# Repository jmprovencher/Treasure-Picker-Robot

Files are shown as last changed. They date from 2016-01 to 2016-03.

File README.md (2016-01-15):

Dépot cool de l'équipe cool.
J'propose le nom "Zière" parce que c'est qu'il faut rester zen pis la bière ça aide. C'est non négotiable jusqu'à ce que quelqu'un modifie le README.

Jusqu'à contre indication, rajoutez vos textes dans votre dossier personnel afin d'éviter les chiages de merge. Ça devrait nous permettre de rester zen pendant au moins une semaine.

Tâches actuelles:
> recherche sur pas mal tout le matériel à utiliser
> créer le GANTT

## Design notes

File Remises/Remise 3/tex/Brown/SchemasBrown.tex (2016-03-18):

\section{Circuit d'alimentation}
\label{s:Alimentation}

\section{Circuit d'amplification du code Manchester}
\label{s:Manchester}

%\begin{figure}[htp]
%   \centering
%   \includegraphics[width=0.85\textwidth]{fig/Manchester.png}
%   \caption{Circuit d'amplification des signaux du code Manchester}
%   \label{f:Manchester}
%\end{figure}

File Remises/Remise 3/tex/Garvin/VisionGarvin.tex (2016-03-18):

%Exemple d'insertion de figure

%\begin{figure}[htp]
%   \centering
%   \includegraphics[width=1\textwidth]{fig/trajet.png}
%   \caption{Exemple de trajectoire}
%   \label{f:Trajectoire}
%\end{figure}
%\pagebreak

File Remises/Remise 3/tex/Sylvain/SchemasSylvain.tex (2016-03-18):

\section{Station de recharge}
\label{s:Recharge}

\section{Circuit de charge et de décharge du condensateur}
\label{s:Condensateur}

\section{Circuit de connections pour les moteurs}
\label{Connections}

\subsection{Connections moteurs et pont en H}
\label{Moteurs}

\subsection{Connections sur l'Arduino}
\label{Arduino}

%\begin{figure}[htp]
%   \centering
%   \includegraphics[width=0.85\textwidth]{fig/Manchester.png}
%   \caption{Circuit d'amplification des signaux du code Manchester}
%   \label{f:Manchester}
%\end{figure}

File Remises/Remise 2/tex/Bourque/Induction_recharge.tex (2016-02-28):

L’électroaimant est alimenté par un condensateur. Ce dernier est rechargé par un transformateur. Le primaire du transformateur est situé sur la station de recharge sur le bord de la table. Il est alimenté par la tension DC de 5V/3A qui provient du circuit fournissant aussi le signal Manchester. Le transformateur ne fonctionnant qu’en AC, il est nécessaire de hacher cette tension DC. 
\medbreak
Plusieurs méthodes existent pour hacher une tension DC. Il fut choisi d’utiliser un simple MOSFET de puissance dans lequel la base est commandée par une horloge. Ce choix a été fait pour sa simplicité. Il est en effet beaucoup plus simple à implémenter qu'un pont en H. Également, avec un seul MOSFET, les pertes par dissipation dans les MOSFETs sont limitées. L'horloge provient d'un microprocesseur PIC situé également sur la station de recharge. Différentes fréquences ont été testées pour ce hacheur. Les fréquences inaudibles (plus de 20kHz) sont plus intéressantes, car notre oreille ne peut pas les entendre et le transformateur n'est donc pas bruyant. Toutefois, à ces fréquences, l'effet inductif des bobines du transformateur devient très grand et réduit le courant qui traverse le transformateur. 
\medbreak
Comme un plus grand courant dans le transformateur équivaut à une recharge plus rapide du condensateur, une fréquence de 4kHz a été choisie. C'est à cette fréquence que l'effet inductif des bobines du transformateur devient assez faible pour laisser passer un courant dans le transformateur assez grand pour avoir une recharge rapide du condensateur. De plus, si on descend à une fréquence plus basse que 4kHz, l'effet inductif du transformateur devient très faible; un courant trop élevée y circule et les deux bobines s'attirent fortement par aimantation. C'est pourquoi la fréquence de 4kHz est choisie.
\medbreak
Toutefois, un condensateur ne peut être rechargé par une tension alternative. C'est pourquoi au secondaire se trouve un redresseur. Des tests ont été faits afin de choisir entre un redresseur simple alternance ou double alternance. Le redresseur double alternance a été choisi, parce qu'il est plus efficace.
\medbreak
Le condensateur choisi est un condensateur de 5F. Avec notre système d'induction, il est possible de charger ce condensateur jusqu'à 5V. Des tests ont été faits avec ce condensateur et ont permis de déterminer qu'à partir de sa pleine charge, il est capable d'alimenter notre électroaimant avec le courant nécessaire pour tenir un trésor pendant 3 minutes 30 secondes, ce qui est amplement suffisant pour le projet.
\medbreak
Finalement, un interrupteur électronique est utilisé pour ouvrir le circuit de recharge lorsque la recharge est complétée; sans cela, un faible courant de fuite circule dans le pont redresseur et décharge lentement le condensateur. La figure \ref{f:Borne} présente le schéma électrique du système implanté sur le robot.

\begin{figure}[htp]
   \centering
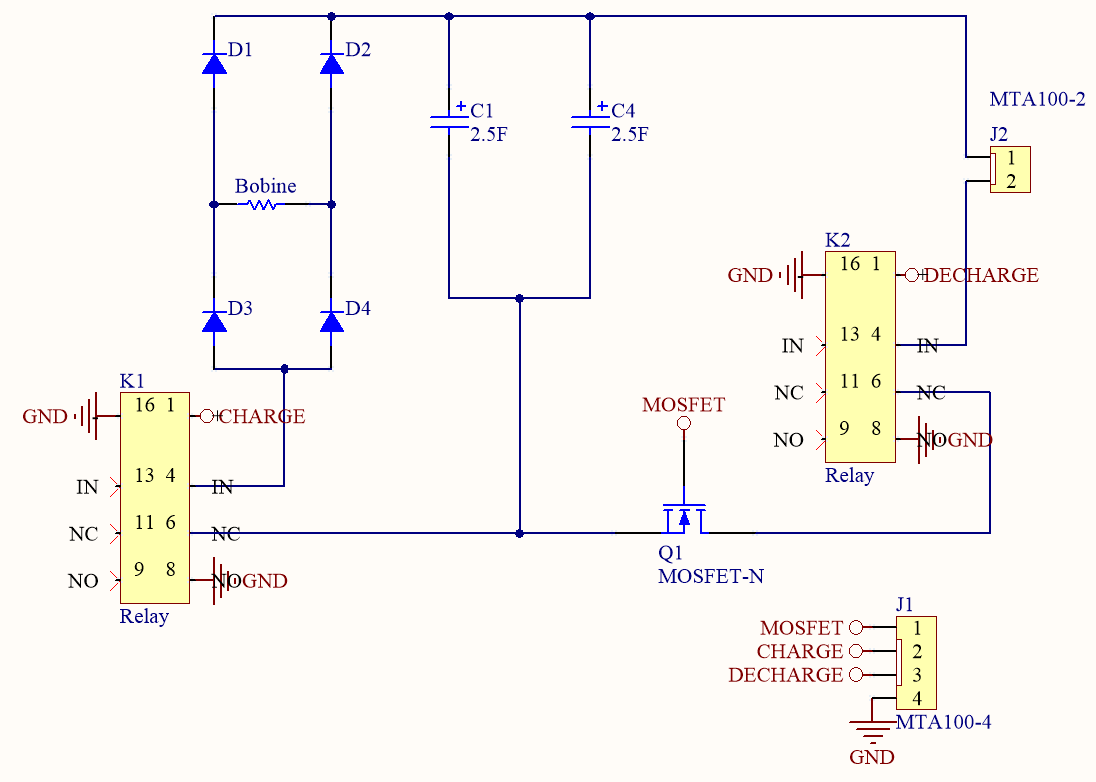
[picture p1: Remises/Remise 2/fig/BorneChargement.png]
   
   \caption{Circuit de chargement et décharge du condensateur}
   \label{f:Borne}
\end{figure}

\pagebreak

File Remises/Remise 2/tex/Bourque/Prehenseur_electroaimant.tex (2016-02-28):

Le préhenseur est constitué d'un électroaimant situé sur un bras mécanique. Cet électroaimant est alimenté par le condensateur de 5F. Lorsqu'un courant circule dans l'électroaimant, il produit une force d'attraction des trésors. Afin de conserver l’énergie dans le condensateur le plus longtemps possible, le courant de décharge dans l’électroaimant doit être limité. En effet, sans cela, le condensateur se déchargera extrêmement rapidement dans l'aimant, car sa résistance interne est de 12 ohms. L'électroaimant est acheté afin de s'assurer d'avoir une bonne efficacité de ce système et d'éviter la tâche d'en concevoir un \cite{PRE00}.
\medbreak
Afin de limiter ce courant, nous utilisons un MOSFET dans lequel nous envoyons une onde carré de largeur d’impulsion variable dans sa base et permet de contrôler ce courant. Un fort courant doit d'abord être envoyé dans l'aimant afin d'attirer le trésor. Ensuite, le circuit magnétique est fermé et un courant plus faible peut donc être envoyé. Cette façon de procéder est donc utilisée afin de conserver l'énergie du condensateur plus longtemps.
\medbreak
Également, le système comprend un interrupteur électronique afin de permettre de couper la décharge de courant dans l’électroaimant lorsque le déplacement vers l'île cible est terminé. En ouvrant l’interrupteur, il n'y a plus de courant dans l'électroaimant et la force qui permet de tenir le trésor est éliminée. Le trésor tombe ainsi sur l'île voulue.

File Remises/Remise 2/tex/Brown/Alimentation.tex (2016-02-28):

Un circuit imprimé est conçu pour assurer un accès facile aux différents niveaux de tensions requis par le robot. Ce circuit comprend donc les deux régulateurs nécessaires pour le 12V, le régulateur pour les circuits fonctionnant à 5V ainsi que le régulateur 19V pour le mini PC. Les deux régulateurs utilisés pour le 12V sont le même modèle que celui utilisé pour le 5V. Le régulateur en question est un hacheur série dévolteur DC-DC avec un voltmètre intégré qui a une précision de $\pm$ 0.05V \cite{ALI01}. Il nécessite 4V à 38V en entré et peut fournir 1.35V à 36V en sortie avec un courant maximum de 5A et son efficacité peut atteindre 96\%. De plus, il possède une protection intégrée contre la surchauffe et les courts-circuits. Les autres régulateurs considérés pour le robot ne pouvaient fournir que 3A et ils coûtaient environ le même prix, c'est cette raison qui a fait pencher le choix vers ce régulateur. Le voltmètre intégré qui affiche la tension d'entrée ou de sortie n'était pas un critère, mais puisque ce n'est pas encombrant, c'est seulement un avantage. 
\medbreak
La batterie choisie est une LiPO 6S à 4.5Ah de Turnigy \cite{ALI00}. Le choix s'est arrêté sur une 6S pour avoir 22.2V en moyenne, car il est nécessaire d'avoir au moins 21V pour alimenter le régulateur du mini PC. De plus, il fut précédemment calculé que le robot avait besoin d'environ 110W pendant le 10 minutes imposé pour la compétition, mais il était préférable d'avoir au moins 30 minutes d'autonomie pour faciliter les tests. Le choix s'est arrêté sur une batterie de 4.5Ah, ce qui donne 600W, pour environ 50 minutes d'autonomie. Le choix de prendre deux batteries pour effectuer plus de tests sans recharge fut considéré, mais un problème de livraison et d'importation avec le fournisseur a éliminé cette option.
\medbreak
La figure \ref{f:alim2} présente le schéma électrique du circuit d'alimentation. On peut y remarquer les protections électriques sous forme de fusibles ce qui permet de protéger nos appareils.

\begin{figure}[htp]
   \centering
   
   \caption{Schéma électrique du circuit imprimé}
   \label{f:alim2}
\end{figure}
\pagebreak

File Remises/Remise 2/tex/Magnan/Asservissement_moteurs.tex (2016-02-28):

Afin de contrôler les roues, la première étape est d'alimenter correctement chacun des moteurs des roues. Le pont en H connecté aux moteurs nécessite trois entrées par roue: deux entrées servent à sélectionner la direction des roues, et une troisième reçoit un PWM déterminant la vitesse de rotation de la roue.
\medbreak
Le pont en H est alimenté à l'aide d'une alimentation 5V provenant du système d'alimentation. Les encodeurs des roues en tant que tels doivent par contre être alimentés à une tension entre 3.5 et 20V et sont donc alimentés par la même source. Selon les spécifications du pont en H, la pin 1 de chaque moteur doit recevoir une tension faible et la pin 2 une tension élevée pour tourner la roue associée dans le sens des aiguilles d'une montre. Afin de tourner dans le sens inverse, il faut alors utiliser une tension élevée sur 1 et faible sur 2. Un des premiers tests est alors effectué, avec le pont en H alimenté et les quatre roues à pleine vitesse. À l'aide de ce test, il fut facile de voir que le branchement des roues de même orientation devrait être de deux sens opposés, car le sens des aiguilles signifie une rotation différente d'un côté à l'autre du robot.
\medbreak
Par la suite, en utilisant des sorties PWM de l'Arduino Mega, des ondes carrées à rapport cyclique de 50\% sont envoyées en sortie. Celles-ci, lorsque connectées aux entrées de vitesse correspondant aux quatre moteurs dans le pont en H, permettent de comparer la vitesse des moteurs et de vérifier si celle-ci est constante. Résultat de ce test: en activant deux roues à la fois, le robot ne va pas en ligne droite. Le moteur 1 fait tourner la roue significativement plus rapidement que le moteur 3 avec la même commande. Un asservissement avec intégrateur est donc absolument nécessaire afin que la vitesse de chaque roue rejoigne la consigne, permettant au robot de rouler en ligne droite.
\medbreak
La libraire PID disponible sur le Playground Arduino permet de rapidement implémenter un asservissement avec une fréquence d’échantillonnage, une commande à rejoindre et des paramètres kp, ki et kd définis par l'utilisateur. Pour implémenter la commande à rejoindre, les encodeurs des moteurs sont branchés directement à des entrées numériques du microcontrôleur Arduino. En effet, ceux-ci génèrent une onde carrée à largeur variable, celle-ci pouvant être lue en utilisant la fonction pulseIn(). La durée de lecture maximale (timeout) de la largeur d'impulsion est à la base très lente, environ une seconde par lecture, ce qui rend l'asservissement peu efficace si le robot tourne lentement. Pour remédier à cette situation, un timeout de 3 ms a été choisi.
\medbreak
Avec pulseIn, lorsque aucune onde n'est détectée avant la fin du temps maximal, une valeur de 0 est retournée. Par contre, l'asservissement fonctionne avec un principe que lorsque la durée retournée par pulseIn est supérieure à la commande, il faut augmenter la sortie vers les moteurs. Afin d'assurer qu'une roue à l'arrêt ne soit pas considérée comme impossiblement rapide, une valeur de 0 est remplacée par la durée maximale de lecture, soit 3 ms.
\medbreak
Les tests initiaux de l'asservissement étaient peu fructueux. En effet, la sortie du PID variait beaucoup trop rapidement entre minimum et maximum, ne permettant que très peu de précision. Ceci était dû à un kp trop élevé, ce qui multipliait l'erreur bien au delà de la valeur maximale du paramètre du PWM, soit 255. En diminuant l'élément proportionnel kp à 0.0005 au lieu de 1, la variation cyclique due à un trop large dépassement est évitée. Le ki est présentement à 0.25 car il permet de rejoindre la consigne suffisamment rapidement sans créer de trop larges dépassements.

\begin{figure}[htp]
	\centering
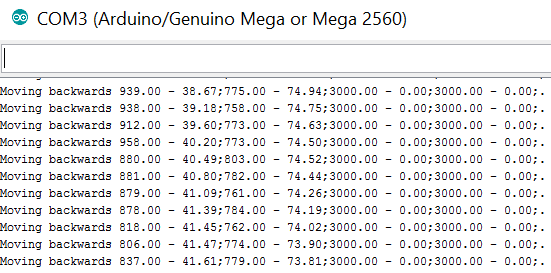
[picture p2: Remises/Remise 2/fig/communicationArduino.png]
	
	\caption{Test de rotation sur deux roues, commande à rejoindre de 800 microsecondes de largeur d'impulsion} 
	\label{f:test_Arduino}
\end{figure}

Dans l'état actuel de ce sous-système, il y a dépassement en vitesse de plus de 10\% pendant environ une seconde. Afin de permettre des déplacements plus précis, du travail sera fait pour diminuer ce dépassement. Pour communiquer à l'Arduino Mega la consigne à rejoindre, une interruption sur le port série est implémentée en utilisant serialEvent. Lorsque le port série détecte qu'il y a quelque chose à lire sur le port série, le code de lecture de la commande prend alors priorité sur l'exécution du PID.

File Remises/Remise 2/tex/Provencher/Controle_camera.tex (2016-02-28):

Le contrôle de la caméra embarquée s'effectue par des servomoteurs contrôlés par le Micro Maestro 6-Channel USB Servo Controller. Afin de simplifier les commandes nécessaires au contrôle de la position de la caméra, quatre positions prédéterminées ont été programmées : gauche, droite, avant, trésor. Comme ces quatre positions permettent de couvrir entièrement le champ de vision intéressant, il n'est pas nécessaire d'ajouter davantage de possibilités de contrôle de caméra. La position trésor correspond à la position avant dans laquelle la caméra regarde complètement vers le bas. Afin de déterminer ces positions, le logiciel Maestro Control Center a été utilisé pour noter les valeurs nominales de ces positions. Une fois les valeurs de position en main, une librairie Arduino a été développée afin de déplacer la position de la caméra dans ces différentes valeurs.
\medbreak
Pour communiquer entre le Arduino Mega 2560 et le contrôleur de servomoteur, une communication UART est établie afin de pouvoir envoyer les commandes de positions au contrôleur de servomoteur. Comme il n'est pas nécessaire de recevoir de l'information de la part du contrôleur de servomoteur, uniquement la branche TX du Arduino Mega est utilisée. Le contrôleur de servomoteur est également relié au module d'alimentation afin de fournir le courant nécessaire aux servomoteurs.

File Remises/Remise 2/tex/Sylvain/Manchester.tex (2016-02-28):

Le système de transmission retenu par l'équipe pour communiquer le signal Manchester est un système utilisant une LED comme émetteur et une autre LED comme récepteur. Ce système LED à LED est une solution simple et peu coûteuse qui ne présente donc pas un coût monétaire important pour le projet ni beaucoup de temps de travail. Pour décoder le code il est nécessaire de transmettre l'horloge ainsi que le code, le système est donc installé en double à cet effet. Chacun des signaux est transmis par un banque de quatre LED qui seront situées sur la station de recharge. L'utilisation de plusieurs diodes est justifiée pour rendre le système plus efficace en cas de défaillance d'une de celle-ci et donc d'ajouter de la redondance. Les LED en réception sont situées de chaque côté de la face avant du robot de manière à éviter les interférences. Encore une fois, la redondance est utilisée pour la réception et deux LED sont donc placées à cet effet.
\medbreak
L'horloge fournit avec le dispositif du Manchester n'est pas utilisée car elle est jugée trop rapide, une horloge d'environ 1 à 2Hz est généré par un microcontrôleur PIC. Une fréquence plus élevée n'est pas requise dû au temps passé à recharger le condensateur, de plus, avec une basse fréquence le risque d'erreur est jugé moins élevé. Des LED rouges sont utilisées pour la transmission des signaux, après des expériences avec d'autres couleurs il fut remarqué que celles-ci offraient les meilleures performances.
\medbreak
Un circuit d'amplification des signaux situé sur le robot permet d'amplifier ceux-ci après réception et donc de produire des signaux 0 à 5V. Le schéma de ce circuit est présenté à la figure \ref{f:Manchester} et réalisé sur PCB conformément aux exigences. Les signaux amplifiés sont ensuite lu par des entrées numériques de l'Arduino Mega. La signal d'horloge est lu par une entrée permettant d'utiliser les interruptions tandis que le code Manchester est lu par une entrée ordinaire. Une interruption est lancée sur chaque front montant d'horloge, les deux données sont alors lues et on effectue une opération XOR sur les signaux afin d'obtenir le signal décodé. Ce résultat est ensuite stocké dans un buffer circulaire de 32 éléments, ce qui assure d'avoir au moins une itération de la séquence de 16 bits dans son ensemble. Un algorithme parcours ensuite ce tableau de données pour recherché la séquence de 8 bits à 1 suivit d'un bit à 0 pour finalement prendre les 7 bits d'intérêt composant la lettre ASCII voulue. Cette lettre est finalement transmise à l'ordinateur embarquée pour utilisation future.

\begin{figure}[htp]
   \centering
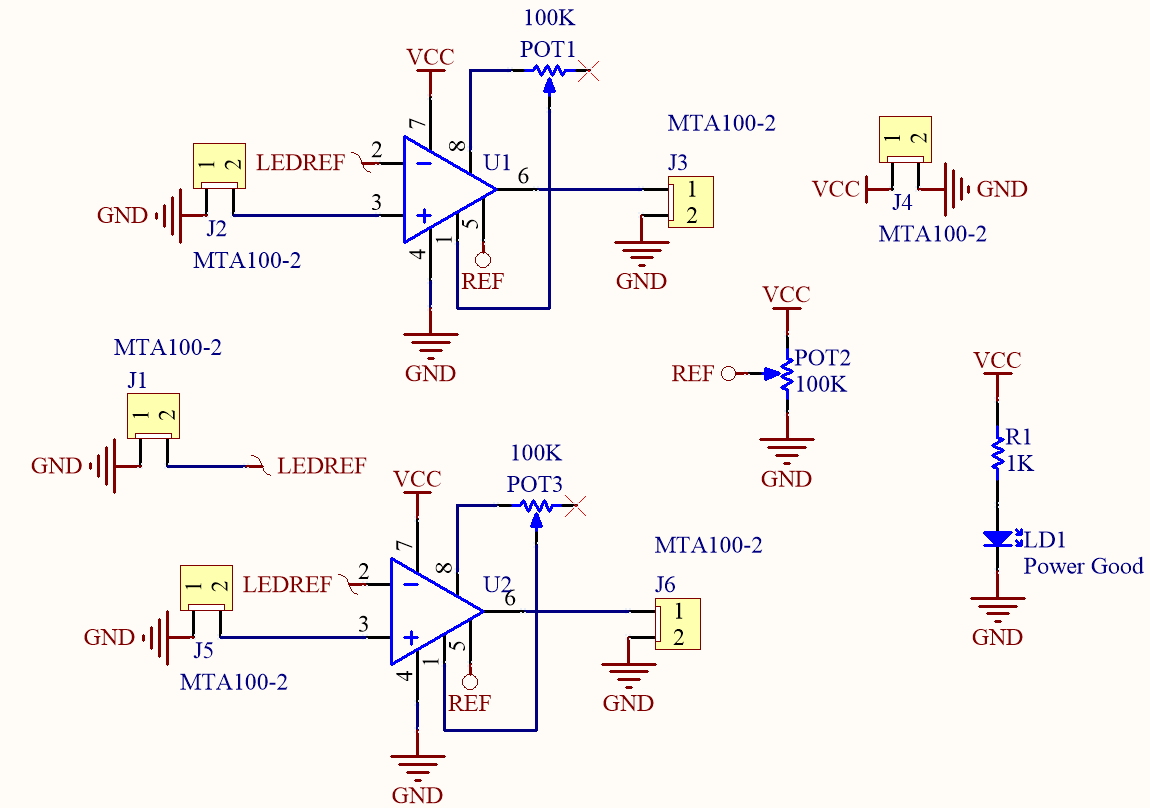
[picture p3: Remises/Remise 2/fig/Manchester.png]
   
   \caption{Circuit d'amplification des signaux du code Manchester}
   \label{f:Manchester}
\end{figure}

\pagebreak

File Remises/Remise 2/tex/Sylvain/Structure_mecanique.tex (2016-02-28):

L'un des points important de l'aspect physique du robot est d'avoir un centre de gravité assez bas pour éviter à celui-ci de basculer en cas de départ brusque. Un poids assez important pour coller le robot au sol est aussi important pour ce point. Pour atteindre cet objectif il serait idéal de placer l'ordinateur embarqué sur l'étage inférieur puisqu'il est le système le plus lourd. Il fut cependant décidé de le placer sur l'étage au-dessus afin de libérer cet étage pour placer l'électronique et la batterie, réduisant ainsi la longueur des fils nécessaires pour se rendre aux moteurs par exemple.
\medbreak
Un autre point important est d'assurer un support solide aux circuits électroniques ainsi qu'à la batterie. À cet effet une feuille de contreplaqué est installée sur l'étage inférieur afin de visser les circuits sur celle-ci. Bien évidemment des trous pour des vis sont intégrés aux circuits et la feuille elle-même est fixée à la base du robot. L'interrupteur principal de l'alimentation est monté sur le côté du robot de façon à être accessible facilement. Les fusibles sont disposés pour pouvoir être changés facilement en cas de besoin. On minimise ainsi l'espace perdu sur le robot.

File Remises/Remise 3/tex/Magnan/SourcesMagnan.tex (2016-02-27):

\bibitem{MEG00} Robotshop, \textit{Arduino Mega 2560 Microcontroller}, [En ligne], \url{http://www.robotshop.com/ca/en/arduino-mega-2560-microcontroller-rev3.html}, Page consultée le 30 janvier 2016

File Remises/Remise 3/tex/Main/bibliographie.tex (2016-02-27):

%!TEX encoding = IsoLatin

%
% Chapitre "Introduction"
%

%Sites d'achats, factures, etc

\begin{thebibliographyUL}{99} % remplacer le "{9}" par "{99}" lorsque le nombre de references
                              % requiert 2 caracteres (>= 10 references)
\bibitem{COM00} ETH Zurich, \textit{An LED-to-LED Visible Light Communication System with Software-Based Synchronization}, [En ligne], \url{http://people.inf.ethz.ch/schmist/papers/OWC12Slides.pdf}, Page consultée le 27 janvier 2016

\input{tex/Magnan/SourcesMagnan.tex}

\bibitem{ALI00} HobbyKing.com, \textit{Turnigy 4500mAh 6S 30C Lipo Pack}, [En ligne], \url{http://www.hobbyking.com/hobbyking/store/__10284__Turnigy_4500mAh_6S_30C_Lipo_Pack.html}, Page consultée le 30 janvier 2016

\bibitem{ALI01} ebay.ca, \textit{DC-DC Step-down Buck Converter Adjustable Power 4V-38V to 1.25V-36V 5A Voltmeter}, [En ligne], \url{http://www.ebay.ca/itm/171445007919?_trksid=p2057872.m2749.l2649&ssPageName=STRK\%3AMEBIDX\%3AIT}, Page consulté le 30 janvier 2016

\bibitem{PRE00} Robotshop.com, \textit{Grove Electromagnet}, [En ligne], \url{http://www.robotshop.com/ca/en/grove-electromagnet.html}, Page consultée le 30 janvier 2016

\end{thebibliographyUL}

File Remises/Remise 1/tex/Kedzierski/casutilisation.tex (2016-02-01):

\pagebreak
\section{Scénarios des cas d'utilisation}
	%%%%%%%%%%%%%%% CAS UTILISATION 1 %%%%%%%%%%%%%%%%%
	%%%%%%%%%%% Identifier les éléments cartographiques  %%%%%%%%%%%%%
	%%%%%%%%%%%%% ETAT: COMPLET %%%%%%%%%%%%%%%%%%%%%%
    \begin{table}[!ht]
    \caption{Cas d'utilisation - Identifier les éléments cartographiques}
    \begin{tabular}{| l | p{4.75cm} p{4.75cm} |}
    \hline
    Cas d'utilisation & \multicolumn{2}{p{9.5cm} |}{Identifier les éléments cartographiques} \\ \hline
    Système & \multicolumn{2}{p{9.5cm} |}{Système de reconnaissance visuelle}\\ \hline
    Acteurs & \multicolumn{2}{p{9.5cm} |}{Robot, caméra world, station de base}\\ \hline
    Partie prenante et intérêt & \multicolumn{2}{p{9.5cm} |}{Station de base : Vouloir identifier les éléments présents sur la carte afin que le robot puisse remplir son mandat sans entrer en collision avec quoi que ce soit.}\\ 
    \hline
    Préconditions & \multicolumn{2}{p{9.5cm} |}{Le robot et la caméra world doivent fournir des images à la station de base}\\ \hline
    Garantie en cas de succès & \multicolumn{2}{p{9.5cm} |}{Les éléments cartographiques sont affichés sur la carte de la station de base}\\ \hline
    
    \multirow{4}{*}{Scénario principal} 
    
    & 1. La caméra world envoie des images à la station de base & \\
    & & 2. La surface de jeu, les îles, le robot, ainsi que les trésors visibles sont identifiés par le système de reconnaissance visuelle \\
    & 3. Le robot envoie des images à la station de base & \\
    & & 4. Le système de reconnaissance visuelle analyse ces images pour valider les positions des trésors\\
    
    \hline
    
    \multirow{1}{*}{Scénarios alternatifs} 
    
    & Aucun scénario alternatif & \\
    
    \hline
    \end{tabular}
    \label{tab:identifier_elements_cartes}
    \end{table}

	%%%%%%%%%%%%%%% CAS UTILISATION 2 %%%%%%%%%%%%%%%%%
	%%%%%%%%%%% Trouver station de recharge  %%%%%%%%%%%%%
	%%%%%%%%%%%%% ETAT: COMPLET %%%%%%%%%%%%%%%%%%%%%%
    \begin{table}[!ht]
    \caption{Cas d'utilisation - Trouver la station de recharge}
    \begin{tabular}{| l | p{4.75cm} p{4.75cm} |}
    \hline
    Cas d'utilisation & \multicolumn{2}{p{9.5cm} |}{Trouver station de recharge} \\ \hline
    Système & \multicolumn{2}{p{9.5cm} |}{Système de reconnaissance visuelle}\\ \hline
    Acteurs & \multicolumn{2}{p{9.5cm} |}{Robot, caméra world, station de base}\\ \hline
    Partie prenante et intérêt & \multicolumn{2}{p{9.5cm} |}{Robot : Faire le plein d'énergie et recevoir le code Manchester}\\ 
    \hline
    Préconditions & \multicolumn{2}{p{9.5cm} |}{La station de base a identifié la position de la station de recharge et une trajectoire a été calculée}\\ \hline
    Garantie en cas de succès & \multicolumn{2}{p{9.5cm} |}{La trajectoire menant le robot jusqu'à la station de recharge est affichée sur la carte de la station de base. Le robot se déplace vers la station de recharge sans toucher à aucun obstacle.}\\ \hline
    
    \multirow{4}{*}{Scénario principal} 
    
    & 1. La caméra world et le robot envoient des images à la station de base & \\
    & & 3. Le système de reconnaissance visuelle analyse ces images et determine l'emplacement de la station de recharge\\
    & & 4. Un itinéraire vers la station de recharge peut être calculé\\
    
    \hline
    
    \multirow{1}{*}{Scénarios alternatifs} 
    
    & & 3-1. Le système de reconnaissance visuelle analyse ces images et ne peut determiner l'emplacement de la station de recharge\\
    & & 4. La station de base ordonne un déplacement aléatoire au robot\\
    & 5. Le robot se déplace et renvoie des images à la station de base & \\
        
    \hline
    \end{tabular}
    \label{tab:trouver_station_recharge}
    \end{table}
    
	%%%%%%%%%%%%%%% CAS UTILISATION 3 %%%%%%%%%%%%%%%%%
	%%%%%%%%%%% Identifier la position des trésors  %%%%%%%%%%%%%
	%%%%%%%%%%%%% ETAT: COMPLET %%%%%%%%%%%%%%%%%%%%%%
    \begin{table}[!ht]
    \caption{Cas d'utilisation - Identifier la position des trésors}
    \begin{tabular}{| l | p{4.75cm} p{4.75cm} |}
    \hline
    Cas d'utilisation & \multicolumn{2}{p{9.5cm} |}{Identifier la position des trésors} \\ \hline
    Système & \multicolumn{2}{p{9.5cm} |}{Système de reconnaissance visuelle}\\ \hline
    Acteurs & \multicolumn{2}{p{9.5cm} |}{Robot, caméra world, station de base}\\ \hline
    Partie prenante et intérêt & \multicolumn{2}{p{9.5cm} |}{Robot : Identifier les positions des trésors cachés sur la table de jeu, afin de se déplacer jusqu'à l'un d'eux et le rapatrier sur l'île cible.}\\ 
    \hline
    Préconditions & \multicolumn{2}{p{9.5cm} |}{La station de base reçoit des images venant de la caméra world ainsi que celle du robot}\\ \hline
    Garantie en cas de succès & \multicolumn{2}{p{9.5cm} |}{Les trésors sont identifiés sur la carte de la station de base et un trésor cible est choisit parmi ceux-ci. Le robot se dirigera vers ce trésor cible pour le déplacer jusqu'à l'île cible.}\\ \hline
    
    \multirow{4}{*}{Scénario principal} 
    
    & 1. La caméra world et le robot envoient des images à la station de base & \\
    & & 2. Les trésors visibles sont identifiés et une trajectoire est calculée \\
    & 3. Le robot se déplace jusqu'au trésor & \\
    
    \hline
    
    \multirow{1}{*}{Scénarios alternatifs} 
    
    & & 2-1. Aucun trésor n'est identifié \\
    & & 3. La station de base ordonne un déplacement aléatoire au robot\\
    & 4. Le robot se déplace et renvoie des images à la station de base & \\
    
    \hline
    \end{tabular}
    \label{tab:identifier_tresor}
    \end{table}

	%%%%%%%%%%%%%%% CAS UTILISATION 4 %%%%%%%%%%%%%%%%%
	%%%%%%%%%%% Identifier les attributs des îles %%%%%%%%%%%%%
	%%%%%%%%%%%%% ETAT: COMPLET %%%%%%%%%%%%%%%%%%%%%%
    \begin{table}[!ht]
    \caption{Cas d'utilisation - Identifier les attributs des îles}
    \begin{tabular}{| l | p{4.75cm} p{4.75cm} |}
    \hline
    Cas d'utilisation & \multicolumn{2}{p{9.5cm} |}{Identifier les attributs des îles} \\ \hline
    Système & \multicolumn{2}{p{9.5cm} |}{Système de reconnaissance visuelle}\\ \hline
    Acteurs & \multicolumn{2}{p{9.5cm} |}{Robot, caméra world, station de base}\\ \hline
    Partie prenante et intérêt & \multicolumn{2}{p{9.5cm} |}{Robot : Identifier la couleur, la forme ainsi que la position des îles pour calculer une trajectoire valide. }\\ 
    \hline
    Préconditions & \multicolumn{2}{p{9.5cm} |}{La station de base reçoit des images venant de la caméra world}\\ \hline
    Garantie en cas de succès & \multicolumn{2}{p{9.5cm} |}{La couleur, la forme ainsi que la position des îles sont affichées sur la carte de la station de base. Une trajectoire vers un trésor peut par la suite être calculée.}\\ \hline
    
    \multirow{4}{*}{Scénario principal} 
    
    & 1. La caméra world envoie des images à la station de base & \\
    & & 2. La couleur, la forme et la position des îles sont identifiées par le système de reconnaissance visuelle \\   
    
    \hline
    
    \multirow{1}{*}{Scénarios alternatifs} 
    
    & Aucun scénario alternatif & \\
    
    \hline
    \end{tabular}
    \label{tab:identifier_iles}
    \end{table}

	%%%%%%%%%%%%%%% CAS UTILISATION 5 %%%%%%%%%%%%%%%%%
	%%%%%%%%%%% Identifier la position de l'île cible %%%%%%%%%%%%%
	%%%%%%%%%%%%% ETAT: COMPLET %%%%%%%%%%%%%%%%%%%%%%
    \begin{table}[!ht]
    \caption{Cas d'utilisation - Identifier la position de l'île cible}
    \begin{tabular}{| l | p{4.75cm} p{4.75cm} |}
    \hline
    Cas d'utilisation & \multicolumn{2}{p{9.5cm} |}{Identifier la position de l'île cible} \\ \hline
    Système & \multicolumn{2}{p{9.5cm} |}{Système de reconnaissance visuelle}\\ \hline
    Acteurs & \multicolumn{2}{p{9.5cm} |}{Robot, caméra world, station de base}\\ \hline
    Partie prenante et intérêt & \multicolumn{2}{p{9.5cm} |}{Robot : Une fois en possession d'un trésor, le robot déplacera le trésor jusqu'à l'île cible et déposera le trésor sur celle-ci.}\\ 
    \hline
    Préconditions & \multicolumn{2}{p{9.5cm} |}{Le code Manchester contenant l'information sur l'île cible a été décodé et transmis à la station de base. Les attributs des îles ont été identifiés avec succès.}\\ \hline
    Garantie en cas de succès & \multicolumn{2}{p{9.5cm} |}{Une fois la récupération d'un trésor terminée, une trajectoire vers l'île cible peut être calculée.}\\ \hline
    
    \multirow{4}{*}{Scénario principal} 
    
    & 1. L'information envoyé par le serveur des îles est transmise à la station de base par le robot & \\
    & & 2. L'emplacement de l'île cible est identifié par le système de reconnaissance visuelle \\
    
    \hline
    
    \multirow{1}{*}{Scénarios alternatifs} 
    
    & Aucun scénario alternatif, l'identification de l'île cible doit toujours être réussie & \\
    
    \hline
    \end{tabular}
    \label{tab:identifier_iles_cible}
    \end{table}
    
    %%%%%%%%%%%%%%% CAS UTILISATION 6 %%%%%%%%%%%%%%%%%
	%%%%%%%%%%% Décoder le code Manchester %%%%%%%%%%%%%
	%%%%%%%%%%%%% ETAT: COMPLET %%%%%%%%%%%%%%%%%%%%%%
    \begin{table}[!ht]
    \caption{Cas d'utilisation - Décoder le code Manchester}
    \begin{tabular}{| l | p{4.75cm} p{4.75cm} |}
    \hline
    Cas d'utilisation & \multicolumn{2}{p{9.5cm} |}{Décoder le code Manchester} \\ \hline
    Système & \multicolumn{2}{p{9.5cm} |}{Ordinateur embarqué}\\ \hline
    Acteurs & \multicolumn{2}{p{9.5cm} |}{Robot, caméra world, station de base}\\ \hline
    Partie prenante et intérêt & \multicolumn{2}{p{9.5cm} |}{Robot : Une fois le code reçu, il sera décodé et une requête au serveur des îles sera effectuée.}\\ 
    \hline
    Préconditions & \multicolumn{2}{p{9.5cm} |}{Le robot doit s'être rendu à la station de recharge, où le transfert du code Manchester a lieu.}\\ \hline
    Garantie en cas de succès & \multicolumn{2}{p{9.5cm} |}{Le message contenant l'information sur l'île cible sera par la suite envoyé à la station de base pour déterminer l'itinéraire à emprunter une fois en possession d'un trésor.}\\ \hline
    
    \multirow{4}{*}{Scénario principal} 
    
    & 1. Le robot se déplace jusqu'à la station de base en suivant l'itinéraire calculé par la station de base & \\
    & & 2. Le code Manchester est transmis au robot pendant la recharge du condensateur \\
    & 3. Le robot décode le signal reçu & \\
    & & 4. Le robot effectue une requête au serveur des îles \\
    
    \hline
    
    \multirow{1}{*}{Scénarios alternatifs} 
    
    & Aucun scénario alternatif, le décodage du code Manchester doit toujours être réussi & \\    
    
    \hline
    \end{tabular}
    \label{tab:decoder_code}
    \end{table}
   
    %%%%%%%%%%%%%%% CAS UTILISATION 7 %%%%%%%%%%%%%%%%%
	%%%%%%%%%%% Communiquer avec le serveur des îles %%%%%%%%%%%%%
	%%%%%%%%%%%%% ETAT: COMPLET %%%%%%%%%%%%%%%%%%%%%%
    \begin{table}[!ht]
    \caption{Cas d'utilisation - Communiquer avec le serveur des îles}
    \begin{tabular}{| l | p{4.75cm} p{4.75cm} |}
    \hline
    Cas d'utilisation & \multicolumn{2}{p{9.5cm} |}{Communiquer avec le serveur des îles} \\ \hline
    Système & \multicolumn{2}{p{9.5cm} |}{Ordinateur embarqué}\\ \hline
    Acteurs & \multicolumn{2}{p{9.5cm} |}{Robot}\\ \hline
    Partie prenante et intérêt & \multicolumn{2}{p{9.5cm} |}{Robot : Une fois la requête effectuée, l'information sur l'île cible est transmise à la station de base.}\\ 
    \hline
    Préconditions & \multicolumn{2}{p{9.5cm} |}{Le code Manchester doit avoir été décodé.}\\ \hline
    Garantie en cas de succès & \multicolumn{2}{p{9.5cm} |}{La station de base est en mesure de déterminer la position de l'île cible et une fois la récupération d'un trésor terminée, une trajectoire vers l'île cible peut être calculée.}\\ \hline
    
    \multirow{4}{*}{Scénario principal} 
    
    & 1. Le robot effectue une requête au serveur des îles en utilisant le message décodé & \\
    & & 2. Le serveur renvoie un message contenant l'information sur l'île cible \\
    & 3.  Cette information est transmise à la station de base \\
    
    \hline
    
    \multirow{1}{*}{Scénarios alternatifs} 
    
    & Aucun scénario alternatif & \\
    
    \hline
    \end{tabular}
    \label{tab:requete_serveur}
    \end{table}
    
%%%%%%%%%%%%%%% CAS UTILISATION 8 %%%%%%%%%%%%%%%%%
	%%%%%%%%%%% Déplacer le trésor %%%%%%%%%%%%%
	%%%%%%%%%%%%% ETAT: COMPLET %%%%%%%%%%%%%%%%%%%%%%
    \begin{table}[!ht]
    \caption{Cas d'utilisation - Déplacer le trésor}
    \begin{tabular}{| l | p{4.75cm} p{4.75cm} |}
    \hline
    Cas d'utilisation & \multicolumn{2}{p{9.5cm} |}{Déplacer le trésor} \\ \hline
    Système & \multicolumn{2}{p{9.5cm} |}{Système de reconnaissance visuelle}\\ \hline
    Acteurs & \multicolumn{2}{p{9.5cm} |}{Robot}\\ \hline
    Partie prenante et intérêt & \multicolumn{2}{p{9.5cm} |}{Robot : Se déplacer vers un trésor, le récupérer et le déposer sur une île cible afin de respecter le but du projet.}\\ 
    \hline
    Préconditions & \multicolumn{2}{p{9.5cm} |}{Le robot doit avoir fait le plein d'énergie à la station de recharge afin de soulever le trésor. L'île cible doit avoir été identifiée et une trajectoire valide doit être calculée pour se rendre jusqu'au trésor. Par la suite, une seconde trajectoire est calculée pour déposer le trésor sur l'île cible.}\\ \hline
    Garantie en cas de succès & \multicolumn{2}{p{9.5cm} |}{La station de base est en mesure de déterminer la position de l'île cible et une fois la récupération d'un trésor terminée, une trajectoire vers l'île cible peut être calculée.}\\ \hline
    
    \multirow{4}{*}{Scénario principal} 
    
    & 1. Le robot se déplace jusqu'à un trésor en suivant une trajectoire préalablement définie & \\
    & & 2. Le robot se positionne et soulève le trésor \\
    & 3. Le robot se déplace jusqu'à l'île cible & \\
    & & 4. Le robot se positionne et dépose le trésor au centre de l'île cible \\
    
    \hline
    
    \multirow{1}{*}{Scénarios alternatifs} 
    
    & & 2-1. Le robot se positionne, mais ne peut soulever le trésor \\
    & 3. Le robot se déplace jusqu'à la station de recharge & \\
    & & Le robot recharge le condensateur \\
    
    \hline
    \end{tabular}
    \label{tab:deplacer_tresor}
    \end{table}

%%%%%%%%%%%%%%% CAS UTILISATION 9 %%%%%%%%%%%%%%%%%
	%%%%%%%%%%% Afficher les informations sur l'état du robot %%%%%%%%%%%%%
	%%%%%%%%%%%%% ETAT: COMPLET %%%%%%%%%%%%%%%%%%%%%%
    \begin{table}[!ht]
    \caption{Cas d'utilisation - Afficher les informations sur l'état du robot}
    \begin{tabular}{| l | p{4.75cm} p{4.75cm} |}
    \hline
    Cas d'utilisation & \multicolumn{2}{p{9.5cm} |}{Afficher les informations sur l'état du robot} \\ \hline
    Système & \multicolumn{2}{p{9.5cm} |}{Station de base}\\ \hline
    Acteurs & \multicolumn{2}{p{9.5cm} |}{Station de base}\\ \hline
    Partie prenante et intérêt & \multicolumn{2}{p{9.5cm} |}{Station de base : Les informations critiques du robot peuvent être étudiées en temps réel.}\\ 
    \hline
    Préconditions & \multicolumn{2}{p{9.5cm} |}{Une communication doit être établie entre le robot et la station de base afin d'échanger ces informations.}\\ \hline
    Garantie en cas de succès & \multicolumn{2}{p{9.5cm} |}{Divers informations sont affichées sur la station de base.}\\ \hline
    
    \multirow{4}{*}{Scénario principal} 
    
    & 1. Le robot se déplace et communique avec la station de base & \\
    & & 2. La tension du condensateur est affichée sur la station de base \\
    & & 3. La vitesse de chaque moteur est affichée sur la station de base\\
    
    \hline
    
    \multirow{1}{*}{Scénarios alternatifs} 
    
    & 1-1. Le robot décode le code Manchester & \\
    & & 2. La lettre ASCII décodée est affichée sur la station de base \\
    & 3. Une requête est envoyée au serveur des îles \\
    & & 4. La forme et la couleur de l'île cible sont affichées sur la station de base \\
    
    \hline
    \end{tabular}
    \label{tab:info_robot}
    \end{table}

    %%%%%%%%%%%%%%% CAS UTILISATION 10 %%%%%%%%%%%%%%%%%
	%%%%%%%%%%% Afficher la carte de jeu %%%%%%%%%%%%%
	%%%%%%%%%%%%% ETAT: COMPLET %%%%%%%%%%%%%%%%%%%%%%
    \begin{table}[!ht]
    \caption{Cas d'utilisation - Afficher la carte de jeu}
    \begin{tabular}{| l | p{4.75cm} p{4.75cm} |}
    \hline
    Cas d'utilisation & \multicolumn{2}{p{9.5cm} |}{Afficher la carte de jeu} \\ \hline
    Système & \multicolumn{2}{p{9.5cm} |}{Système de reconnaissance visuelle}\\ \hline
    Acteurs & \multicolumn{2}{p{9.5cm} |}{Robot, caméra world, station de base}\\ \hline
    Partie prenante et intérêt & \multicolumn{2}{p{9.5cm} |}{Étudiants : Permet d'avoir une rétroaction rapide des résultats calculés par le système de reconnaissance visuelle.}\\ 
    \hline
    Préconditions & \multicolumn{2}{p{9.5cm} |}{La station de base doit recevoir des images provenant de la caméra world et celle du robot.}\\ \hline
    Garantie en cas de succès & \multicolumn{2}{p{9.5cm} |}{Les îles, les trésors, le robot ainsi que les itinéraires sont affichés sur la carte en temps réel.}\\ \hline
    
    \multirow{4}{*}{Scénario principal} 
    
    & 1. La caméra world envoie des images à la station de base & \\
    & & 2. La surface de jeu, les îles, le robot, ainsi que les trésors visibles sont affichés sur la carte de jeu en temps réel \\    
    \hline
    
    \multirow{1}{*}{Scénarios alternatifs} 
    
    & Aucun scénario alternatif & \\
    
    \hline
    \end{tabular}
    \label{tab:afficher_carte}
    \end{table}

	%%%%%%%%%%%%%%% CAS UTILISATION 11 %%%%%%%%%%%%%%%%%
	%%%%%%%%%%% Calculer les trajectoires %%%%%%%%%%%%%
	%%%%%%%%%%%%% ETAT: COMPLET %%%%%%%%%%%%%%%%%%%%%%
    \begin{table}[!ht]
    \caption{Cas d'utilisation - Calculer les trajectoires}
    \begin{tabular}{| l | p{4.75cm} p{4.75cm} |}
    \hline
    Cas d'utilisation & \multicolumn{2}{p{9.5cm} |}{Calculer les trajectoires} \\ \hline
    Système & \multicolumn{2}{p{9.5cm} |}{Système de reconnaissance visuelle}\\ \hline
    Acteurs & \multicolumn{2}{p{9.5cm} |}{Robot, caméra world, station de base}\\ \hline
    Partie prenante et intérêt & \multicolumn{2}{p{9.5cm} |}{Robot : Le robot doit se diriger en suivant une trajectoire prédéfinie, sans jamais entrer en contact avec quoi que ce soit.}\\ 
    \hline
    Préconditions & \multicolumn{2}{p{9.5cm} |}{La station de base doit recevoir des images provenant de la caméra world et celle du robot. La position de la destination doit être connue. Les destinations possibles sont la station de recharge, un trésor ou l'île cible.}\\ \hline
    Garantie en cas de succès & \multicolumn{2}{p{9.5cm} |}{Le robot se déplace en suivant l'itinéraire sans touché à un obstacle.}\\ \hline
    
    \multirow{4}{*}{Scénario principal} 
    
    & 1. Une destination est choisie & \\
    & & 2. Le système de reconnaissance visuelle analyse la carte de jeu et repère le robot \\
    & 3. Le système analyse les obstacles présents sur la carte & \\
    & & 4. Une trajectoire est calculée et transmise au robot \\    
    
    \hline
    
    \multirow{1}{*}{Scénarios alternatifs} 
    
    & Aucun scénario alternatif & \\
    
    \hline
    \end{tabular}
    \label{tab:calculer_trajectoire}
    \end{table}

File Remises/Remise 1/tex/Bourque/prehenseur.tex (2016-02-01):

Afin de rendre le préhenseur le plus simple possible mécaniquement, nous choisissons de le faire en forme d'équerre. Aux deux extrémités de l'équerre sont situés l'électroaimant et le secondaire du transformateur qui permet de charger le condensateur d'alimentation de l'électroaimant. Il devient donc très aisé d'aligner le système de recharge avec la station de recharge ainsi que de soulever les trésors en faisant tourner l'équerre de 90 degrés dans un sens ou dans l'autre. Cette rotation est assurée par un servomoteur situé au centre de l'équerre. La figure \ref{f:CAD} est une représentation du système mécanique du préhenseur. Le dessin 3D permet de se faire une bonne idée des dimensions du bras du préhenseur de manière à ce qu'il soit efficace. Un servomoteur présentant suffisamment de couple ($6.4Kg\cdot cm$ à 6V) permet d'actionner le préhenseur.

\medbreak

L'électroaimant est un modèle pré-fait acheté en ligne. Il s'agit du modèle \textit{Grove} de la compagnie \textit{seeed} (voir section \ref{liste_pieces}). Cet aimant peut soulever une charge de 1kg pour un courant de 400mA. Ce système vient aussi avec un système de contrôle réalisé à partir d'un transistor de commutation. En assumant que la force générée par l'aimant dépend quadratiquement du courant le parcourant et en sachant que le poids des trésors est de 30g l'unité, on estime le courant nécessaire pour soulever les trésors autour de 5mA. Pour avoir une marge de sécurité ainsi que de pouvoir attirer les trésors <<à distance>>, on augmente ce courant à 20mA. Le courant dans l'électroaimant est contrôlé par une source de courant à diode Zener (voir figure \ref{f:source_courant}).

\medbreak

L'énergie nécessaire pour soulever un trésor pendant 10 minutes par l'électroaimant est de 60J ($U = 5V \times 20mA \times 10min \times 60s / min$). Un condensateur de 0.5F à 5V contient 62.5J d'énergie ($U = 0.5 \times C \times V^2$). C'est donc cette valeur de condensateur qui est choisie pour alimenter l'électroaimant.

\medbreak

Afin de permettre de faire des tests ainsi que de s'assurer un degré de sécurité, un condensateur de 1F est également considéré dans le design de ce système.

\begin{figure}[htp]
	\centering
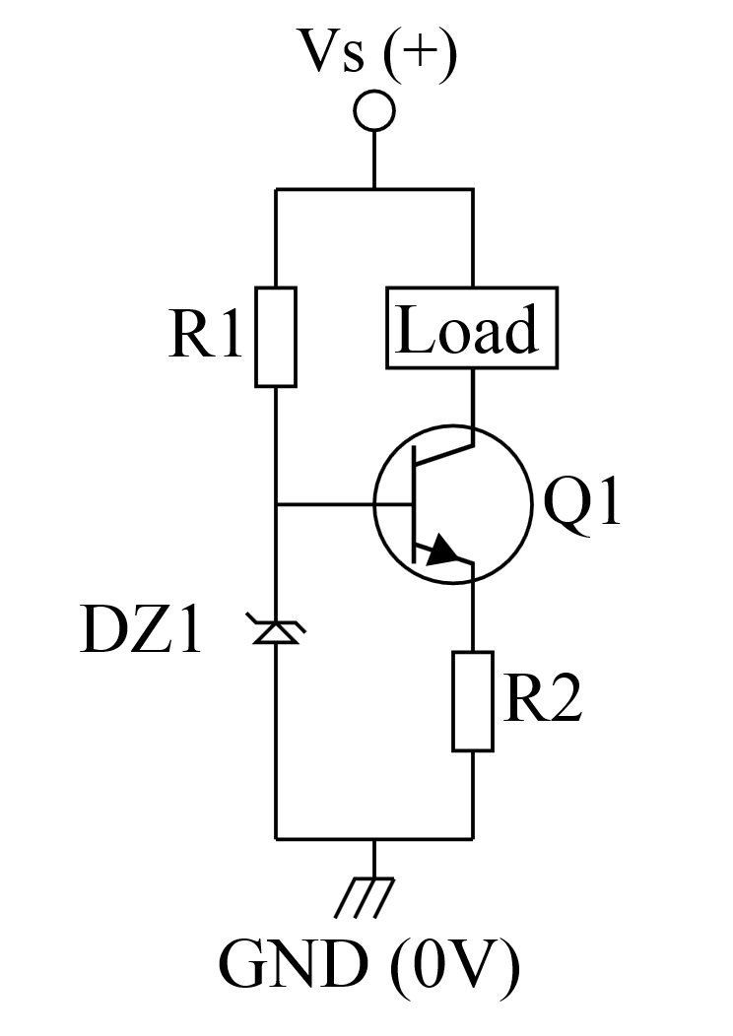
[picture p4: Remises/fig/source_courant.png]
	
	\caption{Source courant à diode Zener}
	\label{f:source_courant}
\end{figure}

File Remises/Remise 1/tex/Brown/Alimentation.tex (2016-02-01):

Pour alimenter adéquatement tous les systèmes présents sur le robot, on doit avoir une batterie avec une tension qui se situe entre 21V et 30V pour alimenter le régulateur de l'ordinateur embarqué, qui fonctionne à 19V avec un courant de 3.5A. On doit également avoir assez de puissance pour que les moteurs et l'électronique de contrôle puissent fonctionner pendant au moins dix minutes. La puissance dont le robot a besoin se définit surtout par celle des moteurs, des servomoteurs et de l'ordinateur embarqué. Les moteurs demandent au maximum 800mA à 12V lorsque le rotor est complètement bloqué et les servomoteurs qui servent à contrôler la caméra demandent environ 30mA à 5V lorsqu'ils sont sollicités, soit un court instant. On utilise également un servomoteur plus puissant pour mouvoir le préhenseur, celui-ci risque de consommer plus de puissance à cause de l'effort plus important qui sera fourni. En additionnant la puissance de ces systèmes, la puissance requise est d'environ 110W dans le pire des cas. Nous avons donc choisi une batterie LiPO 6S de 4 500mA, ce qui peut donner 27A, pour un total de 599W en 10 minutes. Les six cellules sont nécessaires pour avoir 22.2V, ce qui permet d'obtenir le 19V requis pour l'ordinateur embarqué. Le 4 500mA est justifié, car on veut pouvoir travailler sur le robot plus longtemps que 10 minutes à des fins de test. Nous avons calculé que cette batterie pourrait nous donner environ 50 minutes d'autonomie. 
\bigbreak
L'utilisation d'une batterie LiPO nécessite un chargeur intelligent qui refuse de charger la batterie si les cellules ont une tension trop faible, car la batterie pourrait exploser. Nous avons donc acheté un tel chargeur et on utilise également un sac de protection pour diminuer l'impact d'une éventuelle explosion. L'utilisation d'une LiPO requière également un système qui déclenche une alarme sonore lorsqu'il faut recharger la batterie, pour justement empêcher les risques d'explosions. Cette fonction est assurée par un petit afficheur de tension, conçu spécialement pour les batteries LiPO, qui sonne quand la tension des cellules est trop faible. 
\bigbreak
Le robot a donc besoin de trois niveaux de tension différents pour fonctionner. On utilise des régulateurs DC-DC pour avoir une tension stable, aux valeurs désirées. Le régulateur de l'ordinateur embarqué est fourni. Pour le 12V et le 5V, nous avons choisi de prendre trois fois le même régulateur, qui prend 4V à 38V en entrée et peut fournir 1.25V à 36V en sortie (voir liste des pièces \ref{liste_pieces}. Il y aura donc deux régulateurs pour le 12V, pour séparer l'alimentation des moteurs et celle du Arduino, et un régulateur pour le 5V. Celui-ci peut fournir un maximum de 5A et il est doté d'un afficheur de tension pour connaître facilement la valeur réglée en sortie. On protège nos systèmes avec des fusibles pour s'assurer de ne rien briser. Nous avons choisi un fusible de 10A directement à la sortie de la batterie pour protéger l'ensemble du système. Pour les moteurs, on utilise un fusible de 5V, ensuite un fusible de 2A pour l'alimentation de l'Arduino et enfin un fusible de 3A pour les circuits électroniques du 5V. Un interrupteur situé directement suite à la batterie permet finalement d'actionner l'ensemble du système. La figure \ref{f:alim} présente un diagramme en bloc de l'alimentation.

\begin{figure}[htp]
   \centering
   
   \caption{Diagramme en bloc de l'alimentation}
   \label{f:alim}
\end{figure}

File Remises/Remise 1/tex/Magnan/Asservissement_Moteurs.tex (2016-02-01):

Afin de commander les moteurs du robot, il est nécessaire d'avoir une routine d'asservissement. Pour envoyer les commandes aux moteurs DC, l'Arduino Mega est choisi. Celui-ci possède une vitesse d'horloge de 16 MHz et 256kB de mémoire flash pour 45\$ \cite{MEG00}, ce qui est un bon équilibre performance/prix pour les besoins du projet.
\medbreak
Les moteurs utilisés pour entraîner les roues du robot possèdent 6400 valeurs de position par rotation. Si une interruption est effectuée à chaque modification de cette valeur, on risque d'empêcher l'exécution complète d'une boucle d'asservissement entre deux interruptions. Donc, si une interruption est levée à chaque modification de la position, il faut s'assurer que le calcul de la vitesse de rotation se fasse après un nombre multiple d'interruptions, avec un compteur de temps.
\medbreak
Pour ce qui a trait à la communication avec les moteurs DC, un shield Adafruit se connectant directement sur l'Arduino Mega est utilisé. Avec celui-ci, il est possible de générer des ondes modulées (PWM) servant à contrôler les quatre roues individuellement, avec chacune une résolution de 8 bits et jusqu'à 1.2A par canal\cite{SLD00}. Cette division de la commande est utile lors d'un déplacement en diagonale, et pourrait également être utile pour continuer le fonctionnement dans le cas d'une roue défectueuse. Ce dispositif est utilisé pour contrôler les moteurs pour les premiers tests, bien évidemment l'utilisation du pont en H fournit fera aussi l'objet de tests lorsque la batterie et l'alimentation seront disponibles.
\medbreak
En résumé, l'ordinateur envoie des instructions de direction au microcontrôleur Arduino, qui exécute alors une routine de déplacement. Celle-ci est basée sur un asservissement de vitesse, déterminée par des interruptions lors de la rotation des servomoteurs. Les commandes de l'Arduino sont alors communiquées aux roues à l'aide d'un shield Adafruit permettant de leur délivrer de la puissance.

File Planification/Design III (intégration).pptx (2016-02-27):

## Design III (intégration) Pirates des Caraïbes

Présentation d’avancement de projet
Équipe 07 – Zière
GEL : Emile bourque, Jérémy Brown, Matthieu sylvain
Gif : charles-olivier magnan, jean-michel provencher
GLO : Laurent g. garneau, sébastien garvin, xavier kedzierski

## Structure mécanique

- Support pour batterie;
- Circuits électroniques vissés sur plaque de support;
- Interrupteurs et fusibles accessibles;
- Centre de gravité bas;
- Minimiser l’espace perdu.

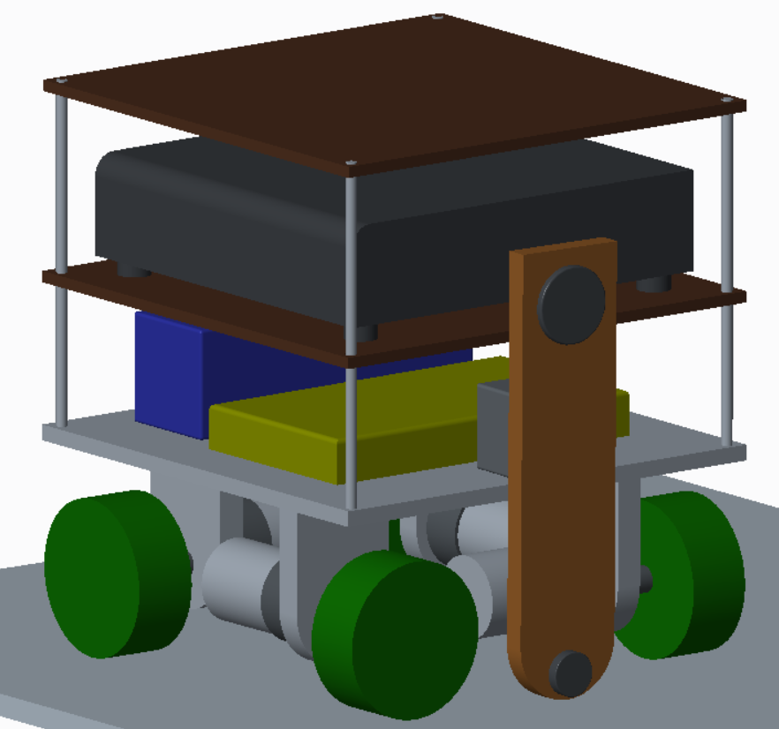
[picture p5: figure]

## Communication sans fil

- Connexion Wifi entre la station de base et l’ordinateur embarqué;
- Réseau Local;
- Protocole TCP;
- Résistant à la perte de paquet;
- Serveur/Client;
- Échange de fichier JSON

## Communications entre les modules

- Communication Arduino – Pololu (UART – Transmit only);
- Communication Arduino – Ordinateur Embarqué (UART – via le port USB);
- Simplicité d’implémentation.

## Système de vision

- Caméra monde gérée par la station de base
- Caméra embarquée gérée par l’ordi embarqué
- Caméra monde pour la phase de déplacement
- Caméra embarquée pour phase d’alignement
- Programmé en Python 2.7 & OpenCV 3.0

## Alimentation

- LiPO 6S de 4.5AH;
- Alarme sonore de basse tension;
- Référence de la batterie reliée à la structure du robot;
- 3 régulateurs de tension;
- Niveaux de tension isolés;
- Protection des systèmes par fusibles;
- Interrupteur manuel de marche/arrêt.

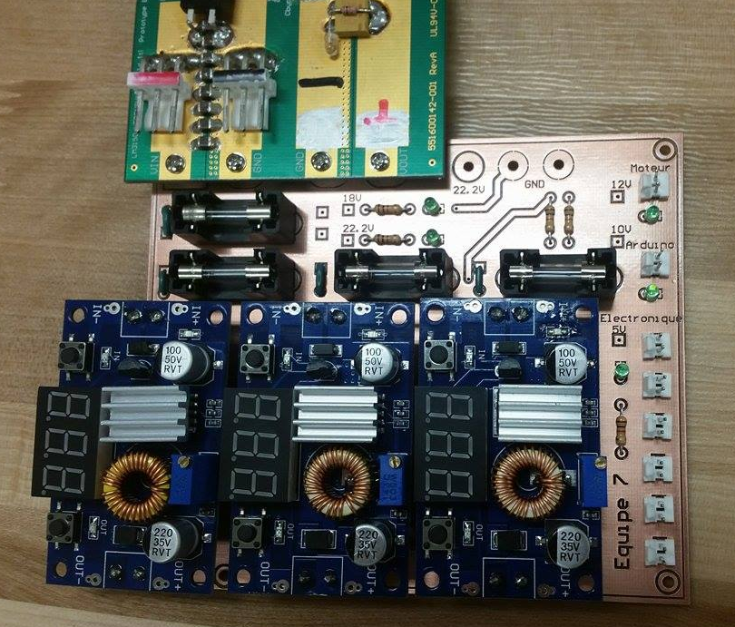
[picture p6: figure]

## Contrôle et asservissement des moteurs

- Contrôle de vitesse et direction par Arduino;
- Lecture de vitesse par largeur d’impulsion;
- Contrôle de vitesse par PWM;
- Asservissement en vitesse;
- Interruptions lors de communications.

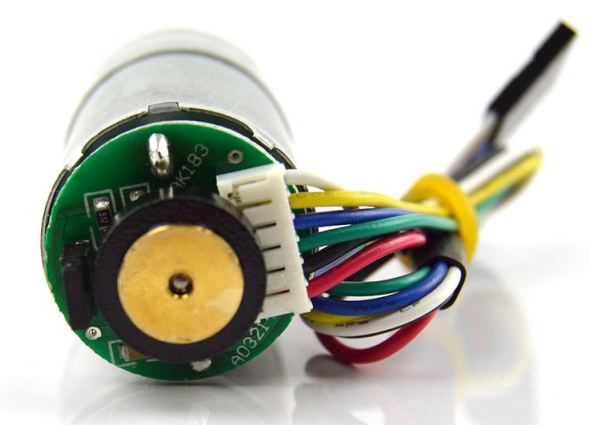
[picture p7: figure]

## Préhenseur et électroaimant

- Préhenseur actionné par un servomoteur;
- Circuit de charge/décharge à courant fixe;
- Saisie et soulève le trésor;
- Recharge et aimant sur le même module;
- Attraction de 1 kg en crête;
- 5 farads et tension de 5 volts.

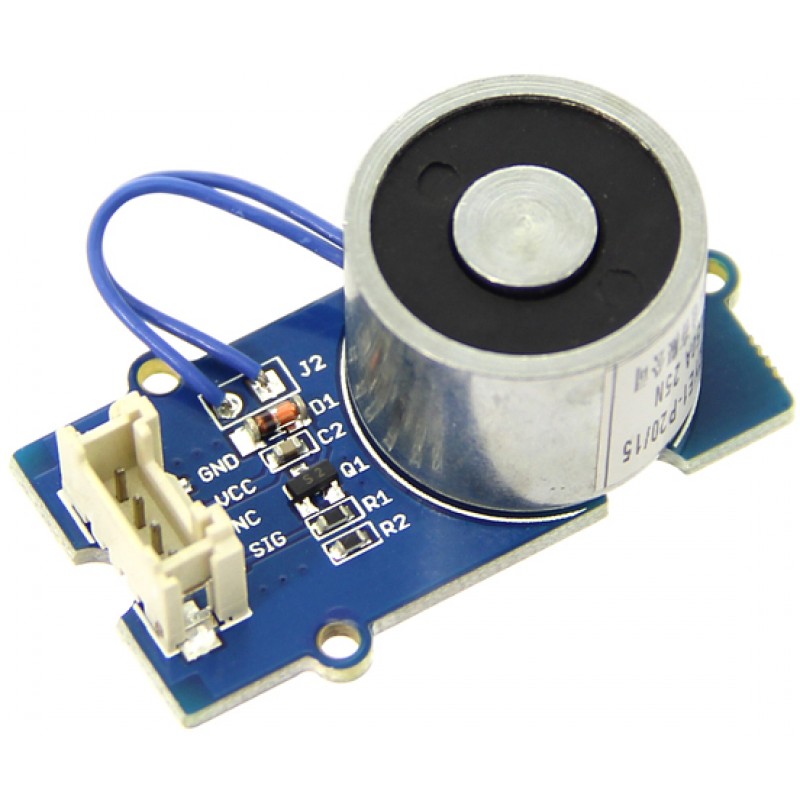
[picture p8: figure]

## Induction pour recharge

- Alimentation de 5VDC;
- Hachage par un MOSFET;
- Rapport de transformation de 3;
- Redresseur double alternance;
- Interrupteur électronique d’arrêt;
- Tension de charge finale de 5V.

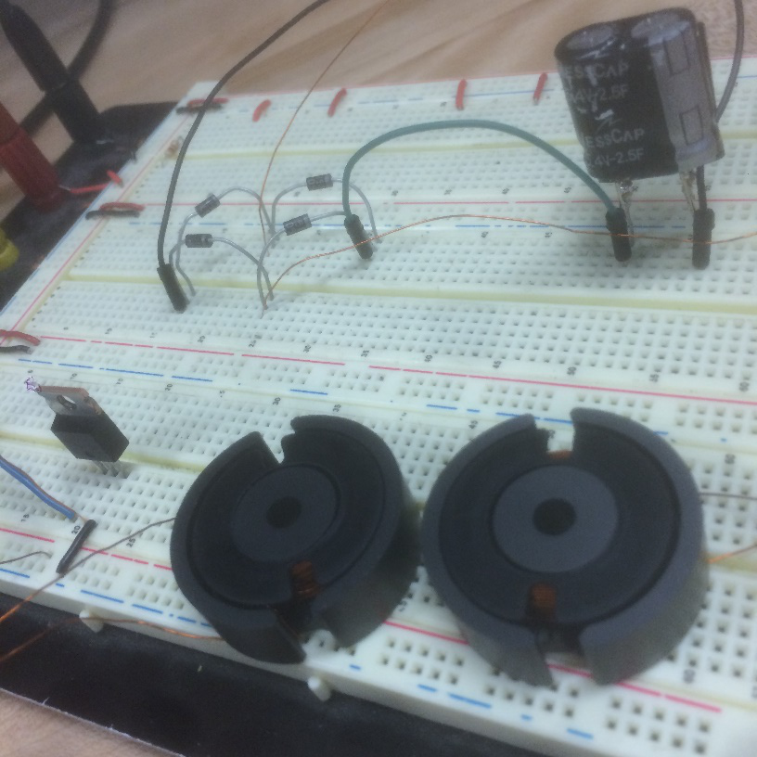
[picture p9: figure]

## Interface de la station de base

- Carte virtuelle et rendu en temps réel;
- Affichage de la position et de l’orientation du robot;
- Affichage en parallèle des trajectoires;
- Affichage de la tension du condensateur;
- Informations sur l’île cible;
- Bouton de démarrage de la routine;
- Programmée en Python et librairie PyQT.

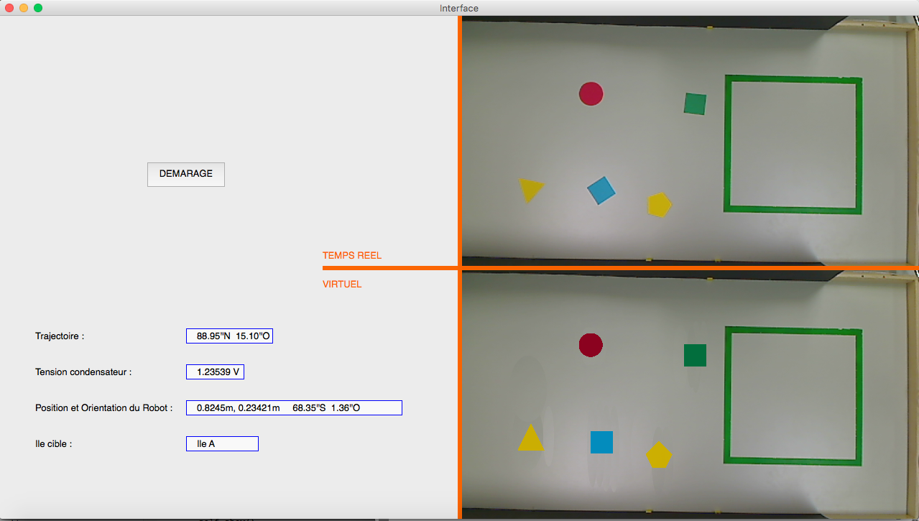
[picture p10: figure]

## Planification de la trajectoire

- Algorithme A*;
- Envoie des commandes au robot;
- Recalcul de la trajectoire après déplacement;
- Zone tampon variable autour des îles;
- Phase de déplacement;
- Phase d’alignement.

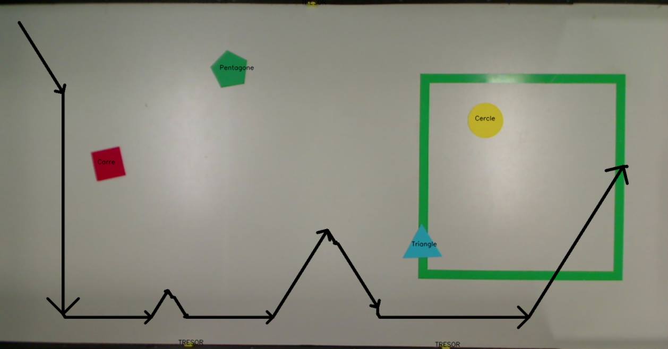
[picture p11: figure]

## Contrôle de la caméra

- Servomoteurs contrôlés par pololu;
- 4 positions prédéterminées;
- Librairie arduino pour Maestro;
- Caméra surélevée sur l’étage supérieur du robot.

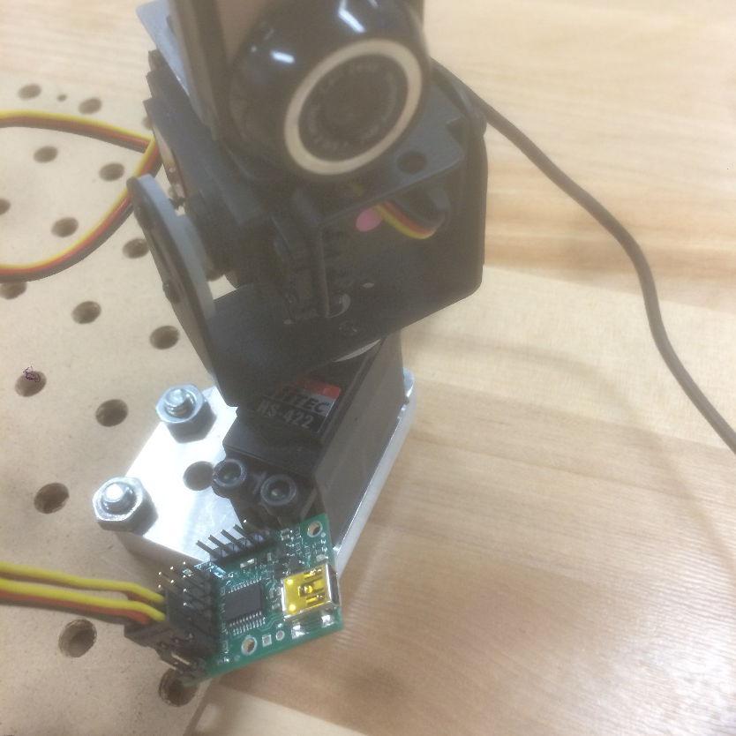
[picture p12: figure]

## Transmission et décodage du code Manchester

- Transmission led à led;
- Horloge basse fréquence;
- Circuit d’amplification des signaux reçus;
- Transmissions séparées du code et de l’horloge;
- Décodage par l’arduino mega.

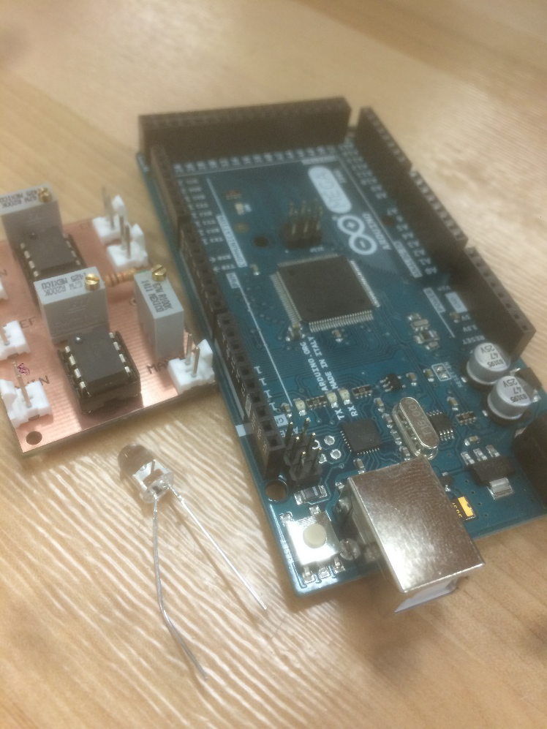
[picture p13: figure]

## Localisation des îles, des trésors et du robot

- Détection par recherche de formes prédéfinies;
- Détection primaire de l’environnement;
- Forme distinctive pour le robot & station de recharge;
- Résolution de 1600x1200.

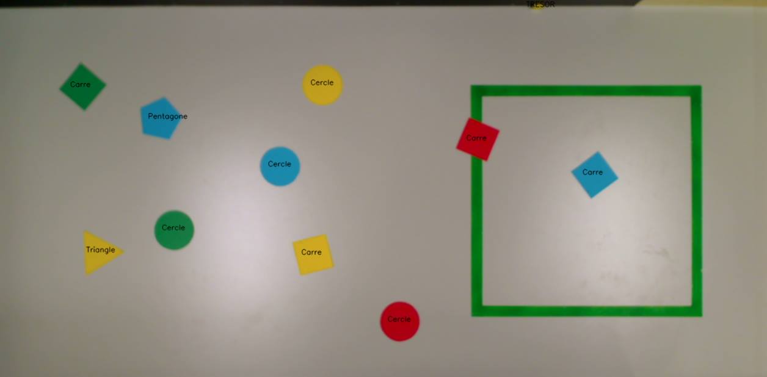
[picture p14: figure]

## Questions

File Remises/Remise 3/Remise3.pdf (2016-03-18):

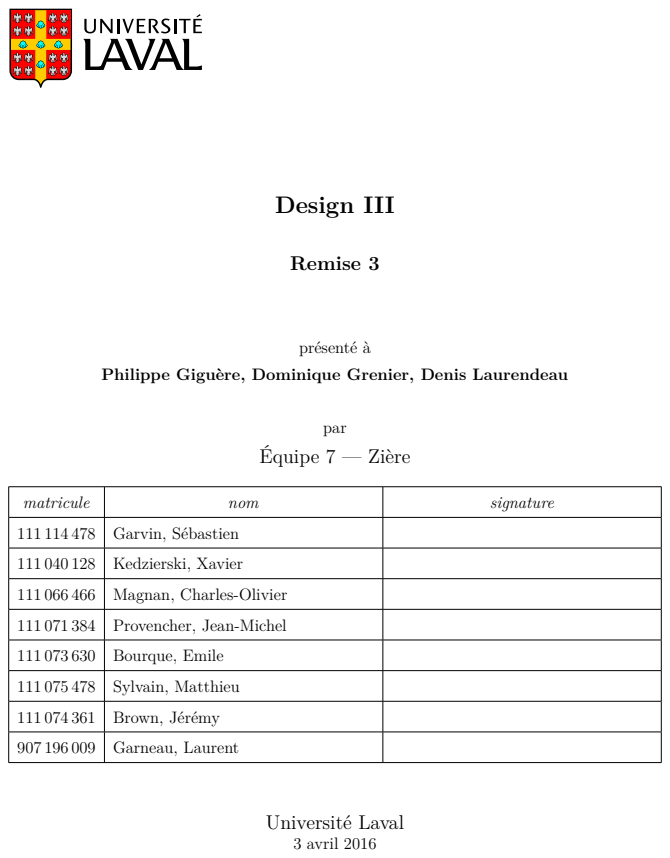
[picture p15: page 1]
Design III; Remise 3; présenté à; par Équipe 7 — Zière; Université Laval 3 avril 2016

Philippe Giguère, Dominique Grenier, Denis Laurendeau

matricule | nom | signature

111 114 478 | Garvin, Sébastien

111 040 128 | Kedzierski, Xavier

111 066 466 | Magnan, Charles-Olivier

111 071 384 | Provencher, Jean-Michel

111 073 630 | Bourque, Emile

111 075 478 | Sylvain, Matthieu

111 074 361 | Brown, Jérémy

907 196 009 | Garneau, Laurent

Historique des versions

version | date | description
1.0 | 24 janvier 2016 | Création du document
2.0 | 31 janvier 2016 | Remise 1
3.0 | 28 février 2016 | Remise 2
4.0 | 3 avril 2016 | Remise 3

# Table des matières

1 Diagrammes | 1
2 Plan d’intégration | 2
3 Vision | 3
4 Schémas Électroniques | 4
Bibliographie | 5

i

# Chapitre 1

# Diagrammes

## 1.1 Diagramme des fonctionnalités

# Chapitre 2

# Plan d’intégration

# Chapitre 3

# Vision

# Chapitre 4

# Schémas Électroniques

## 4.1 Station de recharge

## 4.2 Circuit de charge et de dÃ©charge du condensateur

## 4.3 Circuit de connections pour les moteurs

### 4.3.1 Connections moteurs et pont en H

### 4.3.2 Connections sur l’Arduino

## 4.4 Circuit d’alimentation

## 4.5 Circuit d’amplification du code Manchester

# Bibliographie

[1] ETH Zurich, An LED-to-LED Visible Light Communication System with Software-Based Synchronization, [En ligne], http://people.inf.ethz.ch/schmist/papers/OWC12Slides.pdf, Page consultée le 27 janvier 2016
[2] Robotshop, Arduino Mega 2560 Microcontroller, [En ligne], http: //www.robotshop.com/ca/en/arduino-mega-2560-microcontroller-rev3.html, Page consultÃ©e le 30 janvier 2016
[3] HobbyKing.com, Turnigy 4500mAh 6S 30C Lipo Pack, [En ligne], http://www.hobbyking.com/hobbyking/store/__10284__Turnigy_4500mAh_6S_30C_Lipo_Pack.html, (http://www.hobbyking.com/hobbyking/store/__10284__Turnigy_4500mAh_6S_30C_Lipo_Pack.html) Page consultée le 30 janvier 2016
[4] ebay.ca, DC-DC Step-down Buck Converter Adjustable Power 4V-38V to 1.25V-36V 5A Voltmeter, [En ligne], http://www.ebay.ca/itm/171445007919?_trksid=p2057872.m2749.l2649&ssPageName=STRK%3AMEBIDX%3AIT, (http://www.ebay.ca/itm/171445007919?_trksid=p2057872.m2749.l2649&ssPageName=STRK%3AMEBIDX%3AIT) Page consulté le 30 janvier 2016
[5] Robotshop.com, Grove Electromagnet, [En ligne], http://www.robotshop.com/ca/en/grove-electromagnet.html, Page consultée le 30 janvier 2016

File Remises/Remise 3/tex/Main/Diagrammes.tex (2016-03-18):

\chapter{Diagrammes}
\label{s:Diagrammes}

\section{Diagramme des fonctionnalités}
\label{s:Diagramme_fonctionnalites}

%\begin{figure}[htp]
%   \centering
%   \includegraphics[width=1\textwidth]{pdf/DiagrammeFonctionnalites.pdf}
%   \caption{Diagramme des fonctionnalités}
%   \label{f:diagramme_fonctionnalites}
%\end{figure}

%\section{Diagramme physique}
%\label{s:diagramme_physique}

%\begin{figure}[htp]
%   \centering
%   \includegraphics[width=1\textwidth]{pdf/DiagrammePhysique.pdf}
%   \caption{Diagramme physique}
%   \label{f:diagramme_physique}
%\end{figure}

%\section{Diagramme de séquences}
%\label{s:diagramme_sequence}

%Les figures \ref{f:diagramme_sequence1} à \ref{f:diagramme_sequence4} correspondent aux diagrammes de séquences.

%\begin{figure}[htp]
%   \centering
%   \includegraphics[width=1\textwidth]{fig/demarageRobot.jpg}
%   \caption{Diagramme de séquences: démarage du robot}
%   \label{f:diagramme_sequence1}
%\end{figure}

%\begin{figure}[htp]
%   \centering
%   \includegraphics[width=1\textwidth]{fig/deplaceTresor.jpg}
%   \caption{Diagramme de séquences: Deplacement du trésor}
%   \label{f:diagramme_sequence2}
%\end{figure}

%\begin{figure}[htp]
%   \centering
%   \includegraphics[width=1\textwidth]{fig/initCarte.jpg}
%   \caption{Diagramme de séquences: initialisation de la carte}
%   \label{f:diagramme_sequence3}
%\end{figure}

%\begin{figure}[htp]
%   \centering
%   \includegraphics[width=1\textwidth]{fig/trouverIleOuTresor.jpg}
%   \caption{Diagramme de séquences: trouver les îles et trésors}
%   \label{f:diagramme_sequence4}
%\end{figure}

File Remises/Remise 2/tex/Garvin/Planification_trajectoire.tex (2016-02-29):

La planification de la trajectoire est effectuée avec les positions obtenues de la localisation (voir \ref{s:localisation}). Pour l'instant, elle se déroule comme suit. Premièrement, une grille de cellules est initialisée avec les coordonnées pixels de l'image où chaque cellule représente une coordonnée cartésienne (x,y). Lors de cette création, les pixels qui sont situées à un intervalle près des centres des îles (en x et en y) sont déclarées comme étant inaccessibles. Il y a donc une zone tampon en forme de carré autour de chacune des îles. De plus, la création de la grille est créée avec une incrémentation en x et en y de sorte à conserver seulement les coordonnées pixels situées à plus ou moins un centimètre de distance (sur la table). \medbreak

La raison d'avoir une zone tampon en forme de carré au lieu d'un cercle est simplement puisque l'implémentation est grandement simplifiée. Bien que ceci ne soit pas optimal, une trajectoire pourra tout de même être trouvée dû au nombre réduit d'îles sur la table.  \medbreak

Une fois cette grille initialisée, il suffit de fournir une coordonnée de départ et d'arriver à l'algorithme de planification de trajectoire. Celui-ci est une implémentation de l'algorithme A* (figure \ref{f:Trajectoire}). La raison pour laquelle cet algorithme fut retenue est principalement pour sa rapidité d’exécution. En effet, bien qu'il ne choisi pas le trajet le plus court, il le trouve très rapidement. Cela est primordial puisque le trajet sera recalculé de façon fréquente afin de compenser pour les incertitudes et les erreurs d'approximation. L'autre candidat qui pourrait remplacer l'algorithme A* est l'algorithme de Dijkstra. Cela permettrait d'obtenir le trajet le plus court. Par contre, cela dépendra de sa performance. Cette solution sera explorée prochainement.  \medbreak   

En ce qui concerne la distance physique de plus ou moins un centimètre des pixels dans la grille de cellules, il est sujet à changement. Présentement, avec environ 3000 cellules dans la grille, l'algorithme A* s’exécute presque instantanément. Des tests seront effectuées plus en profondeur selon l'algorithme choisi afin d'avoir une distance physique optimale entre les cellules.

\begin{figure}[htp]
   \centering
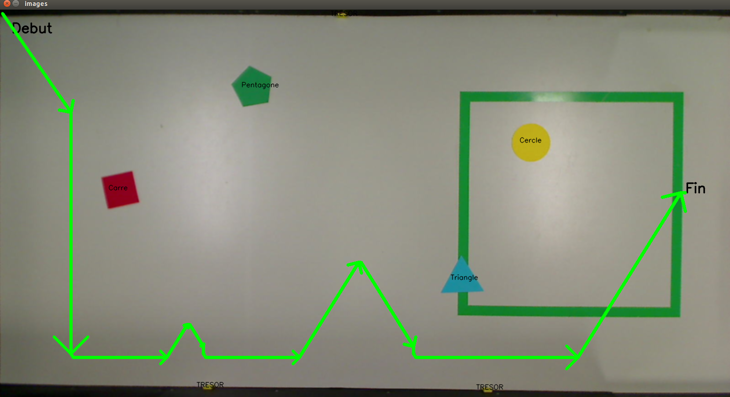
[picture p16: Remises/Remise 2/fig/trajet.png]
   
   \caption{Exemple de trajectoire}
   \label{f:Trajectoire}
\end{figure}
\pagebreak

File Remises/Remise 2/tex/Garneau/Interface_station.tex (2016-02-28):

L'interface de la station de base est conçue pour être simple comme le démontre la figure \ref{f:InterfaceImage}. Elle a comme particularité d'afficher une image virtuelle la plus semblable possible à l'image perçue par la caméra monde.
\medbreak

\begin{figure}[htp]
   \centering
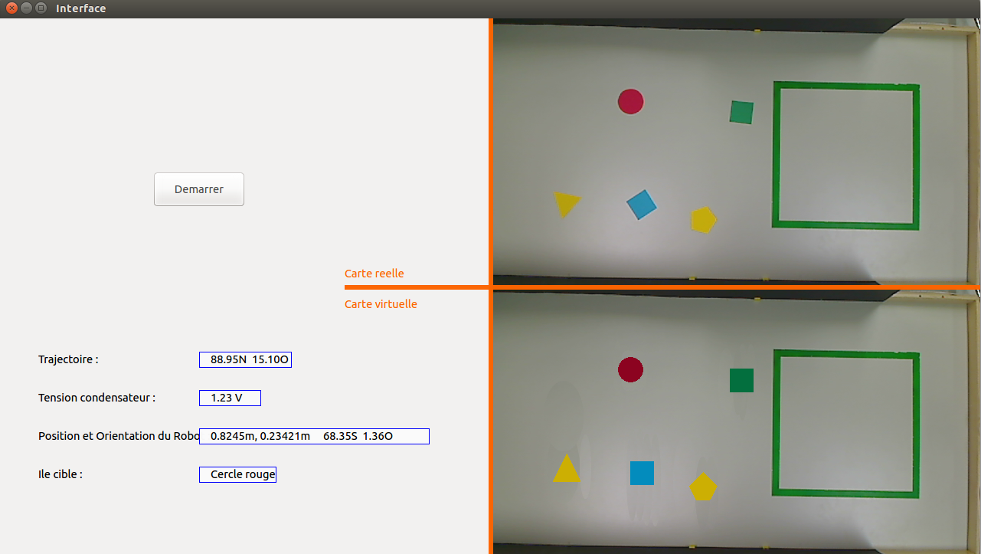
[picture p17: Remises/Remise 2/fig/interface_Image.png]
   
   \caption{Interface de la station de base}
   \label{f:InterfaceImage}
\end{figure}

\medbreak
La section gauche de l'interface nous donne des informations sur la séquence de jeu en général. Elle affiche également des informations pertinentes sur le robot comme l'île cible, l'orientation, la position et la direction du robot ainsi que la tension du condensateur.
\medbreak
Pour l'instant, l'interface n'est pas connectée au système, mais elle est plutôt prête à recevoir des informations telles que la position, la forme et la couleur d'un objet pour la reproduire de façon plutôt similaire dans l'image virtuelle comme le démontre la partie inférieure droite de l'interface.
\medbreak
Le point fort de l'interface est l'idée d'utiliser une photo de la caméra monde avant que les objets soient insérés ou que le robot soit inséré pour ensuite ajouter des objets virtuellement. Ceci aide beaucoup plus à savoir si le système saisi bien les formes, les emplacements et les couleurs de toutes sortes. On obtient une image semblable dans la section virtuelle en bas à droite de l'interface. On constate sur la figure que l'image en temps réel est très semblable à sa reproduction. La forme et la couleur sur le dessus du robot pour pouvoir bien déterminer l'orientation et la position du robot n'ont toujours pas été déterminées. Par contre, lorsqu'elle sera déterminé, il sera nécessaire d'afficher le robot sur les cartes des images virtuelles et réelles.
\medbreak
La trajectoire qu'emprunte le robot ainsi que la trajectoire planifiée devront être intégré à cet environnement. Suite aux conseils reçus en cours, l'implantation d'options de démarrage de tests à différentes étapes de la routine est présentement explorée.

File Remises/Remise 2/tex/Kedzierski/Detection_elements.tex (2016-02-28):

La détection d'éléments est une partie cruciale du système de vision. Le système doit être en mesure de détecter tous les éléments présents sur la table pour que le robot puisse effectuer sa tâche avec succès. 
\medbreak
Au début de la routine, des photos sont prises par la caméra monde et sont analysées pour identifier la position, la forme ainsi que la couleur de toutes les îles présentes sur la table de jeu. La caméra monde offre une résolution intéressante de 1600x1200 pixels, ce qui permet de faire une analyse de qualité. Grâce à cette résolution, le système détecte facilement les trésors placés contre les parois de la table. Toutefois, si aucun trésor n'est détecté, le robot utilisera sa caméra embarquée pour effectuer un balayage des parois afin de les identifier.
\medbreak
Suite à plusieurs tests, il fut conclu que la précision du système de détection était plus précis en appliquant un léger estompement à l'image avant de faire tout traitement. Ceci a pour but d'uniformiser les différentes variations de contraste et de couleurs qui pourraient biaiser les résultats. 
\medbreak
Pour la localisation des îles, chacune des quatre couleurs est filtrée et placée dans un masque afin d'avoir un traitement individuel. Pour la localisation des îles, nous utilisons une méthode de recherche par formes prédéfinies. Le système possède donc en mémoire les contours des formes qui pourraient représenter les îles. Le système est donc en mesure d'identifier la forme qui possède le plus haut taux de compatibilité avec les formes en mémoire. Le résultat du traitement peut être observé dans la figure \ref{f:DetectionForme}.
\medbreak

\begin{figure}[htp]
   \centering
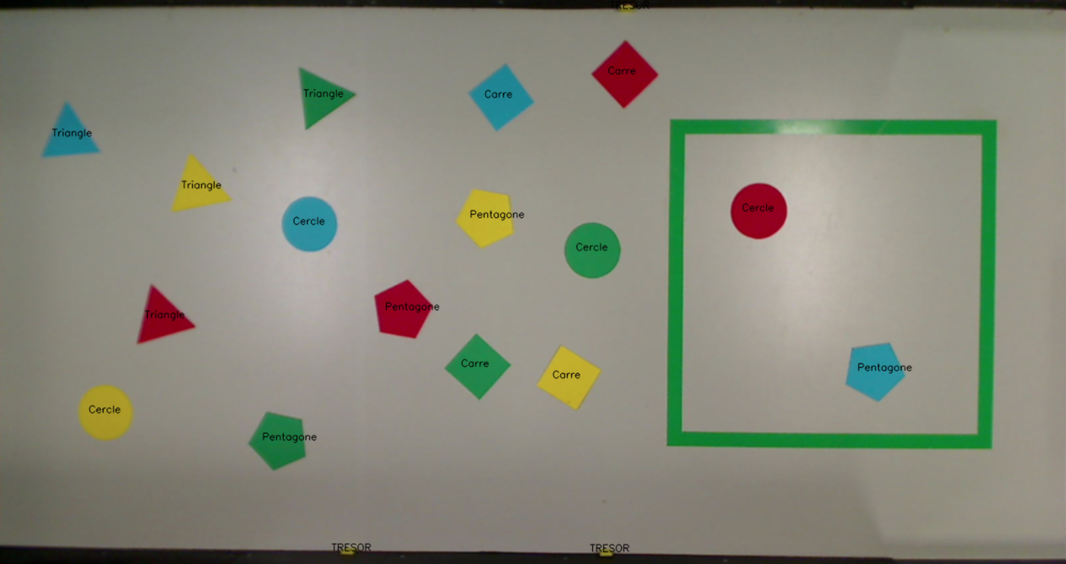
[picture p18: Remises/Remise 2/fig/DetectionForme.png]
   
   \caption{Résultat de la détection des formes}
   \label{f:DetectionForme}
\end{figure}

Cette méthode est beaucoup plus fiable que celle utilisée au départ. La méthode initiale était de détecter le nombre de sommets des formes détectées pour ensuite déduire quelle forme il s'agissait. Cette méthode avait une faiblesse particulièrement pour les formes qui se ressemblent, comme le cercle et le pentagone. Cependant, avec notre nouvelle méthode, les taux de compatibilités sont très précis. En observant la figure \ref{f:PrecisionDetection}, une île ronde possède un taux de compatibilité d'environ 100 fois plus élevé à un cercle qu'à un pentagone.

\begin{figure}[htp]
   \centering
   
   \caption{Précision de la détection des formes}
   \label{f:PrecisionDetection}
\end{figure}

\medbreak
Pour ce qui est du suivi de la position et de l'orientation du robot, un patron unique sera placé au dessus de celui-ci afin d'avoir une référence facilement détectable. Le robot est le seul élément que le système de vision continue de détecter tout au long de la routine puisqu'il est le seul élément mobile sur la carte de jeu.

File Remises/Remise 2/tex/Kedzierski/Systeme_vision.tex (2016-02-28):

Les responsabilités du système de vision sont partagées entre la station de base et le robot. Le système de vision sert à faire une analyse en profondeur de la table de jeu et à prendre des décisions grâce aux informations venant du robot. Le système doit donc être performant et stable afin de ne pas induire le robot en erreur. 
\medbreak
La station de base, par l'entremise de la caméra monde, gère la phase de déplacement tandis que le robot gère la phase d'alignement à l'aide de sa caméra embarquée. La phase de déplacement comporte la détection des éléments cartographiques ainsi que la planification de la trajectoire alors que la phase d'alignement permet au robot de se positionner de manière optimale afin de faciliter l'exécution de la tâche demandée.
\medbreak
La caméra monde est utilisée pour la détection des éléments cartographiques ainsi que pour suivre le déplacement du trésor. Grâce à ces informations, la station de base peut générer une trajectoire et transmettre des commandes au robot.
\medbreak
La caméra embarquée ne sera utilisée que dans deux situations. Tout d'abord, elle servira lorsque aucun trésor n'est détecté par la caméra monde, le robot tentera alors d'identifier la position des trésors grâce à son point de vue plus rapproché. Ensuite, elle sera utilisée lors de la phase d'alignement, afin que le robot puisse se rapprocher sécuritairement d'une cible comme une île, un trésor ou la station de recharge. Donc, une fois la phase de déplacement terminée et le robot rendu devant la cible, le système de vision du robot prendra le contrôle afin d'amorcer la phase d'alignement.

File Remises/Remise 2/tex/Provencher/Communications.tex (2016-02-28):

Afin de pouvoir communiquer entre le robot et la station de base, une communication sans-fil est nécessaire. Comme il est important d'établir une connexion avec détection de perte de paquets, le protocole TCP a été choisi. Grâce à ce protocole, on s'assure que les paquets perdus seront retransmis afin de ne perdre aucune information dans la communication sans-fil entre le robot et la station de base. L'interface client-serveur est programmée en Python à l'aide de la librairie \textit{socket}. Ainsi, en agissant comme serveur, la station de base attendra une connexion client de la part du robot. Une fois cette connexion établie, un échange de fichier JSON contenant des commandes et des paramètres pour le robot s'effectuera. Les principaux avantages d'utiliser un format de fichier JSON pour l'échange de commande est qu'il est simple à implémenter dans plusieurs langages et qu'il est plus facile à "parser" que le XML. Le fichier JSON contient par exemple une clé-valeur "commande": "avancer" ainsi que "parametre": 15. Une telle commande permet donc au robot de faire un déplacement avant de 15 centimètres. Une fois cette tâche complétée, le robot envoie une signal de complétion à la station de base et signale du même coup qu'il est disponible pour la réception d'une nouvelle commande.
\medbreak
Afin de pouvoir recueillir la forme ou la couleur de l'île visée, une requête de type GET est effectuée au serveur des îles. Une fois cette information recueillie de la part du serveur, la forme ou la couleur est envoyé vers l'interface graphique et vers la section de "pathfinding" de la partie logicielle.

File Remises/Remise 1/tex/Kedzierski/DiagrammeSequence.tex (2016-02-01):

Les diagrammes de séquences suivants présentent les différents appels entre les objets du système lors d'un événement précis. 

\begin{figure}[htp]
	\centering
	
	\caption{Démarrage du Robot}
	\label{f:DemRob}
\end{figure}

\begin{figure}[htp]
	\centering
	
	\caption{Initialisation de la carte de jeu}
	\label{f:initCarte}
\end{figure}

\begin{figure}[htp]
	\centering
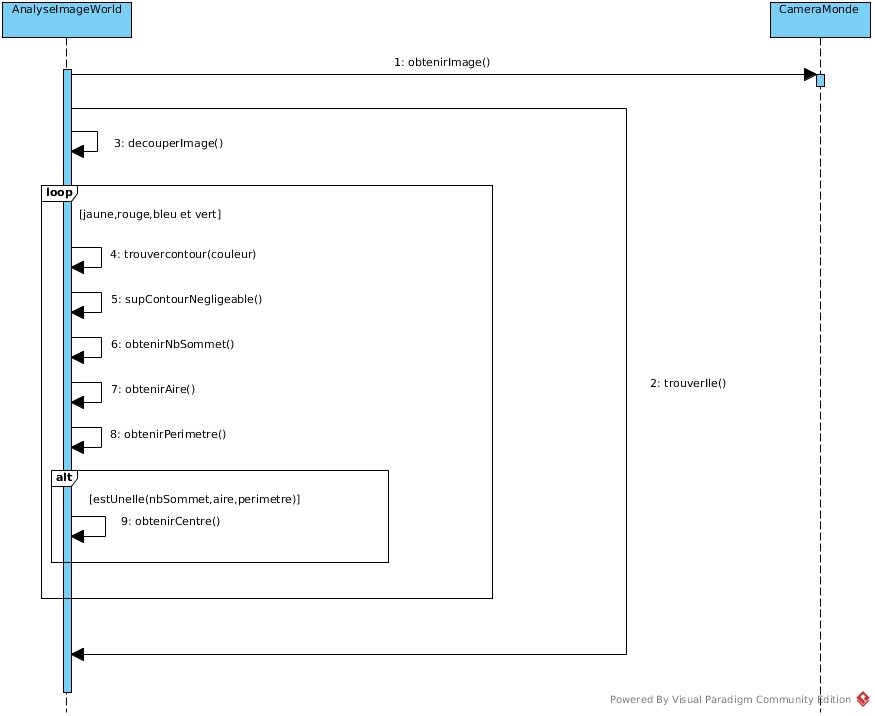
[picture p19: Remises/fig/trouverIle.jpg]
	
	\caption{Identification des îles}
	\label{f:identifierIles}
\end{figure}

\begin{figure}[htp]
	\centering
	
	\caption{Déplacement d'un trésor}
	\label{f:deplacementTresor}
\end{figure}

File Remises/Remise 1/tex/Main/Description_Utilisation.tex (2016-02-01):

\chapter{Description des cas d'utilisation}
\label{s:Description_Utilisation}

\section{Diagramme des cas d'utilisation}
\label{s:Diagramme_Cas_Utilisation}

\begin{figure}[htp]
\centering
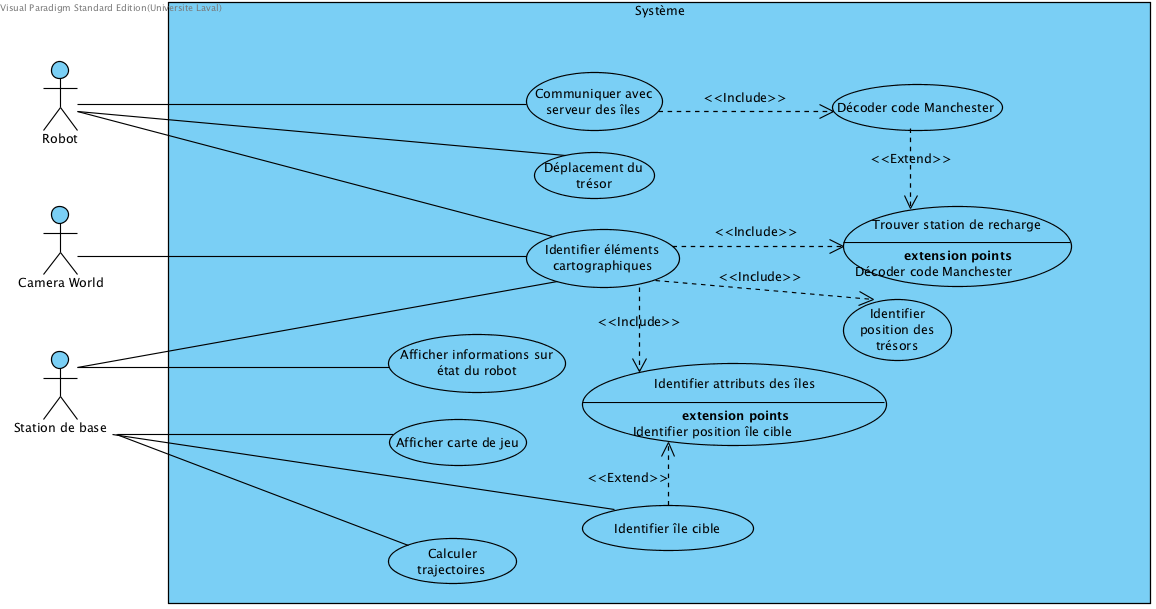
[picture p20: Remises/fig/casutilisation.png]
	
	\label{fig:Cas_Utilisation}
	\caption{Diagramme des cas d'utilisation}
\end{figure}

\input{tex/Kedzierski/casutilisation.tex}
\pagebreak

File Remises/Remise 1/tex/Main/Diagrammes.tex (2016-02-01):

\chapter{Diagrammes}
\label{s:Diagrammes}

\section{Diagramme de contexte}
\label{s:Diagramme_contexte}

\begin{figure}[htp]
   \centering
   
   \caption{Diagramme de contexte}
   \label{f:Diagramme_contexte}
\end{figure}

\newpage

\section{Diagramme de classes}
\label{s:Diagramme_classes}

\begin{figure}[htp]
   \centering
   
   \caption{Diagramme de classes}
   \label{f:Diagramme_Classes}
\end{figure}

\newpage

\input{tex/Garvin/DiagrammeClasses.tex}

\newpage
\section{Diagramme de séquences}
\label{s:Diagramme_sequences}

\input{tex/Kedzierski/DiagrammeSequence.tex}

%\begin{figure}[htp]
%   \centering
%   \includegraphics[width=1\textwidth]{Diagramme_sequences}
%   \caption{Diagramme de séquences}
%   \label{f:Diagramme_sequences}
%\end{figure}

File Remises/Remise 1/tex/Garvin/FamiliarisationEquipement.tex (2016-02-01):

La caméra Logitech C905 située en hauteur permet de visionner une grande partie de la table. Celle-ci sera branchée par USB à la station de base. Les tests effectués jusqu'à présent nous ont permis de contempler la vision limitée de la table de jeu (figure \ref{f:testCameraMonde}). C'est donc pour cette raison que seule une première approximation sur la position des trésors pourra être faite. La localisation plus précise de ceux-ci se fera par la caméra embarquée (idem pour la station de recharge). Voir la section \ref{s:Reperage}.
\medbreak
La détection des îles et du robot se fait par la station de base à l'aide de la caméra monde. Pour ce faire, le logiciel OpenCV est utilisé. Premièrement, l'image est découpée de sorte qu'elle ne contienne que la table de jeu. Cet outil très puissant nous permet aussi de détecter les contours d'objets à l'intérieur d'image en utilisant les couleurs pour les distinguer (BGR). Les contours jaunes, bleus, rouges et verts sont détectés afin de repérer les îles. Afin d'éviter les erreurs, une relation entre le nombre de coins, le périmètre et l'aire des contours sera vérifiée. La validation de cette relation confirmera la présence d'une île tout en indiquant sa géométrie et sa couleur (selon le nombre de coins et l'intervalle BGR utilisé). Nous avons déjà testé ces étapes et elles semblent plutôt efficaces (figure \ref{f:testDetectionCouleur}). Pour localiser le robot, une forme et une couleur particulière seront placées au dessus du robot. Nous procéderons de façon similaire pour le détecter.

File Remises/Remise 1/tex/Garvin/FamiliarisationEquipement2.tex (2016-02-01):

Cette étape est basée sur des recherches, mais n'a pas encore été testée. Nous prévoyons détecter les coordonnées pixels du milieu de chaque île (à l'aide des contours et d'une fonction préétablie de OpenCV). Une simple échelle pourra ensuite convertir les coordonnées pixels en coordonnées réelles.
\medbreak
La planification de la trajectoire sera faite avec un algorithme Djikstra. Un graphe sera créé (représenté par une grille de points ayant une distance à déterminer entre eux). Évidemment, les points situés à proximité des îles seront exclus du graphe. À l'aide des informations ci-dessus, l’algorithme pourra trouver le plus court chemin jusqu'à la destination.

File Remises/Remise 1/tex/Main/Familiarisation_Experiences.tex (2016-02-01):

\chapter{Familiarisation avec équipements et expériences préliminaires}
\label{s:Familiarisation_Experiences}

\section{Structure mécanique}
\label{s:Structure_mecanique}

\input{tex/Sylvain/systeme_mecanique.tex}

\pagebreak

\section{Système de préhenseur et d'électroaimant}
\label{s:Prehenseur}

\input{tex/Bourque/prehenseur.tex}

\pagebreak

\section{Contrôle de la caméra}
\label{s:controle_camera}

\input{tex/Sylvain/controle_camera.tex}

\pagebreak

\section{Contrôle des moteurs}
\label{s:Controle_moteurs}

\input{tex/Magnan/Asservissement_Moteurs.tex}

\section{Localisation du robot et des îles}
\label{s:Localisation_Robot_Iles}

\input{tex/Garvin/FamiliarisationEquipement.tex}

\section{Calcul de la trajectoire}
\label{s:calcule_trajectoir}

\input{tex/Garvin/FamiliarisationEquipement2.tex}

\section{Repérage des trésors et de la station de recharge}
\label{s:Reperage}

\input{tex/Provencher/Tresors_et_Recharge.tex}

\section{Alimentation du robot}
\label{s:Alimentation}

\input{tex/Brown/Alimentation.tex}

\section{Transmission du code Manchester}
\label{s:Communication}

\input{tex/Bourque/comm_sans_fil.tex}

\section{Liste des pièces achetées}

\input{tex/Main/liste_pieces}

%Autres sections au choix selon ce qui sera décidé

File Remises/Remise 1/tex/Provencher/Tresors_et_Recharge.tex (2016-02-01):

La caméra Logitech C905 située sur le robot permet de repérer les différents trésors ainsi que la station de recharge. Celle-ci est reliée directement à l'ordinateur embarquée afin d'être alimentée et de fournir les images captées. La fréquence de captation des images reste à déterminer puisqu'il faudra décider à quel intervalle nous devons mettre à jour la vision du robot. L'envoi des commandes servant à contrôler la prise d'image par la caméra sera effectuée par la librairie Pygame de Python.
\medbreak
Afin de détecter les trésors, une première approximation de leur position est effectuée par la caméra monde qui, à l'aide de la librairie cv2 de OpenCV, permet de localiser dans une image un intervalle de couleur BGR. Le choix de la librairie d'OpenCV est justifié par le fait qu'elle possède toutes les fonctions nécessaires à un programme de vision complet et qu'elle s'intègre facilement au reste du code en Python. Les tests préliminaires effectuées avec la caméra monde ont permis de venir à la conclusion que la détection des trésors s'effectuent très bien. Par contre, le premier test de la prise de photo a également permis de constater que la caméra monde ne voit pas le fond de la table et donc, certains trésors ne seront pas détecter par celle-ci, justifiant également la détection des trésors par la caméra embarquée.

\begin{figure}[htp]
	\centering
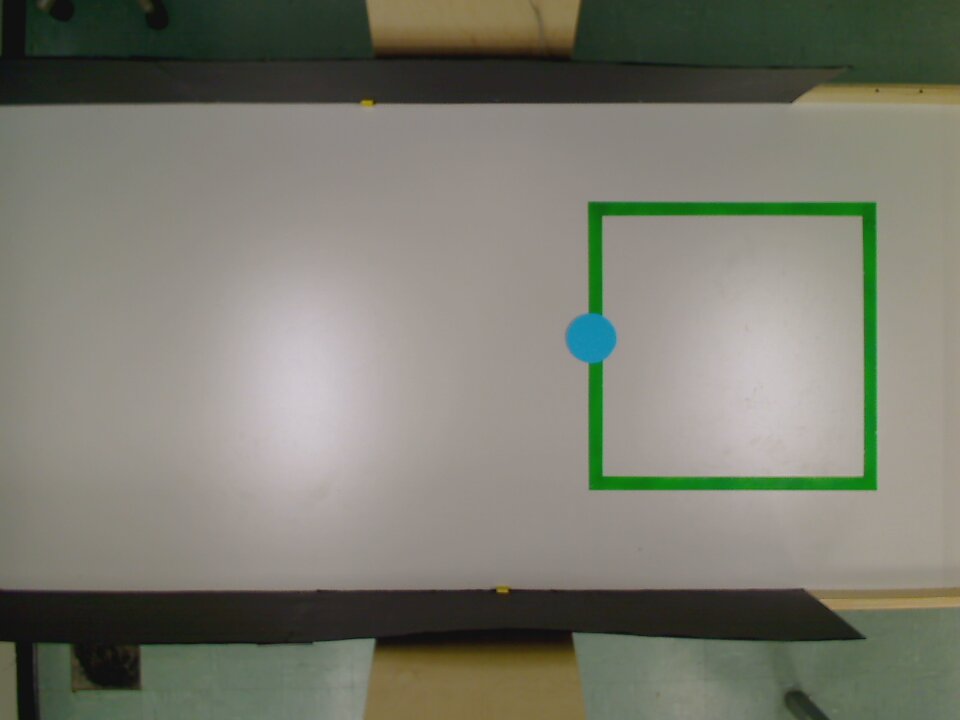
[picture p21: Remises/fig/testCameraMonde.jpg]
	
	\caption{Photo test de la caméra monde}
	\label{f:testCameraMonde}
\end{figure}

Comme mentionné précédemment, les premiers tests effectués afin de détecter les trésors ont démontré qu'il était possible de bien repérer les trésors à partir de la caméra monde comme la figure \ref{f:testDetectionCouleur} le montre.

\begin{figure}[htp]
	\centering
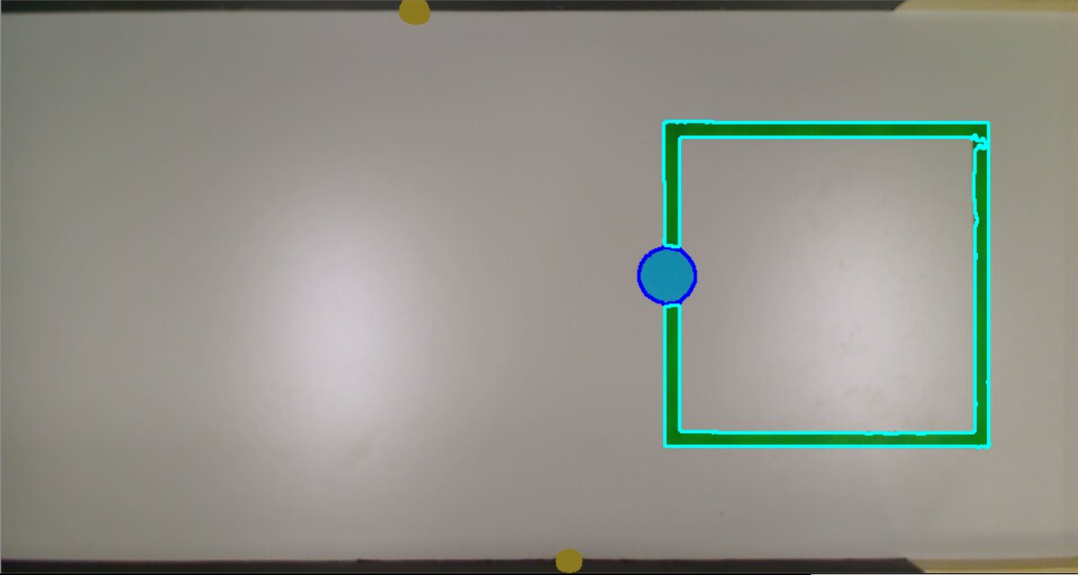
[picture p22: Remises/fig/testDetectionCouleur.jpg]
	
	\caption{Photo test après l'application des masques de détection}
	\label{f:testDetectionCouleur}
\end{figure}

 Par la suite, les différents pixels correspondant à la couleur des trésors sont placés dans un masque des trésors. Grâce à la position relative de ces points dans le masque des trésors, il est possible d'avoir une position approximative de ces trésors dans la carte virtuelle. Afin de confirmer la détection des trésors ou pour repérer les autres qui seront hors du champ de vision du robot, la même opération de détection des couleurs est effectuée ensuite par la caméra embarquée autour des coordonnées approximative détectée par la caméra monde. 
\medbreak
La station de recharge, quant à elle, est marquée d'une couleur caractéristique lui permettant de se distinguer du reste du décor. Comme la position et l'orientation du robot sont connues en tout temps et que la station de recharge est toujours située au même endroit, la détection de celle-ci est assez simple. Comme le robot peut être placé n'importe où au départ sur la table, la caméra monde est chargée à l'initialisation du programme de détecter la position et l'orientation de celui-ci. Afin de réaliser cette tâche, un agencement de couleur distinctif est placé sur le dessus du robot afin d'indiquer l'orientation ainsi que la position de celui-ci et sera détecter par notre programme de vision. Le robot peut ensuite se diriger vers les coordonnées fixes de la station de recharge et la repérer facilement par la suite.

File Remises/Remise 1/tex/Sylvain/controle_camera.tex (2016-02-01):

La caméra embarquée est contrôlée par les servomoteurs fournis qui permettent à la caméra un déplacement sur son axe horizontal et vertical afin d'augmenter le champ de vision du robot. De manière à contrôler le \textit{Polulu Maestro}, des commandes sont envoyées par USB à partir de l'ordinateur embarqué situé sur le robot. Le Pololu est facilement contrôlable par du code en langage \textit{C} géré par l'ordinateur embarqué. De manière à se familiariser avec le fonctionnement de ce système nous utilisons le \textit{Maestro Control Center} afin de voir quelles sont les limites du champ de vision de cette caméra. Sur la figure \ref{f:cam_embarquee} on voit que le robot peut facilement voir le sol directement devant lui, ceci est utile afin de repérer les trésors, les îles et même la station de recharge à des distances très courtes. On remarque aussi qu'il est possible de fixer des limites logicielles de mouvement pour les différents servomoteurs, une fonctionnalité qui facilitera l'implantation du contrôle de la caméra.

\begin{figure}[htp]
   \centering
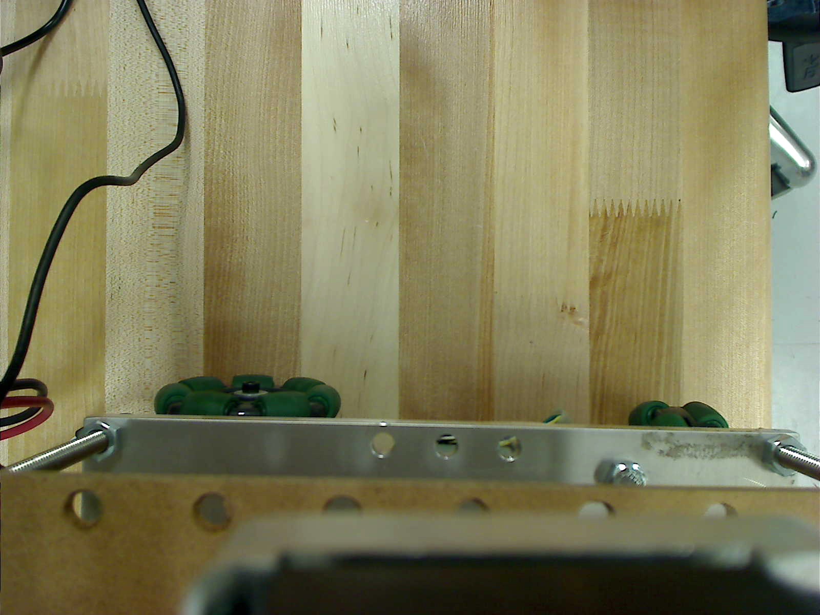
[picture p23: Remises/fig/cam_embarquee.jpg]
   
   \caption{Vision au sol du robot à partir de la caméra embarquée}
   \label{f:cam_embarquee}
\end{figure}

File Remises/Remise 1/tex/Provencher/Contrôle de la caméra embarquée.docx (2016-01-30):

Contrôle de la caméra embarquée

La caméra Logitech C905 située sur le robot permettra de repérer les différents trésors ainsi que la station de recharge. Cette caméra sera contrôlée par les Servomoteurs fournis qui permettront à la caméra un déplacement sur son axe horizontal et vertical afin d’augmenter le champ de vision du robot. Afin de contrôler le « Polulu » Maestro 6-Channel USB Servo Controller, des commandes seront envoyées par USB à partir de l’ordinateur embarqué situé sur le robot. La caméra embarquée sera également reliée directement à l’ordinateur embarquée afin d’être alimentée et de fournir les images captées. La fréquence de captation des images reste à déterminer puisqu’il faudra décider à quel intervalle nous devons mettre à jour la vision du robot. L’envoi des commandes afin de contrôler la prise d’image par la caméra sera effectuée par la librairie Pygame en Python.

Détection des trésors et de la station de recharge

Afin de détecter les trésors, une première approximation de leur position est effectuée par la caméra monde qui, à l’aide de la librairie cv2 de OpenCV, permet de localiser dans une image un intervalle de couleur BGR. Le choix de la librairie d’OpenCV est justifié par le fait qu’elle possède toutes les fonctions nécessaires à un programme de vision complet et qu’elle s’intègre facilement au reste du code en Python. Les tests effectuées avec la caméra monde ont permis de venir à la conclusion que la détection des trésors s’effectuent très bien. Par contre, les tests ont également permis de constater que la caméra monde ne voit pas le fond de la table et donc, certains trésors ne seront pas détecter par la caméra monde, justifiant la détection des trésors également par la caméra embarquée. Par la suite, les différents pixels correspondant à la couleur des trésors sont placés dans un masque des trésors. Grâce à la position relative de ces points dans le masque des trésors, il est possible d’avoir une position approximative de ces trésors dans la carte virtuelle. Afin de confirmer la détection de ces trésors ou pour repérer les trésors qui seront hors du champ de vision du robot, la même opération de détection des couleurs est effectuée ensuite par la caméra embarquée autour des coordonnées approximative détectée par la caméra monde.

La station de recharge, quant à elle, est marquée d’une couleur caractéristique lui permettant de se distinguer du reste du décor. Comme la position et l’orientation du robot est connue en tout temps et que la station de recharge est toujours situé au même endroit, la détection de celle-ci est assez simple. Comme le robot peut être placé à n’importe quel endroit au départ sur la table, la caméra monde est chargée à l’initialisation du programme de détecter la position et l’orientation de celui-ci. Afin de réaliser cette tâche, un drapeau pirate est placé sur le dessus du robot afin d’indiquer l’orientation ainsi que la position de celui-ci et sera détecter par notre programme de vision.

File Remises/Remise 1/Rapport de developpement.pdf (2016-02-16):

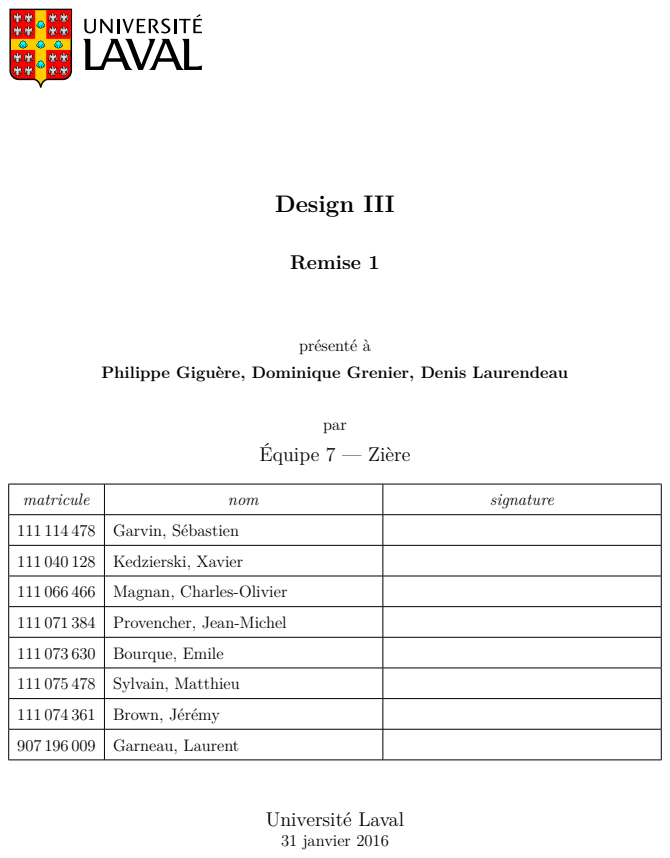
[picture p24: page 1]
Design III; Remise 1; présenté à; par Équipe 7 — Zière; Université Laval 31 janvier 2016

Philippe Giguère, Dominique Grenier, Denis Laurendeau

matricule | nom | signature

111 114 478 | Garvin, Sébastien

111 040 128 | Kedzierski, Xavier

111 066 466 | Magnan, Charles-Olivier

111 071 384 | Provencher, Jean-Michel

111 073 630 | Bourque, Emile

111 075 478 | Sylvain, Matthieu

111 074 361 | Brown, Jérémy

907 196 009 | Garneau, Laurent

Historique des versions

version | date | description
1.0 | 24 janvier 2016 | Création du document
2.0 | 31 janvier 2016 | Remise 1

# Table des matières

1 Diagrammes | 1
2 Description des cas d’utilisation | 6
3 Familiarisation avec équipements et expériences préliminaires | 18
Bibliographie | 29

i

# Chapitre 1

# Diagrammes

1.1 | Diagramme de contexte Business Process Diagram1 Caméra Monde Caméra robot Dispositif de communication sans-fil Serveur des îles | Station de base | Affichage de la tension du condensateur Affichage de la position et orientation du robot Affichage de la lettre ASCII Affichage de la trajectoire planifiée Rotation des roues Affichage de la forme/couleur de l'île Manipulation du trésor Ordinateur embarqué | Microcontrolleur Électroaimant Robot | Saisie et relâchement Activation et désactivation | Commande de direction/vitesse Appel des méthodes de déplacement par UART Vidéo fournissant position du robot, de la station de recharge et la position et le format des îles Réponse JSON contenant les informations de l'île cible Code secret sous format Manchester Vidéo fournissant position des trésors, des îles et de la station de recharge Requête HTML utilisant le code... | Communication sans fil des informations sur la trajectoire | Affichage sur interface utilisateur Visual Paradigm Standard Edition(Universite Laval) Figure 1.1 – Diagramme de contexte

1

CHAPITRE 1. DIAGRAMMES | 2

## 1.2 Diagramme de classes


Figure 1.2 – Diagramme de classes

CHAPITRE 1. DIAGRAMMES | 3

La figure 1.2 représente le diagramme de classes suite à la première itération. La structure est susceptible de changer suite aux prochaines itérations, mais voici une brève description de l’architecture actuelle de l’aspect logiciel du projet.

La section de gauche du diagramme sera implémentée sur la station de base, tandis que la section de droite sera implémentée sur le robot. Ces deux système pourront communiquer entre eux à l’aide des classes CommunicationRobot et CommunicationStationBase.

En ce qui concerne la station de base, le contrôleur du système est représenté par la classe StationBase. La classe AnalyseImageWorld analyse les images reçues de la CameraMonde et génère une carte schématique de la table (Carte) à l’aide d’imagerie. La carte est composée de divers éléments qui héritent tous de la classe Position. Les trajectoires du robot seront calculées dans la classe TrajetStation à l’aide des informations de la classe Carte.

Pour ce qui est du robot, il est aussi composé d’un contrôleur (Robot). Les demandes de mouvement que devra effectuer le robot passeront toutes par la classe Action, qui les acheminera au microcontrôleur Arduino Mega 2560. Lorsque le robot sera près de la destination, TrajetRobot calculera les trajets (à l’aide de Destination et d’imagerie effectuée dans AnalyseImageEmbarquer).

CHAPITRE 1. DIAGRAMMES | 4

## 1.3 Diagramme de séquences

Les diagrammes de séquences suivants présentent les différents appels entre les objets du système lors d’un événement précis.


Figure 1.3 – Démarrage du Robot

CHAPITRE 1. DIAGRAMMES | 5


Figure 1.4 – Initialisation de la carte de jeu

# Chapitre 2

# Description des cas d’utilisation

## 2.1 Diagramme des cas d’utilisation


Figure 2.1 – Diagramme des cas d’utilisation

6

CHAPITRE 2. DESCRIPTION DES CAS D’UTILISATION | 7

## 2.2 Scénarios des cas d’utilisation

Cas d’utilisation | Identifier les éléments cartographiques
Système | Système de reconnaissance visuelle
Acteurs | Robot, caméra world, station de base
Partie prenante et intérêt | Station de base : Vouloir identifier les éléments pré-sents sur la carte afin que le robot puisse remplir son mandat sans entrer en collision avec quoi que ce soit.
Préconditions | Le robot et la caméra world doivent fournir des images à la station de base
Garantie en cas de succès | Les éléments cartographiques sont affichés sur la carte de la station de base
Scénario principal | 1. La caméra world envoie des images à la station de base 2. La surface de jeu, les îles, le robot, ainsi que les trésors visibles sont identi-fiés par le système de re-connaissance visuelle 3. Le robot envoie des images à la station de base 4. Le système de recon-naissance visuelle analyse ces images pour valider les positions des trésors
Scénarios alternatifs | Aucun scénario alternatif

Tableau 2.1 – Cas d’utilisation - Identifier les éléments cartographiques

CHAPITRE 2. DESCRIPTION DES CAS D’UTILISATION | 8
Cas d’utilisation | Trouver station de recharge
Système | Système de reconnaissance visuelle
Acteurs | Robot, caméra world, station de base
Partie prenante et intérêt | Robot : Faire le plein d’énergie et recevoir le code Manchester
Préconditions | La station de base a identifié la position de la station de recharge et une trajectoire a été calculée
Garantie en cas de succès | La trajectoire menant le robot jusqu’à la station de recharge est affichée sur la carte de la station de base. Le robot se déplace vers la station de recharge sans toucher à aucun obstacle.
Scénario principal | 1. La caméra world et le robot envoient des images à la station de base 3. Le système de recon-naissance visuelle analyse ces images et determine l’emplacement de la sta-tion de recharge 4. Un itinéraire vers la sta-tion de recharge peut être calculé
Scénarios alternatifs | 3-1. Le système de recon-naissance visuelle analyse ces images et ne peut de-terminer l’emplacement de la station de recharge 4. La station de base ordonne un déplacement aléatoire au robot 5. Le robot se déplace et renvoie des images à la sta-tion de base

Tableau 2.2 – Cas d’utilisation - Trouver la station de recharge

CHAPITRE 2. DESCRIPTION DES CAS D’UTILISATION | 9
Cas d’utilisation | Identifier la position des trésors
Système | Système de reconnaissance visuelle
Acteurs | Robot, caméra world, station de base
Partie prenante et intérêt | Robot : Identifier les positions des trésors cachés sur la table de jeu, afin de se déplacer jusqu’à l’un d’eux et le rapatrier sur l’île cible.
Préconditions | La station de base reçoit des images venant de la caméra world ainsi que celle du robot
Garantie en cas de succès | Les trésors sont identifiés sur la carte de la station de base et un trésor cible est choisit parmi ceux-ci. Le robot se dirigera vers ce trésor cible pour le déplacer jusqu’à l’île cible.
Scénario principal | 1. La caméra world et le robot envoient des images à la station de base 2. Les trésors visibles sont identifiés et une trajectoire est calculée 3. Le robot se déplace jus-qu’au trésor
Scénarios alternatifs | 2-1. Aucun trésor n’est identifié 3. La station de base ordonne un déplacement aléatoire au robot 4. Le robot se déplace et renvoie des images à la sta-tion de base

Tableau 2.3 – Cas d’utilisation - Identifier la position des trésors

CHAPITRE 2. DESCRIPTION DES CAS D’UTILISATION | 10
Cas d’utilisation | Identifier les attributs des îles
Système | Système de reconnaissance visuelle
Acteurs | Robot, caméra world, station de base
Partie prenante et intérêt | Robot : Identifier la couleur, la forme ainsi que la position des îles pour calculer une trajectoire valide.
Préconditions | La station de base reçoit des images venant de la caméra world
Garantie en cas de succès | La couleur, la forme ainsi que la position des îles sont affichées sur la carte de la station de base. Une tra-jectoire vers un trésor peut par la suite être calculée.
Scénario principal | 1. La caméra world envoie des images à la station de base 2. La couleur, la forme et la position des îles sont identifiées par le système de reconnaissance visuelle
Scénarios alternatifs | Aucun scénario alternatif

Tableau 2.4 – Cas d’utilisation - Identifier les attributs des îles

CHAPITRE 2. DESCRIPTION DES CAS D’UTILISATION | 11
Cas d’utilisation | Identifier la position de l’île cible
Système | Système de reconnaissance visuelle
Acteurs | Robot, caméra world, station de base
Partie prenante et intérêt | Robot : Une fois en possession d’un trésor, le robot déplacera le trésor jusqu’à l’île cible et déposera le trésor sur celle-ci.
Préconditions | Le code Manchester contenant l’information sur l’île cible a été décodé et transmis à la station de base. Les attributs des îles ont été identifiés avec succès.
Garantie en cas de succès | Une fois la récupération d’un trésor terminée, une trajectoire vers l’île cible peut être calculée.
Scénario principal | 1. L’information envoyé par le serveur des îles est transmise à la station de base par le robot 2. L’emplacement de l’île cible est identifié par le système de reconnaissance visuelle
Scénarios alternatifs | Aucun scénario alternatif, l’identification de l’île cible doit toujours être réussie

Tableau 2.5 – Cas d’utilisation - Identifier la position de l’île cible

CHAPITRE 2. DESCRIPTION DES CAS D’UTILISATION | 12
Cas d’utilisation | Décoder le code Manchester
Système | Ordinateur embarqué
Acteurs | Robot, caméra world, station de base
Partie prenante et intérêt | Robot : Une fois le code reçu, il sera décodé et une requête au serveur des îles sera effectuée.
Préconditions | Le robot doit s’être rendu à la station de recharge, où le transfert du code Manchester a lieu.
Garantie en cas de succès | Le message contenant l’information sur l’île cible sera par la suite envoyé à la station de base pour déter-miner l’itinéraire à emprunter une fois en possession d’un trésor.
Scénario principal | 1. Le robot se déplace jus-qu’à la station de base en suivant l’itinéraire calculé par la station de base 2. Le code Manchester est transmis au robot pendant la recharge du condensa-teur 3. Le robot décode le si-gnal reçu 4. Le robot effectue une re-quête au serveur des îles
Scénarios alternatifs | Aucun scénario alternatif, le décodage du code Man-chester doit toujours être réussi

Tableau 2.6 – Cas d’utilisation - Décoder le code Manchester

CHAPITRE 2. DESCRIPTION DES CAS D’UTILISATION | 13
Cas d’utilisation | Communiquer avec le serveur des îles
Système | Ordinateur embarqué
Acteurs | Robot
Partie prenante et intérêt | Robot : Une fois la requête effectuée, l’information sur l’île cible est transmise à la station de base.
Préconditions | Le code Manchester doit avoir été décodé.
Garantie en cas de succès | La station de base est en mesure de déterminer la position de l’île cible et une fois la récupération d’un trésor terminée, une trajectoire vers l’île cible peut être calculée.

Scénario principal

Scénarios alternatifs | Aucun scénario alternatif
1. Le robot effectue une requête au serveur des îles en utilisant le message décodé
2. Le serveur renvoie un
message contenant l’information sur l’île cible
3. Cette information est
transmise à la station de
base

Tableau 2.7 – Cas d’utilisation - Communiquer avec le serveur des îles

CHAPITRE 2. DESCRIPTION DES CAS D’UTILISATION | 14
Cas d’utilisation | Déplacer le trésor
Système | Système de reconnaissance visuelle
Acteurs | Robot
Partie prenante et intérêt | Robot : Se déplacer vers un trésor, le récupérer et le déposer sur une île cible afin de respecter le but du projet.
Préconditions | Le robot doit avoir fait le plein d’énergie à la station de recharge afin de soulever le trésor. L’île cible doit avoir été identifiée et une trajectoire valide doit être calculée pour se rendre jusqu’au trésor. Par la suite, une seconde trajectoire est calculée pour déposer le trésor sur l’île cible.
Garantie en cas de succès | La station de base est en mesure de déterminer la position de l’île cible et une fois la récupération d’un trésor terminée, une trajectoire vers l’île cible peut être calculée.
Scénario principal | 1. Le robot se déplace jus-qu’à un trésor en suivant une trajectoire préalable-ment définie 2. Le robot se positionne et soulève le trésor 3. Le robot se déplace jus-qu’à l’île cible 4. Le robot se positionne et dépose le trésor au centre de l’île cible
Scénarios alternatifs | 2-1. Le robot se posi-tionne, mais ne peut sou-lever le trésor 3. Le robot se déplace jus-qu’à la station de recharge Le robot recharge le condensateur

Tableau 2.8 – Cas d’utilisation - Déplacer le trésor

CHAPITRE 2. DESCRIPTION DES CAS D’UTILISATION | 15
Cas d’utilisation | Afficher les informations sur l’état du robot
Système | Station de base
Acteurs | Station de base
Partie prenante et intérêt | Station de base : Les informations critiques du robot peuvent être étudiées en temps réel.
Préconditions | Une communication doit être établie entre le robot et la station de base afin d’échanger ces informations.
Garantie en cas de succès | Divers informations sont affichées sur la station de base.
Scénario principal | 1. Le robot se déplace et communique avec la sta-tion de base 2. La tension du condensa-teur est affichée sur la sta-tion de base 3. La vitesse de chaque moteur est affichée sur la station de base
Scénarios alternatifs | 1-1. Le robot décode le code Manchester
2. La lettre ASCII décodée est affichée sur la station de base
3. Une requête est envoyée
| au serveur des îles
4. La forme et la couleur
de l’île cible sont affichées sur la station de base

Tableau 2.9 – Cas d’utilisation - Afficher les informations sur l’état du robot

CHAPITRE 2. DESCRIPTION DES CAS D’UTILISATION | 16
Cas d’utilisation | Afficher la carte de jeu
Système | Système de reconnaissance visuelle
Acteurs | Robot, caméra world, station de base
Partie prenante et intérêt | Étudiants : Permet d’avoir une rétroaction rapide des résultats calculés par le système de reconnaissance visuelle.
Préconditions | La station de base doit recevoir des images provenant de la caméra world et celle du robot.
Garantie en cas de succès | Les îles, les trésors, le robot ainsi que les itinéraires sont affichés sur la carte en temps réel.
Scénario principal | 1. La caméra world envoie des images à la station de base 2. La surface de jeu, les îles, le robot, ainsi que les trésors visibles sont affi-chés sur la carte de jeu en temps réel
Scénarios alternatifs | Aucun scénario alternatif

Tableau 2.10 – Cas d’utilisation - Afficher la carte de jeu

CHAPITRE 2. DESCRIPTION DES CAS D’UTILISATION | 17
Cas d’utilisation | Calculer les trajectoires
Système | Système de reconnaissance visuelle
Acteurs | Robot, caméra world, station de base
Partie prenante et intérêt | Robot : Le robot doit se diriger en suivant une tra-jectoire prédéfinie, sans jamais entrer en contact avec quoi que ce soit.
Préconditions | La station de base doit recevoir des images provenant de la caméra world et celle du robot. La position de la destination doit être connue. Les destinations pos-sibles sont la station de recharge, un trésor ou l’île cible.
Garantie en cas de succès | Le robot se déplace en suivant l’itinéraire sans touché à un obstacle.
Scénario principal | 1. Une destination est choisie 2. Le système de recon-naissance visuelle analyse la carte de jeu et repère le robot 3. Le système analyse les obstacles présents sur la carte 4. Une trajectoire est cal-culée et transmise au robot
Scénarios alternatifs | Aucun scénario alternatif

Tableau 2.11 – Cas d’utilisation - Calculer les trajectoires

# Chapitre 3

# Familiarisation avec équipements et expériences préliminaires

## 3.1 Structure mécanique

La base mécanique du robot est assurée par les différentes plate-formes et tiges filetées fournies pour le projet, il en revient donc à nous de décider de l’agencement de ces composantes afin de produire un robot mécaniquement efficace. De manière à bien modéliser le robot et ainsi faciliter l’installation de futurs équipements, il fut décidé de réaliser une représentation 3D du prototype. La figure 3.1 présente le dessin ainsi réalisé, bien que grossier il fut construit à partir de mesures exactes effectuées sur le robot. Ce dessin est très utile pour planifier d’avance l’emplacement des différents systèmes qui seront ajoutés au cours du projet en plus de permettre une meilleure planification de l’organisation des circuits électroniques.

On peut remarquer que sur ce dessin l’ordinateur embarqué est situé sur la plate-forme centrale, ce choix est justifié par le fait que nous désirons avoir l’électronique le plus proche possible des moteurs DC afin de limiter la longueur des fils. La batterie LiPO représentée par le bloc bleu est positionnée sur la plate-forme la plus basse de manière à assurer un centre de gravité assez bas. Le bloc jaune représente environ les dimensions des circuits électroniques présents sur cet étage du robot. Bien évidemment, toutes ces composantes seront fixées en place. Bien que le pont en H n’est pas observable sur cette image il est important de noter que celui-ci peut être fixé sous la base en cas de besoin. Le préhenseur présenté à la section 3.2 est représenté sur le devant du robot, la caméra embarquée est installée directement au-dessus de ce dispositif sur l’étage le plus haut. L’utilisation de ce dessin 3D et d’un autre dessin de la borne de rechargement a aussi permis de mesurer, sans faire de prototype de préhenseur, la hauteur adéquate de la bobine de chargement du condensateur afin de bien aligner les deux dispositifs.

18

CHAPITRE 3. FAMILIARISATION AVEC ÉQUIPEMENTS ET EXPÉRIENCES PRÉLIMINAIRES19


Figure 3.1 – Représentation 3D du robot

CHAPITRE 3. FAMILIARISATION AVEC ÉQUIPEMENTS ET EXPÉRIENCES PRÉLIMINAIRES20

## 3.2 Système de préhenseur et d’électroaimant

Afin de rendre le préhenseur le plus simple possible mécaniquement, nous choisissons de le faire en forme d’équerre. Aux deux extrémités de l’équerre sont situés l’électroaimant et le secondaire du transformateur qui permet de charger le condensateur d’alimentation de l’électroaimant. Il devient donc très aisé d’aligner le système de recharge avec la station de recharge ainsi que de soulever les trésors en faisant tourner l’équerre de 90 degrés dans un sens ou dans l’autre. Cette rotation est assurée par un servomoteur situé au centre de l’équerre. La figure 3.1 est une représentation du système mécanique du préhenseur. Le dessin 3D permet de se faire une bonne idée des dimensions du bras du préhenseur de manière à ce qu’il soit efficace. Un servomoteur présentant suffisamment de couple (6.4Kg · cm à 6V) permet d’actionner le préhenseur.

L’électroaimant est un modèle pré-fait acheté en ligne. Il s’agit du modèle Grove de la compagnie seeed (voir section 3.10). Cet aimant peut soulever une charge de 1kg pour un courant de 400mA. Ce système vient aussi avec un système de contrôle réalisé à partir d’un transistor de commutation. En assumant que la force générée par l’aimant dépend quadratiquement du courant le parcourant et en sachant que le poids des trésors est de 30g l’unité, on estime le courant nécessaire pour soulever les trésors autour de 5mA. Pour avoir une marge de sécurité ainsi que de pouvoir attirer les trésors «à distance», on augmente ce courant à 20mA. Le courant dans l’électroaimant est contrôlé par une source de courant à diode Zener (voir figure 3.2).

L’énergie nécessaire pour soulever un trésor pendant 10 minutes par l’électroaimant est de 60J (U = 5V × 20mA × 10min × 60s/min). Un condensateur de 0.5F à 5V contient 62.5J d’énergie (U = 0.5 × C × V

2
). C’est donc cette valeur de condensateur qui est choisie pour alimenter l’électroaimant.

Afin de permettre de faire des tests ainsi que de s’assurer un degré de sécurité, un condensateur de 1F est également considéré dans le design de ce système.

CHAPITRE 3. FAMILIARISATION AVEC ÉQUIPEMENTS ET EXPÉRIENCES PRÉLIMINAIRES21


Figure 3.2 – Source courant à diode Zener

## 3.3 Contrôle de la caméra

La caméra embarquée est contrôlée par les servomoteurs fournis qui permettent à la caméra un déplacement sur son axe horizontal et vertical afin d’augmenter le champ de vision du robot. De manière à contrôler le Polulu Maestro, des commandes sont envoyées par USB à partir de l’ordinateur embarqué situé sur le robot. Le Pololu est facilement contrôlable par du code en langage C géré par l’ordinateur embarqué. De manière à se familiariser avec le fonctionnement de ce système nous utilisons le Maestro Control Center afin de voir quelles sont les limites du champ de vision de cette caméra. Sur la figure 3.3 on voit que le robot peut facilement voir le sol directement devant lui, ceci est utile afin de repérer les trésors, les îles et même la station de recharge à des distances très courtes. On remarque aussi qu’il est possible de fixer des limites logicielles de mouvement pour les différents servomoteurs, une fonctionnalité qui facilitera l’implantation du contrôle de la caméra.

CHAPITRE 3. FAMILIARISATION AVEC ÉQUIPEMENTS ET EXPÉRIENCES PRÉLIMINAIRES22


Figure 3.3 – Vision au sol du robot à partir de la caméra embarquée

CHAPITRE 3. FAMILIARISATION AVEC ÉQUIPEMENTS ET EXPÉRIENCES PRÉLIMINAIRES23

## 3.4 Contrôle des moteurs

Afin de commander les moteurs du robot, il est nécessaire d’avoir une routine d’asservissement. Pour envoyer les commandes aux moteurs DC, l’Arduino Mega est choisi. Celui-ci possède une vitesse d’horloge de 16 MHz et 256kB de mémoire flash pour 45$ [2], ce qui est un bon équilibre performance/prix pour les besoins du projet.

Les moteurs utilisés pour entraîner les roues du robot possèdent 6400 valeurs de position par rotation. Si une interruption est effectuée à chaque modification de cette valeur, on risque d’empêcher l’exécution complète d’une boucle d’asservissement entre deux interruptions. Donc, si une interruption est levée à chaque modification de la position, il faut s’assurer que le calcul de la vitesse de rotation se fasse après un nombre multiple d’interruptions, avec un compteur de temps.

Pour ce qui a trait à la communication avec les moteurs DC, un shield Adafruit se connectant directement sur l’Arduino Mega est utilisé. Avec celui-ci, il est possible de générer des ondes modulées (PWM) servant à contrôler les quatre roues individuellement, avec chacune une résolution de 8 bits et jusqu’à 1.2A par canal[3]. Cette division de la commande est utile lors d’un déplacement en diagonale, et pourrait également être utile pour continuer le fonctionnement dans le cas d’une roue défectueuse. Ce dispositif est utilisé pour contrôler les moteurs pour les premiers tests, bien évidemment l’utilisation du pont en H fournit fera aussi l’objet de tests lorsque la batterie et l’alimentation seront disponibles.

En résumé, l’ordinateur envoie des instructions de direction au microcontrôleur Arduino, qui exécute alors une routine de déplacement. Celle-ci est basée sur un asservissement de vitesse, déterminée par des interruptions lors de la rotation des servomoteurs. Les commandes de l’Arduino sont alors communiquées aux roues à l’aide d’un shield Adafruit permettant de leur délivrer de la puissance.
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

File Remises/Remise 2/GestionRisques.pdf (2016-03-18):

Type de risque | Niveau de priorité (1-faible, 5-élevé) | Conséquences de l'occurrence du risque | Coûts en performance associé au risque | Probabilité d'occurrence
Défectuosité d'une LED du sytème de transmission du code Manchester | 3 | Impossibilité de recevoir le code ASCII correspondant à l'île mystère | Performance nulle | 5%
Sensibilité de la détection des couleurs à la lumière ambiante | 5 | Impossibilité d'identifier correctement les îles | Système non fonctionnel en cas d'éclairage très différent à celui de test | 30%
Branchement erroné d'un des appareils | 2 | Malfonctions et/ou dommages aux systèmes | Performances nulles où diminuées selon les systèmes affectés | 10%
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

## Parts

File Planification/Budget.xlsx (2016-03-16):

Achat de matériel
Article | Quantité | Prix unitaire | Prix total | Achat par | Montant à rembourser | Remboursé | Valeur sur le robot
Buck | 3 | 10.28 $ | 30.83 $ | MS | 4.40 $ |  | 20.55 $
Shipping Buck | 1 | 33.25 $ | 33.25 $ | MS | 4.75 $
Batterie + Kit | 1 | 169.03 $ | 169.03 $ | JB | 24.15 $ |  | 76.26 $ | MS : | JB:
Shipping batterie | 1 | 37.85 | 37.85 $ | JB | 5.41 $ |  |  | 30.11 $ | 38.17 $
Arduino Mega | 1 | 44.99 | 44.99 $ | MS | 6.43 $ | non-nécessaire | 44.99 $
Servo | 1 | 20.53 | 20.53 $ | MS | 2.93 $ | non-nécessaire | 20.53 $
Électroaimant+shipping | 1 | 19.27 | 19.27 $ | MS | 2.75 $ |  | 12.79 $
Importation batterie | 1 | 34.80 $ | 34.80 $ | JB | 4.97 $
Cœur bobine | 3 | 3.00 $ | 9.00 $ | EB-MS | 1.29 $ | non-nécessaire | 9.00 $
PCB alim + pièces | 1 | 45.60 $ | 45.60 $ | MS | 6.51 $ |  | 3.60 $
PCB Manchester+pièces | 1 | 23.55 $ | 23.55 $ | MS | 3.36 $ |  | 13.55 $
Connecteur batterie | 1 | 1.50 $ | 1.50 $ | JB | 0.21 $ |  | 1.50 $
Condensateurs | 1 | 9.00 $ | 9.00 $ | MS | 1.29 $ |  | 9.00 $
Pièces connections | 1 | 4.00 $ | 4.00 $ | MS | 0.57 $ |  | 4.00 $
PCB connections | 1 | 10.00 $ | 10.00 $ | MS | 1.43 $
PCB Chargement | 1 | 10.00 $ | 10.00 $ | MS | 1.43 $
PCB Manchester v2 | 1 | 10.00 $ | 10.00 $ | MS | 1.43 $
PCB Chargement v2 | 1 | 14.00 $ | 14.00 $ | JB | 2.00 $
PCB connections v2 | 1 | 10.00 $ | 10.00 $ | JB | 1.43 $
PCB recharge+pièces | 1 | 15.30 $ | 15.30 $ | MS | 2.19 $ |  | 5.30 $
 |  |  | 0.00 $ |  | 0.00 $
 |  |  | 0.00 $ |  | 0.00 $
 |  |  | 0.00 $ |  | 0.00 $
 |  |  | 0.00 $ |  | 0.00 $
 |  | TOTAL | 552.50 $ | TOTAL | 78.93 $ | TOTAL | 221.07 $
 |  |  |  |  |  | Budget restant | 78.93 $

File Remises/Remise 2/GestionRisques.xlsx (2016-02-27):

Type de risque | Niveau de priorité (1-faible, 5-élevé) | Conséquences de l'occurrence du risque | Coûts en performance associé au risque | Probabilité d'occurrence | Coût estimé du risque | Plan de réduction du risque | Responsable du risque
Défectuosité d'une LED du sytème de transmission du code Manchester | 3 | Impossibilité de recevoir le code ASCII correspondant à l'île mystère | Performance nulle | 5% |  | Possiblité d'ajouter de la redondance en plaçant plusieurs LED de réception et transmission | E. Bourque
Sensibilité de la détection des couleurs à la lumière ambiante | 5 | Impossibilité d'identifier correctement les îles | Système non fonctionnel en cas d'éclairage très différent à celui de test | 30% |  | Tester le système avec plusieurs variantes d'éclairages dans la pièce d'évaluation (PLT-3109) | S. Garvin
Branchement erroné d'un des appareils | 2 | Malfonctions et/ou dommages aux systèmes | Performances nulles où diminuées selon les systèmes affectés | 10% |  | Identifier les bornes de branchement et les différents fils par un système de couleur | J. Brown
Batterie pas suffisamment chargée lors de l'évaluation | 1 | Durée de vie du système réduite | Performances diminuées si l'évaluation se poursuit longtemps suite au premier round | 5% |  | Brancher la batterie suffisamment longtemps avant l'essai pour la recharger correctement | J. Brown
Échec de connection au serveur des îles | 5 | Impossibilité de recevoir la description de l'île mystère | Performance nulle | 5% |  | Possiblité d'assurer une routine de tentatives de connections suite à un échec | JM. Provencher
Échec de détection du robot par la caméra monde | 5 | Impossibilité de calculer une trajectoire | Performance nulle | 5% |  | Installer un carton de couleur différente des îles sur le robot ou installer un motif sur celui-ci | S. Garvin
Échec de détection de la station de recharge | 3 | Impossibilité de bien s'aligner sur la station de recharge | Charge du condensateur compromise et efficacité de la transmission du code Manchester réduite | 15% |  | Programmer une position fixe à la station de base et la concevoir d'une couleur facilement identifiable par la caméra embarquée | X. Kedzierski
Décodage erroné du code Manchester | 3 | Impossibilité de recevoir la bonne description de l'île mystère | Performance nulle | 10% |  | Possibilité de recevoir et décoder plusieurs fois le code avant de l'envoyer au serveur et donc d'éliminer les mauvais décodages | M. Sylvain
Échec d'ouverture et/ou lancement du programme à l'ouverture du mini-pc | 5 | Impossibilité de commencer la tâche | Performance nulle | 5% |  | Possibilité de désactiver les mises à jour sur le système d'exploitation | JM. Provencher
Échec de la connection entre la station de base et le robot | 3 | Impossibilité d'afficher les données transmisses par le robot | Perte des points liés à l'affichage des données | 5% |  | Possibilité d'établir une routine de tentatives de connections suite à un échec comme pour le serveur des îles | JM. Provencher
Trésor échappé par le robot | 4 | Perte d'un trésor et nécessiter de recharger le condensateur en plus de trouver un autre trésor | Perte de temps lors de l'essai et possibilité de manquer de temps | 15% |  | Tester le temps de décharge du condensateur lorsque l'électroaimant est solicité. Possibilité de prendre un condensateur de capacité plus élevé | E. Bourque
Bris d'un équipement fourni pour le projet | 4 | Nécessité de trouver un équipement de remplacement | Performances réduites si le nouvel équipement est moins performant | 2% | 20$/membre + nouvel équipement | Nécessité de lire les fiches techniques de chaque appareil pour tout les membres ainsi que de ranger correctement l'équipement | M. Sylvain
Perte d'un membre d'équipe (abandon, hospitalisation, etc) | 2 | Nécessité pour les autres membres de se partager la tâche du membre manquant | Systèmes moins performants ou moins testés par manque de temps des autres membres | 2% |  | Documenter son avancement pour chaque système conçu individuellement afin de faciliter la reprise du travail par un autre membre de l'équipe | M. Sylvain
Non respect des délais de livraison des documents à produire pour les livrables | 5 | Nécessité par les autres membres de terminer le travail pour les autres ou devoir remettre un livrable incomplet | Perte de points liés aux sections manquantes ou moins raffinées du livrable | 15% |  | Vérification périodique de l'avancement des travaux par le chef d'équipe ainsi que mise en place d'un "deadline" pour la remise des travaux un jour ou deux avant la remise du livrable | M. Sylvain
Dépassement du budget du projet | 3 | Nécessité de retirer des pièces du robot pour arriver en dessous du 300$ imposé | Performances réduites si le nouvel équipement de remplacement est moins performant ou plus complexe à intégrer | 5% |  | Assigner à un membre de l'équipe la charge de conserver un relevé du coût des pièces placées sur le robot ainsi que les factures | M. Sylvain
Mauvaise estimation du temps de travail nécessaire à un système | 2 | Nécessité de passer plus de temps sur le système correspondant | Perte de temps de travail sur d'autres systèmes | 10% |  | Évaluer hebdomadairement l'avancement du travail de chacun et attribution de ressources supplémentaires pour finir le travail | M. Sylvain
Perte des factures détaillants les achats | 1 | Possibilité de non-remboursement et difficulté de justification du coût du robot | Échec du critère sur le coût | 2% |  | Possibilité de photocopier les factures | M. Sylvain
Mauvaise communication entre les membres de l'équipe | 3 | Possibilité de faire du travail en double ou de faire une tâche non nécessaire | Perte de temps de travail | 5% |  | Réaliser un compte rendu de chaque réunion et de la tâche de chacun par un secrétaire | C. Magnan
Manque de motivation de l'équipe | 2 | Manque de volonté à travailler sur le projet | Perte de temps de travail et travail bâclé | 5% |  | Possibilité par chaque membre de discuter en réunion des avancements de sa charge de travail pour conserver l'intérêt des autres et chercher de l'aide en cas de besoin | M. Sylvain
Défectuosité d'une pièce lors de la réception ou de l'achat de celle-ci | 2 | Nécessité de racheter la pièce | Perte de temps de test et de conception | 2% | 10-20$/membre | Éviter d'acheter des pièces avec des délais de livraison important | M. Sylvain
Échec de l'integration entre 2 systèmes | 5 | Nécessité de modifier ou de changer complètement de système | Perte de temps de travail et de performance si le nouveau système est moins bon | 10% |  | Vérifier les fiches techniques des produits pour vérifier leur compatibilité avec d'autres systèmes | J. Brown

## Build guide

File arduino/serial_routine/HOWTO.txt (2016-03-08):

Upon boot, the arduino code will setup up the PIDs accordingly. No command required.

These ascii characters need to be sent to move the robot.

'8' (56) = UP
'6' (54) = RIGHT
'4' (52) = LEFT
'0' (50) = DOWN 

Special functions have been added to serial_experimental. Those are
'7' (55) = TURN LEFT
'9' (57) = TURN RIGHT

=================================================================================
SENDING ANYTHING ELSE STOPS THE WHEELS ENTIRELY UNTIL A VALID TRANSMISSION OCCURS
=================================================================================

After the first byte has been sent, a second byte has to be sent to determine the distance travelled. This distance so far is arbitrary, but sorry not, in serial_experimental this value is worth one sixteenth of a wheel diameter's distance per entry value. Every falling edge, duration will decrease by one. Serial_experimental uses the pins 18, 19, 20 and 21 to read, so make sure to change the connections if you want to try it out!

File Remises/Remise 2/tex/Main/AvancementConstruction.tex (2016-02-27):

\chapter{Avancement de la construction du système}
\label{s:AvancementConstruction}

\section{Structure mécanique}
\label{s:structure_mecanique}

\input{tex/Sylvain/Structure_mecanique.tex}

\section{Communications sans fil}
\label{s:communications_sans_fil}

\input{tex/Provencher/Communications.tex}

\section{Alimentation}
\label{s:alimentation}

\input{tex/Brown/Alimentation.tex}

\section{Contrôle et asservissement des moteurs}
\label{s:controle_asservissement}

\input{tex/Magnan/Asservissement_moteurs.tex}

\section{Préhenseur et électroaimant}
\label{s:prehenseur_electroaimant}

\input{tex/Bourque/Prehenseur_electroaimant.tex}

\section{Code Manchester}
\label{s:Manchester}

\input{tex/Sylvain/Manchester.tex}

\section{Induction pour recharge}
\label{s:induction_recharge}

\input{tex/Bourque/Induction_recharge.tex}

\section{Interface de la station de base}
\label{s:interface_station}

\input{tex/Garneau/Interface_station.tex}

\section{Planification de la trajectoire}
\label{s:planification_trajectoire}

\input{tex/Garvin/Planification_trajectoire.tex}

\section{Contrôle de la caméra}
\label{s:controle_camera}

\input{tex/Provencher/Controle_camera.tex}

\section{Système de vision}
\label{s:systeme_vision}

\input{tex/Kedzierski/Systeme_vision.tex}

\section{Localisation des îles, des trésors et du robot}
\label{s:localisation}

\input{tex/Kedzierski/Detection_elements.tex}

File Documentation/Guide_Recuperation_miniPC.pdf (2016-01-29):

# Design 3 Restauration d’un mini-PC :

(Si vous avez installé un OS différent de l’image initiale sur le mini-PC, consultez l’annexe à la fin de ce document pour créer une clé USB bootable de CloneZilla.)

1- Démarrage de CloneZilla

- Votre Mini-Pc doit être connecté par cable au réseau de génie électrique ou à internet, ainsi qu’à un écran et clavier.
- Redémarrez votre mini-PC et à l’étape (grub) de Linux choisissez l’option « récupération ». Dans le cas où vous utilisez une clé USB en raison d’une réinstallation, choisissez l’option « Boot USB » tel que décrit dans guide-2016.doc. Le logiciel CloneZilla sera lancé. En cas de problèmes un assistant du cours pourra vous aider à faire un démarrage USB via le BIOS.

2- Utilisation de CloneZilla

- Sélectionnez le clavier et keymaps par défaut, en appuyant sur [Enter] à 2 reprises. Faites ensuite [Enter] à nouveau pour démarrer CloneZilla.
- Choisissez l’option « device-image » en appuyant sur [Enter] et ensuite l’option ssh_server (2ème dans la liste).
- Pour la configuration réseau sélectionnez DHCP. Afin de rejoindre le serveur avec l’image à restaurer, utilisez pika.gel.ulaval.ca (ou directement 132.203.14.64) comme adresse. Confirmez le port par défaut (22).
- Vous devez ensuite entrez votre idul comme nom d’usager pour l’accès au serveur au lieu de la valeur « root » par défaut.
- Utilisez comme répertoire pour l’emplacement de l’image « /d3img »
- À l’étape suivante entrez « yes » pour accepter la clé de sécurité du serveur et entrez votre mot de passe (NIP). Appuyez à nouveau sur [Enter] si la connexion a réussi.
- Choisissez l’option « Expert », et ensuite « restoredisk ». On vous présentera l’image à restaurer. Soit « 2016-01-14-initiale […] ». Faites [Enter] pour continuer
- On vous présentera le disque où la restauration aura lieu. Soit : « sda 64.0GB_PLEXTOR_PX-64M6M [… ] » Faites [Enter]

- Décochez le premier paramètre en appuyant sur la touche [espace] « -g auto Reinstall grub in the client disk MBR » et faite [Ok]
- Sélectionnez la première option « Use the partition table from the image » et faite [Ok]
- Sélectionnez « -p true » et appuyez sur [Ok]. Répondez « y » 2 fois pour démarrer la restauration
- Lorsque la restauration est terminée choisissez l’option poweroff et selon le cas retirez la clé USB une fois le système arrêté.

2- Reconfiguration du réseau sans-fil Eduroam

- Une fois votre système de nouveau en fonction, remettez en place le compte pour l’accès au réseau sans-fil eduroam avec les informations fournies à votre équipe. Utilisez la commande « sudo /root/config_reseau » ou encore le lien du bureau tel que décrit dans le document « guide-2016.doc »

Annexe- Création d’une clé USB bootable (CloneZilla)

Cette procédure permet de créer une clé USB capable de remettre les mini-PC à leur état initial, en restaurant l’image du disque dur via le logiciel CloneZilla. Pour réaliser cette opération vous aurez besoin d’une clé USB, d’un portable sous Windows. Pour d’autres systèmes que Windows, vous pouvez vois référer à cette page : http://clonezilla.org/liveusb.php

- Sous Windows téléchargez l’outil Tuxboot à partir du web : http://tuxboot.org/download/
- Branchez une clé USB dans votre appareil et exécutez l’application (ex : tuxboot-0.8.3.exe)
- Cliquez « update » afin d’obtenir la liste des versions de CloneZilla disponibles :

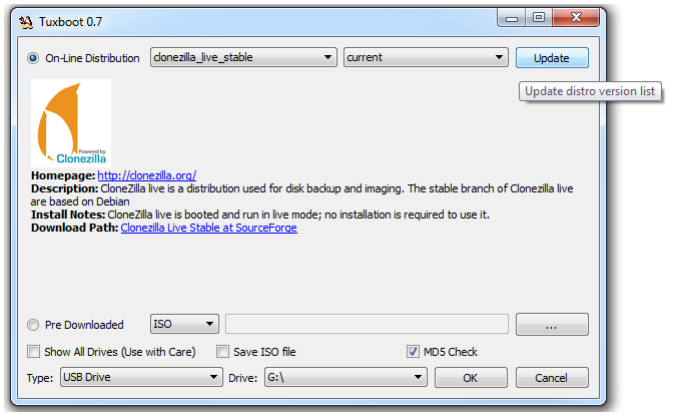
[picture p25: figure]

- Attendez le rafraichissement et choisissez la version amd64 (ex : 2.3.1-18-amd64) des images disponibles sous « current » (dernière position.)
- Vérifiez que le disque de destination correspond bien à votre clé USB et appuyez sur « OK » Attention le contenu précédent de votre clé pourrait être perdu. Faites « Exit » lorsque l’installation de la clé est terminée

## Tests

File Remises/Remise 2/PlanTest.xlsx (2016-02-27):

Niveau | Sous-niveau | Paramètres critique | Exigence | Méthode de vérification | Équipement requis | Méthode de test
Alimenter les éléments du système de façon sécuritaire | Alimenter le robot avec une batterie unique | Tension minimum de la batterie, variation de tension des régulateurs | 21V ±0.2V | Test | Robot, batterie, circuit d'alimentation, multimètre | Vérifier les différents niveaux de tension et leur stabilité à l'aide du multimètre, vérifier le temps de décharge de la batterie, vérifier que la puissance maximale de la batterie est suffisante
 | Charger le condensateur jusqu'à une tension précise | Temps de recharge, variation de tension du condensateur | 90 secondes ±0.5V | Test | Condensateur, station de recharge, chronomètre | Chronométrer le temps de recharge du condensateur, arrêter la recharge lorsque la tension désirée est atteinte
 | Signaler une alerte en cas de danger | Temps avant alarme | 10 secondes | Test | Batterie, alarme de la batterie | Faire descendre la tension de la batterie et vérifier que l'alarme sonne
 | Protéger adéquatement les élements du système | Courant maximum | 10A max à la sortie de la batterie | Analyse | Batterie, circuit d'alimentation | Vérifier l'intégralité des fusible
Exécuter la routine de façon autonome | Démarrer les routines du robot de façon sans intervention extérieure | Temps de démarrage | 2 minutes | Test | Ordinateur embarqué | Ouvrir l'ordinateur embarqué et s'assurer que la routine démarre à son ouverture
 | Confirmer le départ à partir de la station de base | Délai avant départ | 5 secondes | Test | Station de base, ordinateur embarqué | Appuyer sur le bouton de départ sur la station de base et s'assurer que l'ordinateur embarqué reçoit bien le signal et exécute la routine
 | Exécuter la routine en moins de 10 minutes | Temps d'exécution | 10 minutes | Test | Tous les sytèmes fonctionnels | Faire la routine complète avec le robot et chronométrer le temps requis
 | Confirmer la fin de l'exécution et afficher le temps écoulé sur la station de base | Précision du temps écoulé | ±1% | Analyse | Ordinateur embarqué, station de base, chronomètre externe | S'assurer que le chronomètre interne du système fonctionne et que le signal d'arrêt de la routine se fait à la fin de la routine
Interpréter une vision monde et embarquée de la table | Reconnaître les îles | Précision sur la position Efficacité de la détection de la forme ou de la couleur | ±2cm 97% | Test | Caméra monde, caméra embarquée table de jeu, îles | Déposer des îles sur la table et vérifier que le système de vision peut les détecter. Le faire dans différentes condition de luminosités, avec différentes personnes autour de la table et avec en portant des chandails de couleurs variées
 | Distinguer les trésors | Précision sur la position | ±0.5cm | Test | Caméra monde, caméra embarquée, table de jeu, trésors | Déposer des trésors sur la table et vérifier que le système de vision peut les détecter. Le faire dans différentes condition de luminosités, avec différentes personnes autour de la table et avec en portant des chandails de couleurs variées
 | Reconnaître le robot | Précision sur la position | ±5cm | Test | Caméra monde, table de jeu, robot | Déposer le robot sur la table et vérifier que le système de vision peut le détecter. Le faire dans différentes condition de luminosités, avec différentes personnes autour de la table.
 | S'enligner sur la station de recharge | Précision sur la position | ±0.5cm | Test | Caméra embarquée, station de recharge | Vérifier la détection adéquate de la station de recharge. Le faire dans différentes condition de luminosités, avec différentes personnes autour de la table et avec en portant des chandails de couleurs variées
 | Établir une trajectoire à partir de la vision | Fréquence de mise à jour de la trajectoire | 0.2 Hz | Test | Station de base, robot, caméra monde, chronomètre externe | Déposer le robot sur la table et le déplacer. Vérifier que la vitesse à laquelle la trajectoire affichée sur la station de base se met à jour.
Se déplacer de façon autonome | Commander les roues | Déplacement minimal, pourcentage de déviation en déplacement | 1cm 3% | Test | Microcontrôleur, roues | Faire déplacer le robot à l'aide de commande simples. Bloquer les roues et laisser le système aller afin de vérifier la stabilité de l'asservissement. Vérifier la précision des déplacements du robot
 | Éviter un contact avec les murs et les îles | Distance maximale d'arrêt | 5cm | Test | Table de jeu, îles, robot | Lors d'un dépassement de commande avec l'asservissement, demander au robot d'arrêter et mesurer la distance parcourue.
 | Déplacer la caméra embarquée | Temps de rotation minimale | 1 seconde | Test | Micocontrôleur, pololu, caméra embarquée | Vérifier la précision du déplacement de la caméra embarquée
Manipuler un trésor à l'aide du préhenseur | Prendre et soulever le trésor | Être capable de soulever un trésor | - | Test | Préhenseur, électroaimant, trésor | Alimenter l'électroaimant et vérifier qu'il peut attirer et retenir un trésor. Faire soulever le trésor à l'aide du préhenseur et s'assurer que le trésor reste collé.
 | Garder le trésor lors du déplacement vers l'îles cible | Durée de la tenue du trésor | 150 secondes | Test | Préhenseur, électroaimant, trésor, chronomètre | Garder le trésor collé sur l'électroaimant et chronométrer le temps avant la chute du trésor. S'assurer que ce temps est suffisament long pour tenir le trésor le temps du déplacement vers l'île cible
 | Déposer le trésor sur l'île cible | Précision du dépôt du trésor | ±2cm | Test | Préhenseur, électroaimant, trésor, robot | Vérifier la précision de l'endroit où le trésor est déposé et que le trésor ne reste pas collé sur l'électroaimant
Afficher en temps réel le statut des élements du système sur la station de base | Afficher les trajectoires (prévue et réelle) du robot | Taux de rafraichissement | 5 secondes | Analyse | Station de base, robot, caméra monde, ruban à mesuer | S'assurer que la trajectoire prévue s'affiche bien sur la station de base. Vérifier la précision de l'affichage de la trajectoire réelle du robot à l'aide du ruban à mesurer
 | Afficher la position et l'orientation du robot | Taux de rafraichissement | 5 secondes | Analyse | Station de base, robot, caméra monde, ruban à mesuer | Vérifier la précision de l'affichage de la position et de l'orientation du robot à l'aide du ruban à mesurer
 | Afficher la tension aux bornes du condensateur | Taux de rafraichissement Précision de la lecture de la tension | 5 secondes ±0.2V | Test | Station de base, condensateur, microcontôleur, ordinateur embarqué, multimètre | Tester la précision de la lecture de tension par le microcontrôleur à l'aide d'un multimètre externe. Vérifier l'affichage de la bonne tension sur la station de base
 | Afficher la position des îles et des trésors | Taux de rafraichissement | 5 secondes | Analyse | Station de base, table de jeu, trésors, îles, ruban à mesurer | Vérifier que la station de base affiche précisément les îles (la bonne forme, la bonne couleur et la bonne position) ainsi que les trésors à l'aide du ruban à mesurer
 | Afficher la description de l'île cible (forme ou couleur) | Taux de rafraichissement | 5 secondes | Analyse | Station de base | S'assurer que la station de base affiche la bonne description de l'île cible (forme ou couleur)
Communiquer entre les élements du système | Communiquer entre l'ordinateur du robot et le microcontrôleur par UART | Taux de réussite | 95% | Test | Microcontrôleur, ordinateur embarqué | Vérifier le fonctionnement de la communication entre l'ordinateur embarqué et le microcontrôleur, s'assurer qu'aucun paquet n'est perdu lors de la communication
 | Communiquer sans fil entre l'ordinateur du robot et la station de base | Délai de communication maximale | 1 seconde | Analyse | Ordinateur embarqué, station de base | Envoyer des fichiers entre l'ordinateur embarqué et la station de base et s'assurer de leur bonne réception
 | Communiquer sans fil le code Manchester | Taux de réussite de la communication | 95% | Test | Circuit d'émission du code Manchester, circuit de détection du code Manchester | Émettre le code Manchester, le recevoir et s'assurer que les bits reçus sont les bons
 | Communiquer sans fil entre le robot et le serveur des îles | Délai de communication maximal | 5 secondes | Test | Ordinateur embarqué | Vérifier que l'ordinateur embarqué peut se connecter au serveur des îles
 | Décoder et envoyer la bonne lettre au serveur des îles | Taux de réussite du décodage | 98% | Test | Ordinateur embarqué | Générer et décoder un code ASCII avec l'ordinateur embarqué et envoyer la lettre correspondante au serveur des îles

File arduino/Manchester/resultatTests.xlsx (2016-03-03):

valeur testée | répétitions | réussites | pourcentage
0000000 (0) | 15 | 15 | 100
0000001 (1) | 20 | 20 | 100
0000010 (2) | 20 | 20 | 100
0000100 (4) | 15 | 15 | 100
0001000 (8) | 15 | 15 | 100
0010000 (16) | 15 | 15 | 100
0100000 (32) | 15 | 15 | 100
0101010 (42) | 20 | 20 | 100
1000000 (64) | 15 | 15 | 100
1010101 (85) | 15 | 15 | 100
1111111 (127) | 15 | 15 | 100

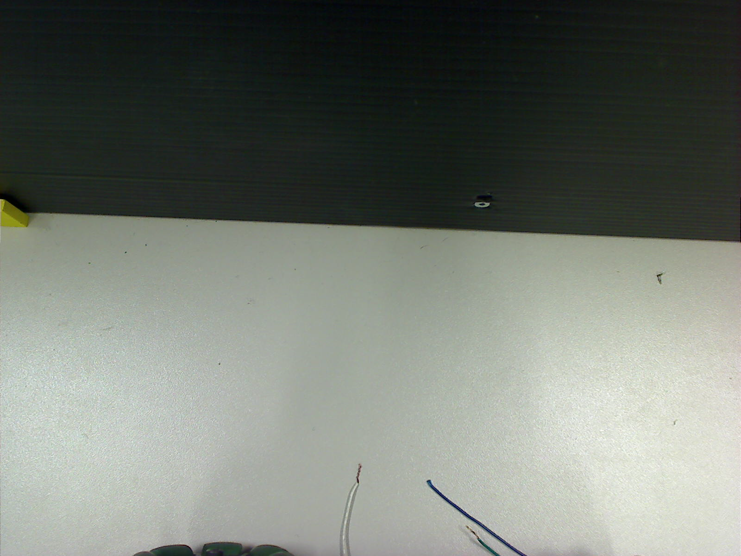
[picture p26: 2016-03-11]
glo/BlackPearl/images/camera_robot/tresors/test_image7.png

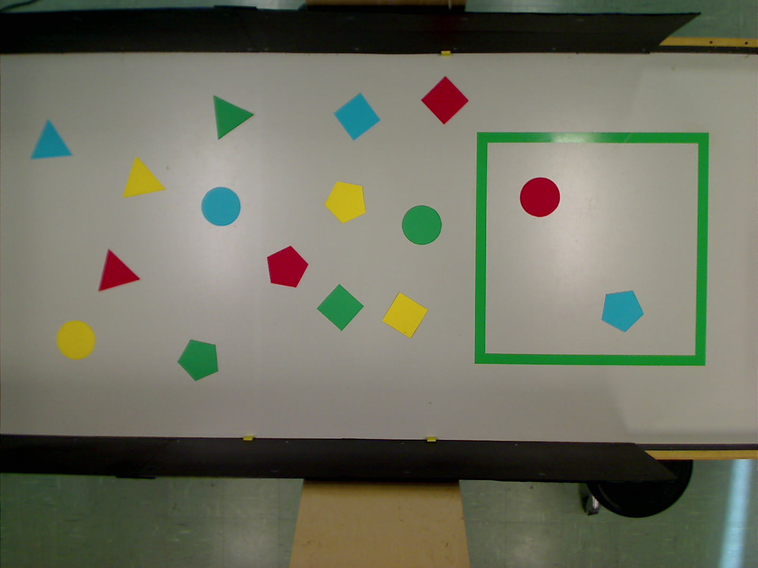
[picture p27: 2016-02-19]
glo/BlackPearl/tests/Image/table2/detection1.png

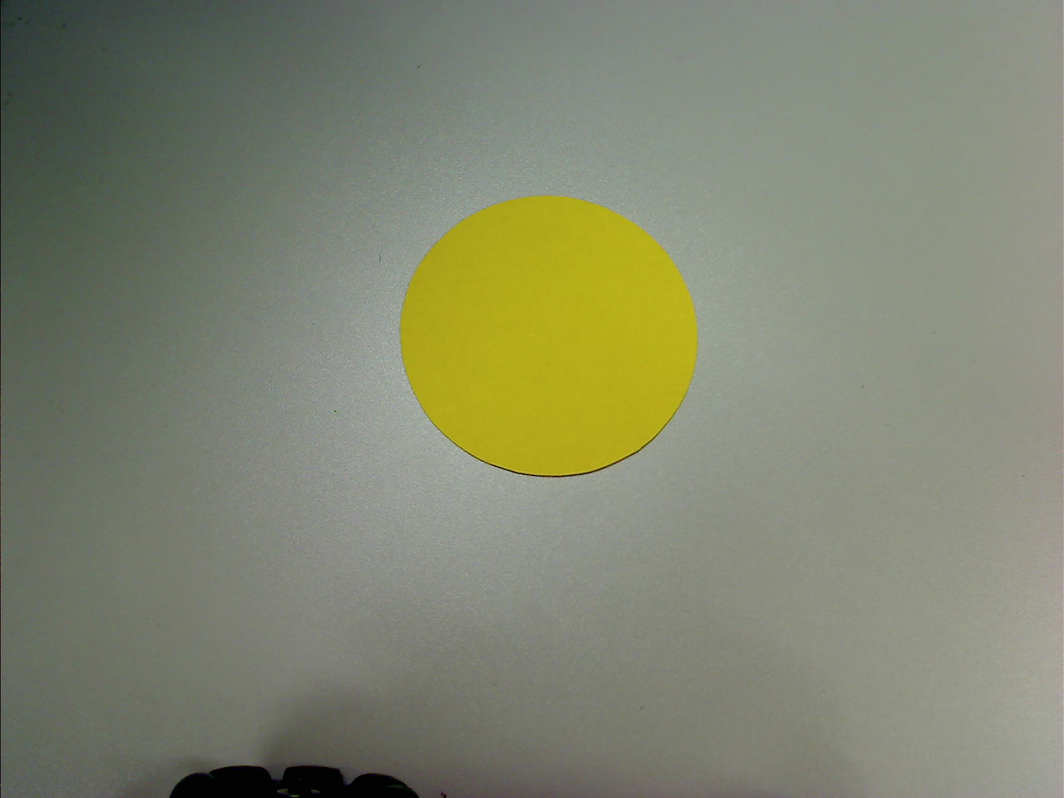
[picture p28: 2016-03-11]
glo/BlackPearl/images/camera_robot/iles/test_image8.png

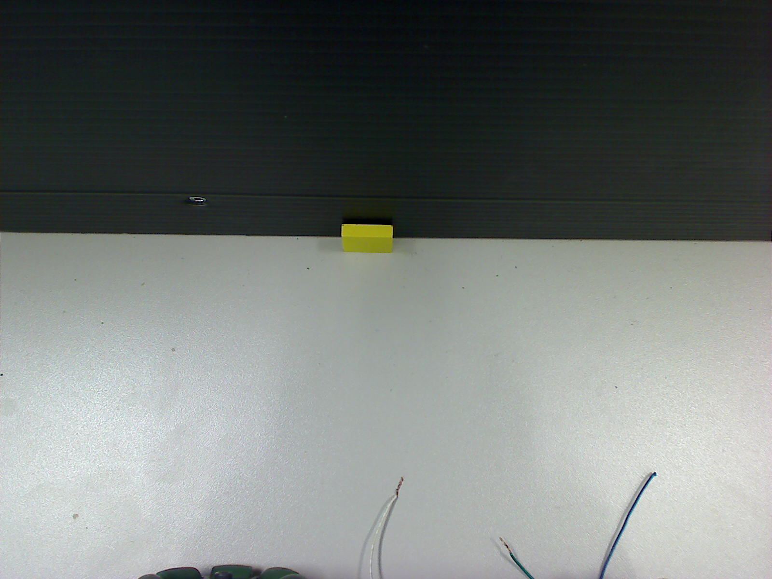
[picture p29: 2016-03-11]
glo/BlackPearl/images/camera_robot/tresors/test_image4.png

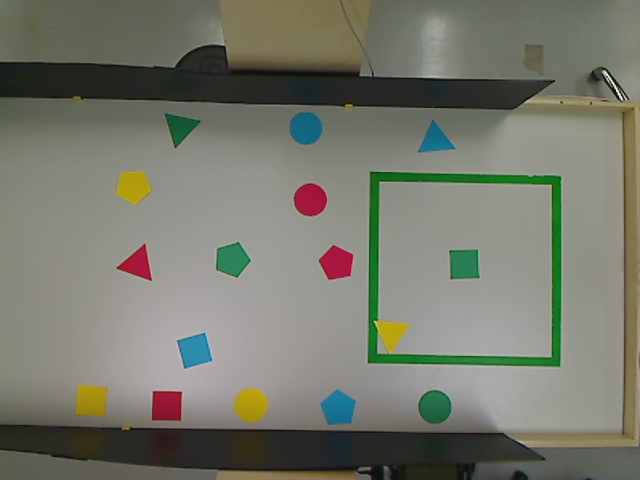
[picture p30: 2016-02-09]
glo/BlackPearl/images/test_image9.png

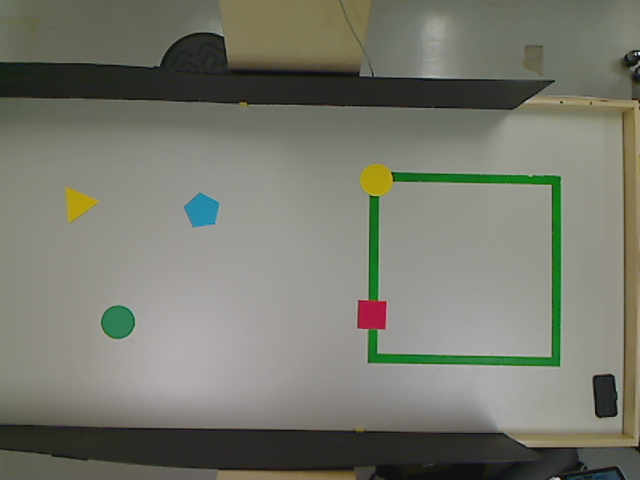
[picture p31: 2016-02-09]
glo/BlackPearl/tests/Image/test_image11.png

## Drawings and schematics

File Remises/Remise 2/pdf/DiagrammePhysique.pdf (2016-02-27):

# Robot

# Station de base

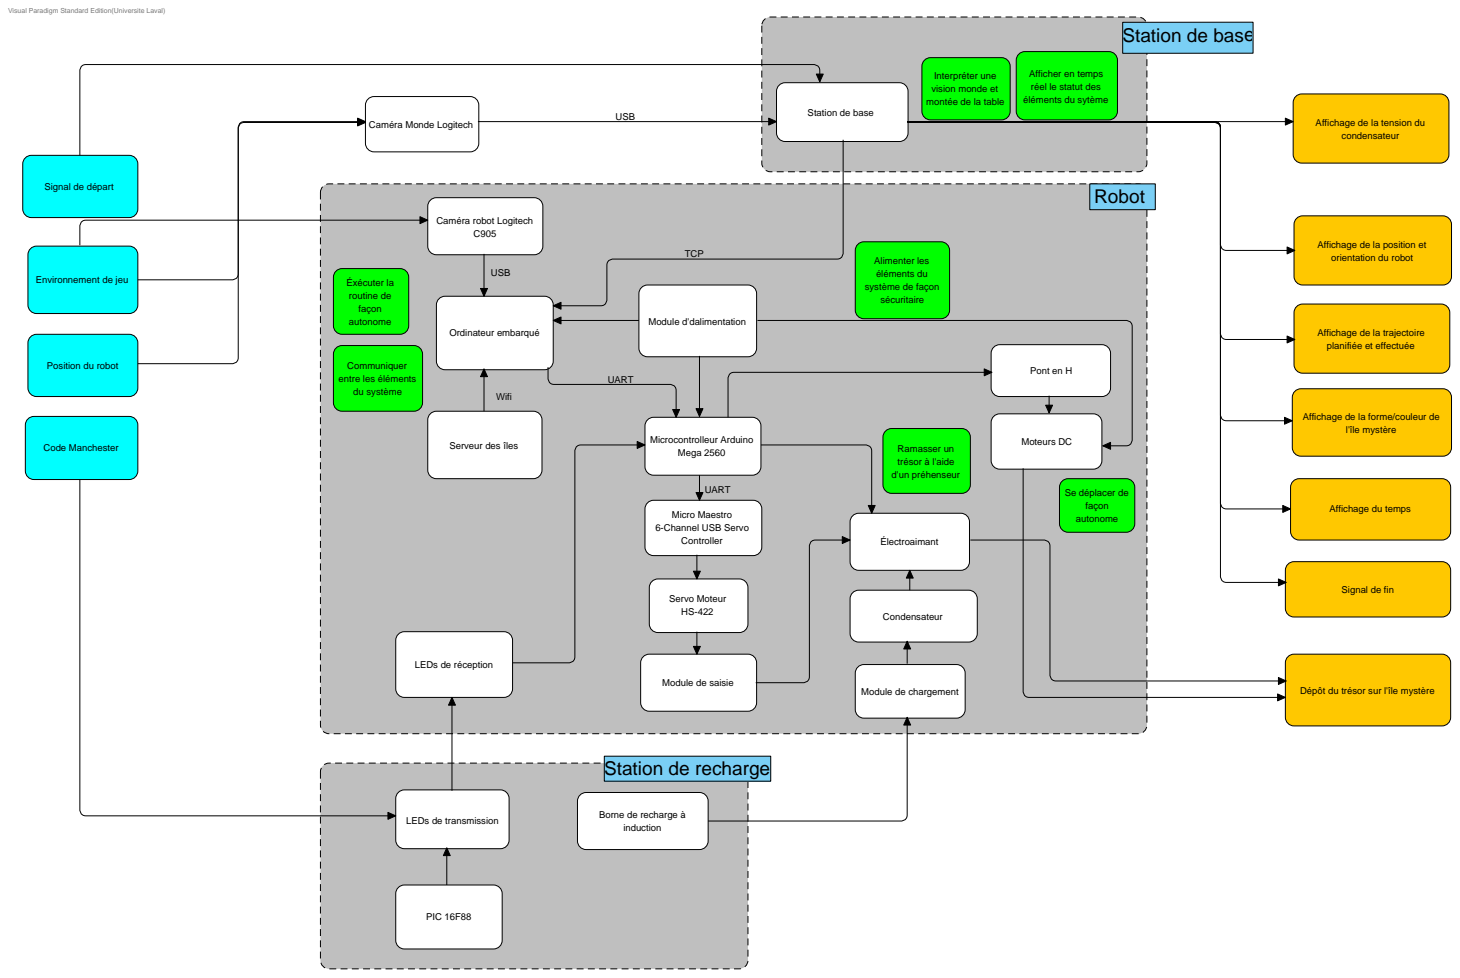
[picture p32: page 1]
Code Manchester; Ordinateur embarqué; Microcontrolleur Arduino Mega 2560; Servo Moteur HS-422; Moteurs DC; Module d'dalimentation; Électroaimant; l'île mystère; Condensateur; Pont en H; PIC 16F88; Éxécuter la routine de façon autonome; Ramasser un trésor à l'aide d'un préhenseur; UART; TCP; USB; Wifi

Visual Paradigm Standard Edition(Universite Laval)

Interpréter une
vision monde et
montée de la table

Afficher en temps
réel le statut des
éléments du sytème

Station de base

Caméra Monde Logitech

Affichage de la tension du
condensateur

Signal de départ

Caméra robot Logitech

Affichage de la position et
orientation du robot

Alimenter les
éléments du
système de façon
sécuritaire

Environnement de jeu

Affichage de la trajectoire
planifiée et effectuée

Position du robot

Communiquer
entre les éléments
du système

Affichage de la forme/couleur de

Serveur des îles

Se déplacer de
façon
autonome

Micro Maestro
6-Channel USB Servo
Controller

Affichage du temps

Signal de fin

LEDs de réception

Module de saisie

Module de chargement

Dépôt du trésor sur l'île mystère

Station de recharge

LEDs de transmission

Borne de recharge à
induction

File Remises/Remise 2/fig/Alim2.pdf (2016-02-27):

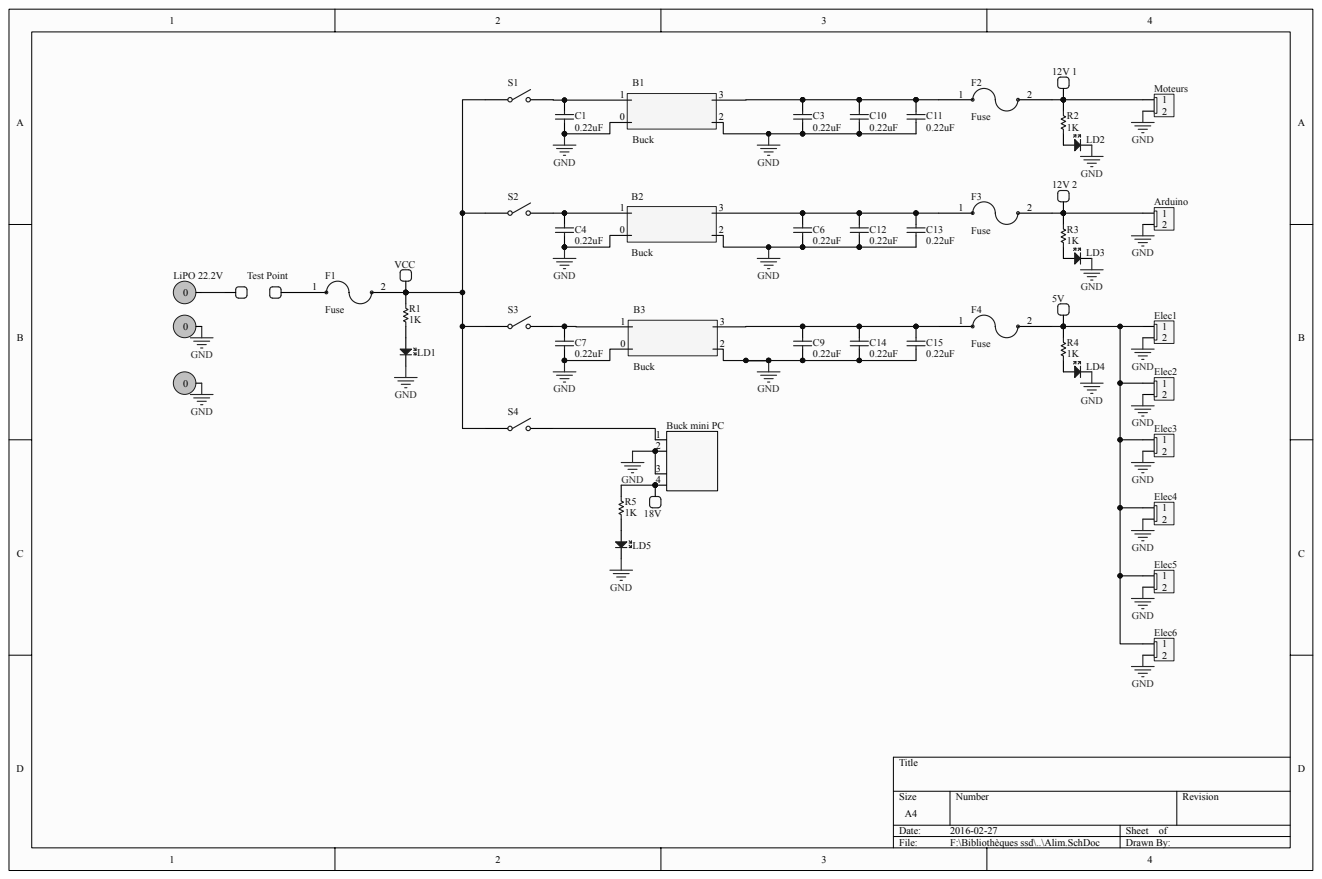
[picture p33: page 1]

Size A4 | Number | Revision

Date: 2016-02-27 | Sheet of
File: F:\Bibliothèques ssd\..\Alim.SchDoc | Drawn By:

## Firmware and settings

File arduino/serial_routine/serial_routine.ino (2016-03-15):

#include <PID_v1.h>
#include <LiquidCrystal.h>



// global value that corresponds to the byte sent by the micro PC by UART.
int incomingByte = 0;
// value that allows a simple switch case
boolean mode = false;
// string used to print on the serial
String action = "";

int pinsDrive[6] = {3, 6, 7, 8, 9, 10};
int pinsRead[4] = {14, 15, 16, 17};
int spdWheels[2] = {255, 0};
unsigned long spdBuffer = 0;
int duration = 0;

double Setpoint[4] = {3000, 3000, 3000, 3000};
double Input[4] = {3000, 3000, 3000, 3000};
double Output[4];

PID firstPID(&Input[0], &Output[0], &Setpoint[0], 0.00005, 0.25, 0, REVERSE);
PID secondPID(&Input[1], &Output[1], &Setpoint[1], 0.000066, 0.30, 0, REVERSE);
PID thirdPID(&Input[2], &Output[2], &Setpoint[2], 0.00005, 0.2, 0, REVERSE);
PID fourthPID(&Input[3], &Output[3], &Setpoint[3], 0.00005, 0.2, 0, REVERSE);

PID pidList[4] = {firstPID, secondPID, thirdPID, fourthPID};

void setup() {
  Serial.begin(9600);
  
  for(int i = 0; i < 6; i++){
    pinMode(pinsDrive[i], OUTPUT);
  }
  
  for(int i = 0; i < 4; i++){
    pinMode(pinsRead[i], INPUT);
    pidList[i].SetMode(AUTOMATIC);
    pidList[i].SetSampleTime(15);
  }
}

void loop() {
  // put your main code here, to run repeatedly:
  if(duration != 0){
    analogWrite(pinsDrive[4], spdWheels[0]);
    analogWrite(pinsDrive[5], spdWheels[1]);
    for(int i = 0; i < (duration*2); i++){
      for(int j = 0; j<4; j++){
        spdBuffer = pulseIn(pinsRead[j], HIGH, 3000);
        if(spdBuffer == 0){
          spdBuffer = 3000;
        }
        Input[j] = (spdBuffer);
        pidList[j].Compute();
        //Serial.print(Input[j]);
        //Serial.print(" - ");
        //Serial.print(Output[j]);
        //Serial.print(";");
      }
      //Serial.println(".");
      //Serial.print(action);
      for(int j = 0; j<4; j++){
        if(Setpoint[j] != 3000){
          analogWrite(pinsDrive[j], Output[j]);
        }
        else{
          analogWrite(pinsDrive[j], 0);
        }
      }
      //Serial.println(incomingByte - i, DEC);
      delay(20);
    }
    for(int i = 0; i<4; i++){
      Setpoint[i] = 3000;
    }
    for(int i = 4; i<6; i++){
        analogWrite(pinsDrive[i], 0);
    }
    Serial.print(action + duration + " completed!");
    duration = 0;
  }
}

void serialEvent(){
    // read the incoming byte:
    incomingByte = Serial.read();
    Serial.write(incomingByte);
    
    if(!mode){
      duration = 0;
      if(incomingByte == 56){
        action = "Moving forward ";
        Setpoint[0] = 800; Setpoint[1] = 800; Setpoint[2] = 3000; Setpoint[3] = 3000; spdWheels[0] = 255, spdWheels[1] = 0;
      }
      else if(incomingByte == 50){
        action = "Moving backwards ";
        Setpoint[0] = 800; Setpoint[1] = 800; Setpoint[2] = 3000; Setpoint[3] = 3000; spdWheels[0] = 0, spdWheels[1] = 255;
      }
      else if(incomingByte == 52){
        action = "Turning left ";
        Setpoint[2] = 800; Setpoint[3] = 800; Setpoint[0] = 3000; Setpoint[1] = 3000; spdWheels[0] = 255, spdWheels[1] = 0;
      }
      else if(incomingByte == 54){
        action = "Turning right ";
        Setpoint[2] = 800; Setpoint[3] = 800; Setpoint[0] = 3000; Setpoint[1] = 3000; spdWheels[0] = 0, spdWheels[1] = 255;
      }
      else{
        action = "Invalid action ";        
        Setpoint[2] = 3000; Setpoint[3] = 3000; Setpoint[0] = 3000; Setpoint[1] = 3000; spdWheels[0] = 255, spdWheels[1] = 0;
      }
      mode = true;
    }
    else if(mode){
      duration = incomingByte;
      mode = false;
    }
}

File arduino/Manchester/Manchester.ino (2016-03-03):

int pinClock = 2;
int pinManchester = 50;
bool stateClock = 0;
bool stateManchester = 0;
bool bitDecode = 0;
bool complete = false;
int compteur = 0;
int nombreDeSuite = 1;

bool arrayCode[32] = {0};
bool arrayBigReset[32] = {0};
bool arrayDecode[7] = {0};
bool arraySmallReset[7] = {0};

int codeSecret = 0;
unsigned int count = 0;
unsigned int countLoop = 0;



void setup()
{
  pinMode(pinClock, INPUT);
  pinMode(pinManchester, INPUT);
  attachInterrupt(digitalPinToInterrupt(pinClock), Reading, RISING);
  Serial.begin(9600);
}

//AttachInterrupt sur changement low a high sur clock pour commencer traitement, faire xor avec clock et manchester, puis mettre résultat dans buffer circulaire de 32 bits et écrire dedans,
//vérifier si on a la série qu'on veut (8x1, 0 et message) sinon reboucle puis écrit mot dans le résultat, mettre delay après clock (1µs ?)

void loop()
{
  if (count != countLoop)
  {
    countLoop = count;
    stateClock = digitalRead(pinClock);
    stateManchester = digitalRead(pinManchester);
    bitDecode = stateClock ^ stateManchester;
      //Serial.println(stateManchester);
      //Serial.println(stateClock);
      //Serial.println(bitDecode);
    arrayCode[compteur] = bitDecode;
    compteur++;
  }

  
  if (compteur == 32 && complete == false)
  {
    Serial.print("Reception:");
    for(int h=0;h<32;h++)
    {
      Serial.print(arrayCode[h]);
    }
    Serial.println(".");
    for (int i = 0; i < 32; i++)
    {
      if (arrayCode[i] == 1)
      {
        for (int j = i; j < i+8; j++)
        {
          if (arrayCode[j+1] == 1)
          {
            nombreDeSuite++;
            
            if (nombreDeSuite > 7 && arrayCode[j+2] == 0)
            {
              Serial.println("Serie terminee, voici le code secret :");
              for (int k = 0; k < 7; k++)
              {
                arrayDecode[k] = arrayCode[k + j + 3];
              }
              for (int b=0;b<7;b++)
              {
                Serial.print(arrayDecode[b]);
              }
              Serial.println(".");
              codeSecret = 0;
              for (int u=0; u<7; u++)
              {
                codeSecret= codeSecret*2+arrayDecode[u];
              }
              Serial.println(codeSecret);
              Serial.println(char(codeSecret));
              memcpy(arrayCode, arrayBigReset, 32);
              memcpy(arrayDecode, arraySmallReset, 7);
              complete = true;
              i = 32;
              break;
            }
          }
          else{
            nombreDeSuite = 1;
          }
        }
      }
    }
    compteur = 0;
  }
}

void Reading()
{
  count++;
}

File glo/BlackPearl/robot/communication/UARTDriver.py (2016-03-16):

import serial
import time


class UARTDriver:
    def __init__(self, comPort, baudRate):
        self.comPort = comPort
        self.baudRate = baudRate
        self.UART = self._initializeUARTCom(self.comPort, self.baudRate)

    def _initializeUARTCom(self, comPort, baudRate):
        UART = serial.Serial(comPort, baudRate)
        time.sleep(2)  # the sleep time is important to make sure we don't send any messages before the initialization is complete
        return UART

    def sendCommand(self, command, parameter):

        if command == 'forward':
            self.UART.write(b'8'.encode())
            self.UART.write(parameter)

        elif command == 'backward':
            self.UART.write(b'2'.encode())
            self.UART.write(parameter)

        elif command == 'left':
            self.UART.write(b'4'.encode())
            self.UART.write(parameter)

        elif command == 'right':
            self.UART.write(b'6'.encode())
            self.UART.write(parameter)

        elif command == 'armUp':
            pass

        elif command == 'armDown':
            pass

        elif command == 'magnetOn':
            pass

        elif command == 'magnetOff':
            pass

        elif command == 'cameraRight':
            self.UART.write(b'a'.encode())

        elif command == 'cameraLeft':
            self.UART.write(b'b'.encode())

        elif command == 'cameraFront':
            self.UART.write(b'c'.encode())

        elif command == 'cameraTreasure':
            self.UART.write(b'd'.encode())

        #To implement when arduino will return command completion confirmation
        #commandComplete = self.UART.read(2)
        #return commandComplete
        return 1

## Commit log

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2016-01-15 on dirait qu'il faut que je push de la scrap pour pusher les fichiers, woops
2016-01-19 description des propriétés
    voilà
    [descriptionPropriete.xlsx]
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2016-01-27 diagramme de propriétés fonctionnelles, version 1
    [descriptionPropriete.xlsx]
2016-01-27 modifTraitementImage
    Ajoute de la fonction findTreasure et modification de la fonction find
    blue afin de reconnaitre la forme bleu cyan prise avec les photos de
    test. Probleme mineur avec le nombre de forme trouvee retournee par le
    programme
2016-01-28 Ajout planification et documentation
    [Budget.xlsx]
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2016-01-28 Ajout documentation
    [Budget.xlsx]
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2016-01-30 faut pas mettre de scrap dans le repo les mecs
    [descriptionPropriete.xlsx]
2016-01-30 Ajout Gantt & renommer DPF
    [DPF.xlsx]
2016-01-30 Fix d'image DPF + demo d'ajout de fichier
    [DPF.xlsx]
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2016-01-30 mega push version pdf des graphiques pis new page pour page avoir de niaiseries de graphiques qui apparaissent trop bas
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2016-01-31 Corrections Latex & ajustement budget
    [Budget.xlsx]
2016-01-31 petitCorrectifTexClasse
    J'ai fait des petites corrections sur le texte a seb
2016-01-31 Ajout de document tex et corrections
2016-01-31 Corrections de fautes
    correction de fautes dans les fichier de préhenseur et de système
    mécanique
2016-01-31 2nd commit. 3 diagrammes de séquence. Je pense que je vais faire un dernier diagramme de séquence
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2016-02-02 ajout frais d'importation dans budget
    [Budget.xlsx]
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2016-02-04 Ajouts Gantt & planification des tâches
    Allez voir les tâches qui vous sont attribuées, possibilité de
    changements
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2016-02-09 communication I2C avec LCD quelconque. On peut envoyer un byte d'abord pour direction, ensuite un byte pour la durée. Durée de mouvement peut être intérrompue par un message I2C.
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2016-02-12 Ajustement budget
    [Budget.xlsx]
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2016-02-13 transition DPF vers tour pour continuer travail
    [DPF.xlsx]
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2016-02-13 Testage, bug de detection pour les tresors, a verifier
2016-02-14 pololuArduinoControl
    4 positions preprogrammed (left right front treasure)
    Communicating to maestro pololu through UART
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2016-02-14 ajustements dossiers
    [DPF.xlsx, GestionRisques.xlsx]
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2016-02-15 Ajout GestionRisques
    [GestionRisques.xlsx]
2016-02-15 Continuation du registre de risques
    [GestionRisques.xlsx]
2016-02-16 ajustement gantt et gestion risque
    [GestionRisques.xlsx]
2016-02-16 Tests unitaires de la vision passent, images de table 2 et 3 en HD ajoutees
2016-02-16 Exigences mises à jour
    [DPF.xlsx]
2016-02-17 ajout budget
    [Budget.xlsx, GestionRisques.xlsx]
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2016-02-17 Ajustements pour interface... Toujours à la recherche de comment afficher en live là dessus.
2016-02-18 Diagramme remise 2
    Diagramme Physique et diagramme des fonctionnalités complétés et
    exportés en PDF dans le dossier remise 2. Sujet à révision et changement
    par les pairs.
2016-02-18 fonctions principales là mais pas propre
    [DPF.xlsx]
2016-02-18 Voilà la DPF mes coquins
    [DPF.xlsx]
2016-02-18 transfer ALL the files
    actually just one
    [DPF.xlsx]
2016-02-18 Refactoring, detection des iles se fait dans une autre classe que le traitement de l'image
2016-02-18 finalisation gestion risques
    [GestionRisques.xlsx]
2016-02-18 Amelioration de la detection sur les autres tables, code de detection stable
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2016-02-19 Actualily good DPF
    [DPF.xlsx]
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2016-02-19 ajustements budget
    [Budget.xlsx]
2016-02-20 Création des fichiers .tex pour le remise 2 et ajustement des dossiers
    [Budget.xlsx]
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2016-02-21 ajustements gestion de risques
    [GestionRisques.xlsx]
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2016-02-22 Commencement de la redaction du systeme de vision et de la localisation des elements
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2016-02-23 Ajustements plan de test
    [PlanTest.xlsx]
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2016-02-24 Interface Basique terminée. IMPORTANT : J'ai fait un changement dans le powerpoint. J'ai rajouté un image, mais comme j'ai openOffice, j'ai sauvegardé en ppt et non en pptx si quelqu'un pouvait faire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
2016-02-24 Implementation de l'interface dans le projet, bouton demarrer initialise le traitement d'image
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2016-02-24 bug fix for fedora wifi com
    gogog
    [client.py]
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2016-02-27 DPF et plan de test fixés, routine mise à jour.
    [DPF.xlsx, PlanTest.xlsx]
2016-02-27 blablabl
    fefe
    [GestionRisques.xlsx]
2016-02-27 image rajoutée, fautes corrigées, clean up
    [serial_routine.ino]
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2016-03-03 manchester fixed
    [resultatTests.xlsx]
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2016-03-08 ajouts budget
    [Budget.xlsx]
2016-03-08 correctedException for TCP client
    corrected error return when server is not ready to retry connection with
    server. Useful if there's a problem with the base station and robot is
    trying to reconnect to the server without failing.
    [TCPClient.py]
2016-03-08 Small fix
    still need to fix receiving file problem (seems to be stall in
    receiving state)
    [TCPClient.py]
2016-03-08 Fixed file sending problem between TCP Client and TCP Server
    Server was waiting for a string from the client but i removed the 'hello
    server' from the client since it was not useful. Added mainStation.py
    and mainRobot.py to start having some "real-life" test on the table.
    Next step: Working on the Linux script to start on embedded computer
    boot.
    [TCPClient.py, UARTDriver.py, mainRobot.py]
2016-03-09 quick fix for linux UART com port
    [mainRobot.py]
2016-03-09 Quick Fix for UARTDriver on Linux
    Fixed "No such file or directory" error on linux by adding a "/" before
    dev/ttyAMC0
    [mainRobot.py]
2016-03-10 l'image réelle provenant de la classe ImageReellle mais appeler du main de l'Interface
2016-03-10 Image virtuelle affiche après avoir clické sur démarrage. Par contre, ne semble pas vouloir afficher les îles détectées.
2016-03-10 Lorsque clicker sur démarrage : Détection des îles et ensuite affichage sur Carte. Une bonne et une mauvaise nouvelle : Ça fonctionne pour tout sauf que pour que la carte affiche quelque chose de nou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
2016-03-12 Interface cree imagereelle et imagevirtuelle, station de base herite pu de pyQt, interface lague pu, Showtime
2016-03-14 JSON commande example
    Exemple des différentes commandes pour les GLO à nous envoyer. Une seule
    commande par fichier JSON et uniquement mettre des paramètres lorsque ce
    sont des commandes de deplacement du robot (en cm) par exemple foward
    backward right left. Faites votre possible pour nous envoyer des
    commandes le plus vite possible cette semaine svp.
2016-03-15 Embedded Camera Control
    Added camera control in the serial routine for the arduino
2016-03-15 New command
    Added new commands to the arduino serial routine and to the UART driver.
    Enable possibility to enter command from the BaseStation
2016-03-15 Error and exception Handling for TCP connection
    Error handling when connection lost due to error between server and
    client. If any error occurs, BaseStation and robot will disconnect and
    retrieve connection.
    [TCPClient.py, mainRobot.py]
2016-03-15 fixé code arduino
2016-03-16 Trajectoire prête (reste plus qu'à envoyer une liste de points)... un peu comme on a déterminé la liste des trésors etc.
2016-03-16 Bouton éventuellement connecté au robot. Il sera évidemment à modifier lors des tests.
2016-03-16 little fix for parameters
    [UARTDriver.py]
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2016-03-17 ajouts cricuits
    [Ampli.SchDoc, BorneChargement.PcbDoc, BorneChargement.PrjPcb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]
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
